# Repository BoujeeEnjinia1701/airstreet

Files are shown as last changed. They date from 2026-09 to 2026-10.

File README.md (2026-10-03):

# AirStreet

     

**Area:** Smart Cities · **TRL:** 3 of 9 (proof of concept on paper) · **Value-engineering target:** about $285 USD for the sensor head · **Difficulty:** 3 of 5

A street-level air quality node measuring PM2.5 and NO2, with particles checked on CalRig and NO2 calibrated against a reference station, for neighborhood-scale pollution maps.

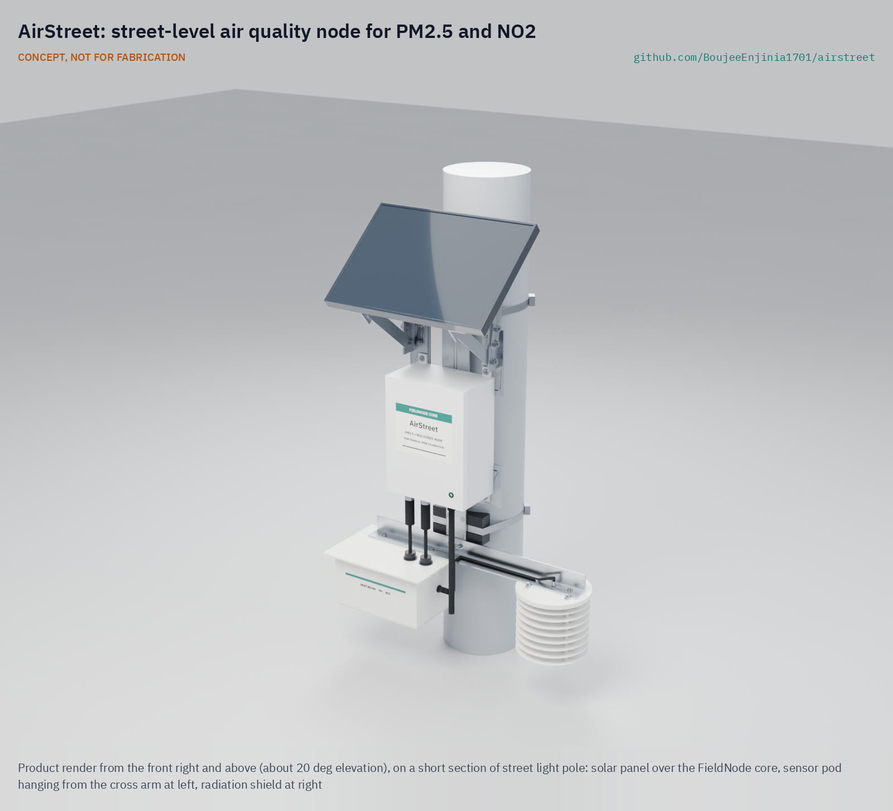
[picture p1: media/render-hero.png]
AirStreet: street-level air quality node for PM2.5 and NO2, product render


[Exploded render](media/render-exploded.png) · [Detail render](media/render-detail.png) · [Interactive 3D model](media/viewer.html) · [Concept blueprint (PDF)](media/concept-blueprint.pdf) · [General arrangement AST-DWG-001 (PDF)](cad/drawings/AST-DWG-001.pdf) · [Sizing calculations](docs/04-calcs/01-sizing.md) · [Prototype build plan](docs/05-build-plan.md) · [Design decisions](docs/06-design-decisions.md) · [Review note](docs/REVIEW.md)

## Concept rationale

Traffic pollution changes from one block to the next, so a map of it needs many measurement points at street level, each with a known calibration. AirStreet puts a small sensor pod and radiation shield under the lab's FieldNode solar core on a street light pole: an optical sensor for PM2.5, a four-electrode electrochemical sensor for NO2, and a shielded temperature and humidity sensor for corrections. Particle, temperature and humidity response are checked on CalRig. CalRig does not cover NO2, so each NO2 sensor is calibrated by field collocation with a reference station before deployment and at intervals afterward. The node sends raw signals so calibrations can be improved and reapplied.

It is open and garage-buildable because the places with the fewest official monitors are the least able to buy closed commercial networks and their subscriptions. The sensors are sold worldwide, the pod and shield are 3D-printed, the mount uses band clamps and flat bar, and the calibration method is published with the design so that others can check any map made with it.

## Burning platform

Air pollution is one of the largest environmental health risks worldwide. Ambient air pollution caused an estimated 4.2 million premature deaths in 2019 ([WHO](https://www.who.int/news-room/fact-sheets/detail/ambient-(outdoor)-air-quality-and-health)). Even in the European Union, with dense monitoring, 48,000 deaths in 2022 were attributable to NO2 above the WHO guideline level of 10 µg/m³ ([EEA, 2024](https://www.eea.europa.eu/en/analysis/publications/harm-to-human-health-from-air-pollution-2024)).

Monitoring misses the streets where exposure is highest. Reference-grade mapping in Oakland, California, found NO2 and black carbon varying by up to 5 to 8 times within single city blocks ([Apte et al., 2017](https://pubs.acs.org/doi/10.1021/acs.est.7b00891)), while monitoring is not legally required at all in at least 37 % of countries ([UNEP, 2021](https://www.unep.org/news-and-stories/press-release/one-three-countries-world-lack-any-legally-mandated-standards)).

## Where it could be used

### By industry

| Industry | Use |
| --- | --- |
| Municipal environment and transport | Before and after maps for low-traffic streets, school streets, bus corridors and clean air zones |
| Public health agencies | Street-level exposure data near schools, clinics and care homes, labeled as indicative |
| Street lighting and utilities | A light, self-powered add-on for existing poles that needs no pole wiring |
| Logistics and ports | Tracking NO2 and PM2.5 along freight routes and depot access roads |
| Universities and schools | Open, raw data and a documented calibration for teaching and exposure research |
| Community groups and NGOs | Evidence for local campaigns, with the calibration version stated on every map |

### By country or region

| Country or region | Why it matters there |
| --- | --- |
| United States | More than 45 million people live within about 90 m (300 ft) of a major transportation facility ([US EPA](https://www.epa.gov/air-research/research-near-roadway-and-other-near-source-air-pollution)); street-scale variation is well documented ([Apte et al., 2017](https://pubs.acs.org/doi/10.1021/acs.est.7b00891)) |
| European Union and United Kingdom | 48,000 deaths in the EU in 2022 were attributable to NO2 above the WHO guideline ([EEA, 2024](https://www.eea.europa.eu/en/analysis/publications/harm-to-human-health-from-air-pollution-2024)); dense reference stations make field collocation of NO2 practical |
| India | Only 12 % of 4,041 census cities and towns have air quality monitoring ([CSE, 2023](https://www.cseindia.org/only-12-per-cent-of-india-s-census-cities-and-towns-have-air-quality-monitoring-stations-11779)) |
| East Africa (Uganda, Kenya, Ethiopia, Tanzania) | Listed by OpenAQ in 2020 among populous countries with no public national monitoring program ([OpenAQ, 2020](https://documents.openaq.org/reports/Open+Air+Quality+Data+Global+State+of+Play+2020.pdf)); AirQo already runs more than 400 low-cost PM2.5 sensors across 14 African countries ([AirQo](https://www.airqo.net/)) |
| Pakistan and Nigeria | The two most populous countries on the same OpenAQ list, at about 221 million and 206 million people ([OpenAQ, 2020](https://documents.openaq.org/reports/Open+Air+Quality+Data+Global+State+of+Play+2020.pdf)); the first reference station for collocation may itself be scarce |

## What sparked the idea

The starting point was the inquest into the death of Ella Adoo Kissi-Debrah, a nine-year-old who lived near the busy South Circular Road in Lewisham, south-east London, and died in 2013. In December 2020 the coroner found that she died of asthma contributed to by exposure to excessive air pollution, and that nitrogen dioxide in Lewisham exceeded EU and UK legal limits ([CIEH, 2020](https://www.cieh.org/ehn/environmental-protection/2020/december/ella-adoo-kissi-debrah-verdict-shows-human-cost-of-air-pollution/)). His Prevention of Future Deaths report of 20 April 2021 also raised low public awareness of air quality information ([Courts and Tribunals Judiciary](https://www.judiciary.uk/prevention-of-future-death-reports/ella-kissi-debrah/); [IAQM](https://iaqm.co.uk/prevention-of-future-deaths-report-published-following-2013-death-of-ella-abdoo-kissi-debrah/)). The case turns on NO2 beside one busy road, which is the scale AirStreet is built to measure, and on making that information visible to the people who live there.

## Problem

Regulatory air monitors are few and far apart, missing the streets where people breathe traffic pollution. Full problem statement: [docs/01-problem.md](docs/01-problem.md).

## Concept

A street-level air quality node measuring PM2.5 and NO2, with particles checked on CalRig and NO2 calibrated against a reference station, for neighborhood-scale pollution maps. The sensor pod and radiation shield hang below a FieldNode core on a street light pole, with inlets 3.0 m above the sidewalk, and send one record every 5 min over LoRaWAN. PM, temperature and humidity are checked on CalRig; **NO2 is calibrated by field collocation with a reference station** for at least 14 days before deployment and at least every 6 months, because CalRig does not cover NO2.

Calculated performance (TRL 3, [AST-CAL-001](docs/04-calcs/01-sizing.md)): an 87 mW design sensor load with a 60 s particle run, within FieldNode's 100 mW design allowance, and 6.6 days without sun; records every 5 min through a private gateway and every 15 min on The Things Network; 0.60 % radio duty cycle even at SF12; hourly NO2 error of about 3.9 ppb and PM2.5 within ±5 µg/m³ or ±30 % up to 80 % RH. As made buildable for the prototype build plan, and lightened as decided on 2026-10-02 (40 x 4 mm rail, windows in the adapter plates, 1.5 mm shield plates, saddles at 40 % infill), the node weighs 3.62 kg and presents 0.139 m² to the street, and the sensor head costs $302.50 in parts ($433.50 with the FieldNode core). With FieldNode's sun shield the node weighs 3.78 kg, 0.22 kg under the 4.0 kg mass limit Amish set for R13 on 2026-10-02, and cost is $17.50 over the $285 value-engineering target (R15); both are covered in the [design decisions register](docs/06-design-decisions.md); five requirements are at risk. The annual NO2 uncertainty (about 4.2 µg/m³) is too large to resolve the WHO guideline of 10 µg/m³, so AirStreet ranks streets and checks the EU limit, and the WHO question is kept as research. Decisions are recorded in [AST-DDR-001](docs/decisions/0001-trl2-review-decisions.md), [AST-DDR-002](docs/decisions/0002-recommendations-accepted.md) and [AST-DDR-003](docs/decisions/0003-design-for-construction.md). Only pollutant levels, temperature and humidity leave the device; no images or audio.

Full design precis: [docs/02-concept.md](docs/02-concept.md). Requirements: [docs/03-requirements.md](docs/03-requirements.md).

## Key components

1. FieldNode core (enclosure, LiFePO4 cell, MPPT charger, LoRaWAN radio), on two adapter plates in place of its back plate
2. FieldNode 6 W panel hood
3. Bands, V-saddles, mounting rail, adapter plates and cross arm (no drilling)
4. Sensor pod (shell with drip lid, sensor floor, insect mesh), exchanged whole for service
5. Optical PM2.5 sensor (Sensirion SPS30 class)
6. Electrochemical NO2 sensor (Alphasense NO2-B43F class, ozone filtered)
7. NO2 potentiostat front end and 16-bit ADC
8. Multi-plate radiation shield
9. Temperature and humidity sensor (Sensirion SHT45 class)
10. Sensor cables with M12 plugs (0.5 m)

The priced bill of materials is in [bom/bom.csv](bom/bom.csv); the parametric model is `cad/src/model.py`, with STEP and STL exports in `cad/step/` and `cad/stl/`.

## Building the prototype

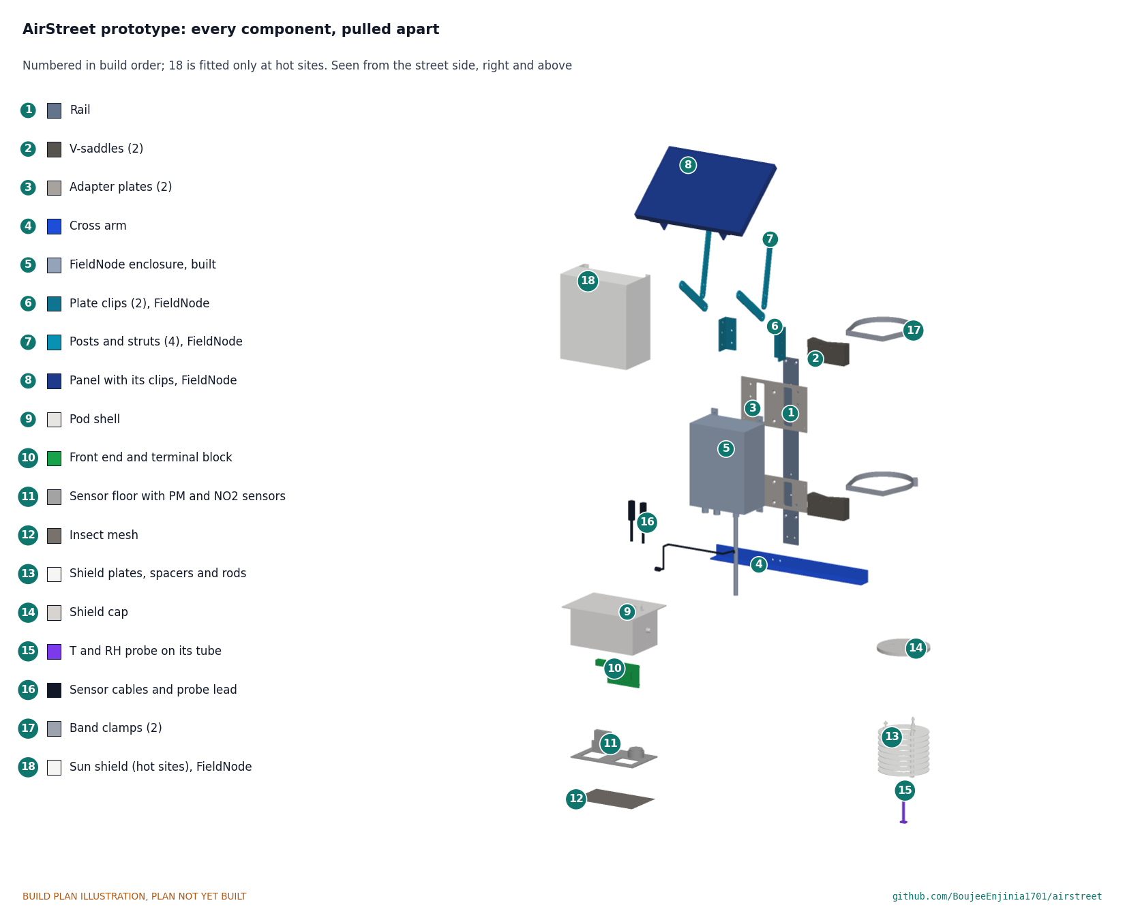
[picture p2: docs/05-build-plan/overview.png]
AirStreet prototype: every component pulled apart and numbered in build order


The [prototype build plan](docs/05-build-plan.md) (AST-BLD-001) shows, in pictures, how to make each of the eighteen components and put them together in sixteen steps; nothing has been built yet. The made parts are an aluminium rail, two adapter plates and a cross arm, and printed V-saddles, pod shell, sensor floor, shield plates and cap; the FieldNode core is built to FieldNode's own plan, and the sensors and front end are bought boards wired at block level. Writing the plan made the design buildable: the saddles, band path, enclosure fixing, pod, shield stack and cable entries were redesigned (AST-DDR-003, accepted by Amish on 2026-10-02), which raised the mass to its 4.0 kg limit and the cost above its value-engineering target; those choices are in the [design decisions register](docs/06-design-decisions.md). Every picture is drawn from the model, which checks that each part touches what it should and clears what it should not.

## Safety

> **Safety:** Street furniture and pole mounts must be installed only with the asset owner's permission, by trained crews, with fall protection and traffic management as local rules require. Never open a street light pole's access door or tap its mains supply; AirStreet runs only on its own solar and battery supply.
>
> The FieldNode core holds a lithium iron phosphate cell: fuse it and charge only within the maker's limits. Electrochemical gas sensors contain an acid electrolyte; do not open or heat them. AirStreet data are indicative, not a regulatory measurement or health advice.

## Repository layout

| Folder | Contents |
| --- | --- |
| `docs/` | Problem, concept, requirements, calculations and design decisions |
| `cad/src/` | build123d Python source, the source of truth for all geometry |
| `cad/step/`, `cad/stl/` | Exported models for FreeCAD, other CAD tools and printing |
| `cad/drawings/` | 2D sketches and dimensioned drawings |
| `bom/` | Bill of materials |
| `electronics/` | KiCad schematics and PCB layouts |
| `firmware/` | Microcontroller code |
| `media/` | Renders, perspectives and photos |
| `build-log/` | Dated prototyping notes |

## Documentation

Controlled documents follow the portfolio [documentation standard](.kit/STANDARDS.md). Each carries a document ID (AST-PRC-001 for the precis), a version and a revision history. Branded PDFs are built with `python .kit/render.py` and attached to GitHub Releases when a document is tagged, for example `AST-PRC-001/v1.0`.

## Credits

Designed by Amish Chadha. See [CONTRIBUTORS.md](CONTRIBUTORS.md) for roles. To cite this design, use [CITATION.cff](CITATION.cff) (GitHub shows it as "Cite this repository").

AI assistance (Claude) was used to accelerate concept renders, prototype documentation and first-pass sizing calculations. Design direction and all decisions are Amish Chadha's, recorded in this repository's decision records (`docs/decisions/`).

## Licenses

- **Hardware** (CAD, drawings, BOM, electronics): [CERN-OHL-S v2](LICENSE)
- **Software** (firmware, scripts, notebooks): [MIT](LICENSE-SOFTWARE)

A project of the [Design Molecule](https://designmolecule.com) lab.

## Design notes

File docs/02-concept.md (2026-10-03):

---
doc_id: AST-PRC-001
title: AirStreet design precis
project: AirStreet
doc_type: Design precis
version: "0.8"
status: Draft
date: '2026-10-02'
author: Amish Chadha
license: CERN-OHL-S-2.0
revisions:
- version: "0.1"
  date: '2026-09-25'
  author: Amish Chadha
  change: Initial scaffold
- version: "0.2"
  date: '2026-09-25'
  author: Amish Chadha
  change: Populate to TRL 2 (architecture, components, calibration route, first-order numbers, safety)
- version: "0.3"
  date: '2026-09-25'
  author: Amish Chadha
  change: TRL 3 update from AST-CAL-001, the parametric model and AST-DWG-001; design choices adopted for TRL 3 work per AST-DDR-001, open for Amish's review
- version: "0.4"
  date: '2026-09-25'
  author: Amish Chadha
  change: Recommendations accepted by Amish (DDR-002)
- version: "0.5"
  date: '2026-09-30'
  author: Amish Chadha
  change: Design made constructable (AST-DDR-003); mount, pod, shield, mass, area and cost figures updated
- version: "0.6"
  date: '2026-10-01'
  author: Amish Chadha
  change: Budget treated as a value-engineering target
- version: "0.7"
  date: '2026-10-02'
  author: Amish Chadha
  change: "Decisions of 2026-10-02: R13 limit 4.0 kg with the sun shield; first partner rule and first candidate; radio band follows the partner"
- version: "0.8"
  date: '2026-10-02'
  author: Amish Chadha
  change: "Lightening steps of AST-DDR-003 A1 carried into the design (AST-CAL-001 v0.6): 40 x 4 mm rail, plate windows, 1.5 mm shield plates, saddles at 40 % infill; R13 met on paper; mass, area, wind, shield and cost figures updated"
---

# AirStreet design precis

## Summary

AirStreet is a pole-mounted node that measures PM2.5 and NO2 at street level for neighborhood-scale pollution maps. A small sensor pod and a radiation shield hang below a FieldNode core on a street light pole, with the inlet plane 3.0 m above the sidewalk. Temperature, humidity and particle readings are checked on CalRig. CalRig does not cover NO2, so each NO2 sensor is calibrated by field collocation with a reference station before deployment and at intervals afterward. The node sends raw signals, so calibrations can be improved and reapplied later. Amish accepted the recommended design choices on 2026-09-25 ([AST-DDR-001](decisions/0001-trl2-review-decisions.md), [AST-DDR-002](decisions/0002-recommendations-accepted.md)).

The TRL 3 calculations ([AST-CAL-001](04-calcs/01-sizing.md) v0.6) confirm the power and radio budget: an 87.0 mW design sensor load with a 60 s particle run, inside FieldNode's 100 mW design allowance, 6.6 days without sun, and 0.60 % duty cycle even at SF12. On 2026-09-30 the design was made constructable ([AST-DDR-003](decisions/0003-design-for-construction.md)) and an illustrated prototype build plan was written ([AST-BLD-001](05-build-plan.md)). With the four lightening steps accepted on 2026-10-02 (a 40 x 4 mm rail, windows in the adapter plates, 1.5 mm shield plates and saddles printed at 40 % infill), the buildable node weighs 3.62 kg and presents 0.139 m² to the street, which meets its 0.15 m² area limit; with FieldNode's sun shield it weighs 3.78 kg, 0.22 kg under the 4.0 kg limit that Amish set for R13 on 2026-10-02 (it was 3.5 kg), so R13 is met on paper; the pole owner is still to confirm the load. Value-engineering target: USD 285. Estimated cost of the constructable design: USD 302.50 (USD 17.50 over the target) for the sensor head (R15). Decisions are recorded in the design decisions register ([AST-DEC-001](06-design-decisions.md)). The node costs $433.50 with the FieldNode core. Resolving NO2 at the WHO guideline of 10 µg/m³ is no longer a requirement: an annual mean carries about 4.2 µg/m³ of uncertainty, so AirStreet ranks streets and checks the EU limit, and the WHO question stays open as research.

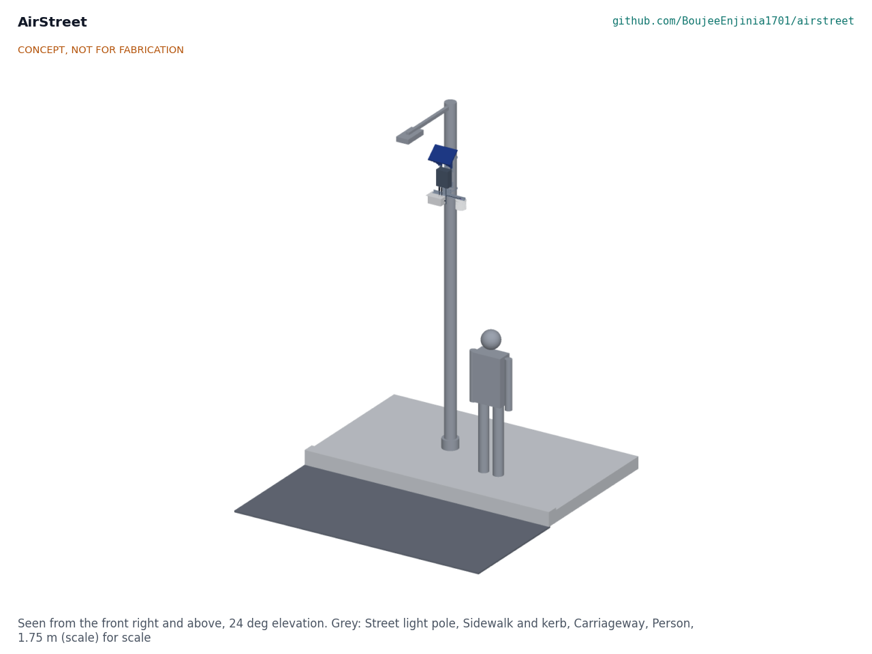
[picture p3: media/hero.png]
Figure 1. AirStreet on a street light pole, with a 1.75 m person for scale.


Figure 1. AirStreet on a street light pole, with a 1.75 m person for scale (concept, not for fabrication).

## How it works

1. Street air enters the sensor pod from below, through stainless insect mesh under an overhanging drip lid. Downward-facing inlets keep rain and direct sun out.
2. An optical particle sensor draws a sample with its own fan for 60 s every 5 min and counts particles by laser scattering, giving PM1, PM2.5 and PM10. The SPS30 needs 8 to 30 s to its first reading, depending on particle count, so the 60 s run leaves at least 30 s of valid readings to average even in clean air (AST-DDR-002).
3. A four-electrode electrochemical NO2 sensor with an ozone filter faces down through a slot in the pod floor. Its working electrode (WE) responds to NO2, and its auxiliary electrode (AE) tracks the temperature-driven baseline. A potentiostat front end holds the bias continuously, and a 16-bit ADC reads both signals.
4. A temperature and humidity sensor sits inside a white multi-plate radiation shield beside the pod, so readings reflect air temperature rather than sun-heated plastic. These values drive the humidity correction for PM and the temperature correction for NO2.
5. Two short cables with M12 plugs run up to FieldNode's two sensor ports. Port A, on a switched 5 V rail, carries the PM sensor and the temperature and humidity sensor on one I2C bus and is powered only during each PM run. Port B carries the NO2 front end on a 5 V rail that stays on, because the sensor bias must be held continuously. FieldNode provides power, storage and a LoRaWAN radio, and its 6 W panel shades the enclosure.
6. Every 5 min through a private gateway (the TwinKit gateway by default), or every 15 min on The Things Network, the node sends one record of 20 bytes: raw PM values, raw WE and AE voltages, temperature, humidity, a status word, a counter and flags. It never sends images, audio or identifiers of people.
7. A server-side calibration model converts raw values to PM2.5 and NO2 concentrations. Each model is versioned and linked to the node's CalRig record and its collocation record, so any map can be traced to the calibration behind it.

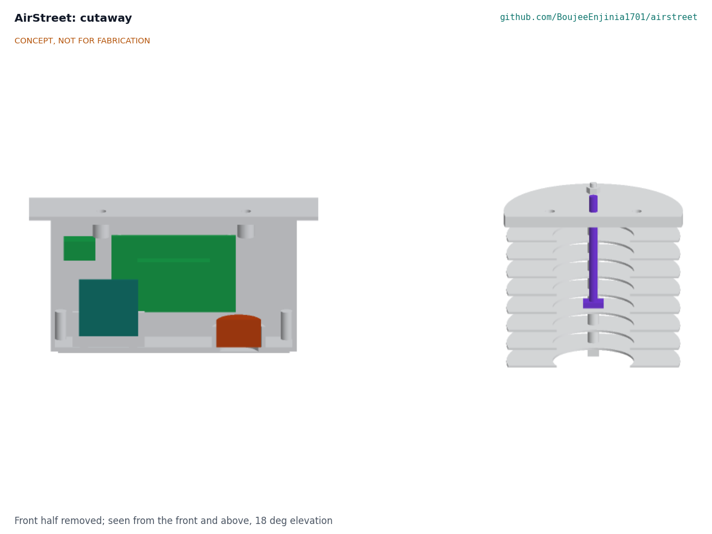
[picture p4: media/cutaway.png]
Figure 2. Cutaway of the sensor pod and radiation shield.


Figure 2. Cutaway of the sensor pod (PM sensor, NO2 sensor and front end) and the radiation shield.

## Main components

Item numbers match the BOM ([bom/bom.csv](../bom/bom.csv)), the exploded view (Figure 3) and the parametric model `cad/src/model.py`. The general arrangement is drawing AST-DWG-001 (`cad/drawings/`).

Table 1. Main components.

| No. | Component | Key choice (decided by Amish, 2026-09-25) |
| --- | --- | --- |
| 1 | FieldNode core | Shared lab core per FND: IP65 enclosure 150 x 90 x 200 mm, LiFePO4 cell, MPPT charger, STM32WL LoRaWAN, two M12 5-pin sensor ports; the enclosure, built to FieldNode's constructable design, fixes by its four lugs to two adapter plates on the AirStreet rail, and FieldNode's back plate, V-blocks and 40 to 60 mm clamps are not used (DDR-002, DDR-003); FieldNode's sun shield is fitted at sites above 45 °C |
| 2 | FieldNode 6 W panel hood | Part of FieldNode; 40° tilt toward the street side as a sun and rain hood |
| 3 | Band clamps and mounting rail | Two 12.7 mm stainless bands cut to length, 375 mm apart, each running in a groove behind a printed 140° V-saddle that seats 80 to 200 mm poles; 40 x 4 mm aluminium rail 451 mm long; two 3 mm aluminium adapter plates with FieldNode's back plate hole pattern and lightening windows; a 30 x 30 x 3 mm cross arm that carries the pod and the shield (DDR-002, DDR-003); no drilling |
| 4 | Sensor pod | Printed ASA shell with walls, roof and 200 x 140 mm drip lid in one, 170 x 110 x 95 mm with its sensor floor, which carries both sensors and closes the pod from below behind mesh; hung under the cross arm 90 mm to one side so the FieldNode whip hangs beside it with 15 mm clearance; the pod with its sensors and front end is the service exchange unit (DDR-002) |
| 5 | Optical PM sensor | Sensirion SPS30 (D6); the maker states a lifetime of more than ten years ([Sensirion](https://sensirion.com/products/catalog/SPS30)) |
| 6 | Electrochemical NO2 sensor | Alphasense NO2-B43F class (D4): four electrodes and an ozone filter; replace about every 2 years (estimate) |
| 7 | NO2 front end and ADC | Alphasense ISB class potentiostat bought for the first units (D5), with an ADS1115 class 16-bit ADC |
| 8 | Radiation shield | Eight white 120 mm plates at 13 mm pitch on three rods with spacers, 124 mm cap screwed under the cross arm, naturally ventilated |
| 9 | Temperature and humidity sensor | Sensirion SHT45 on a probe board, hung in the shield on a 6 mm tube |
| 10 | Sensor cables | Two 0.5 m shielded cables with M12 plugs into glands in the pod roof; probe lead with an M8 plug for the pod wall |
| 11 | Fasteners and consumables | Not modeled |

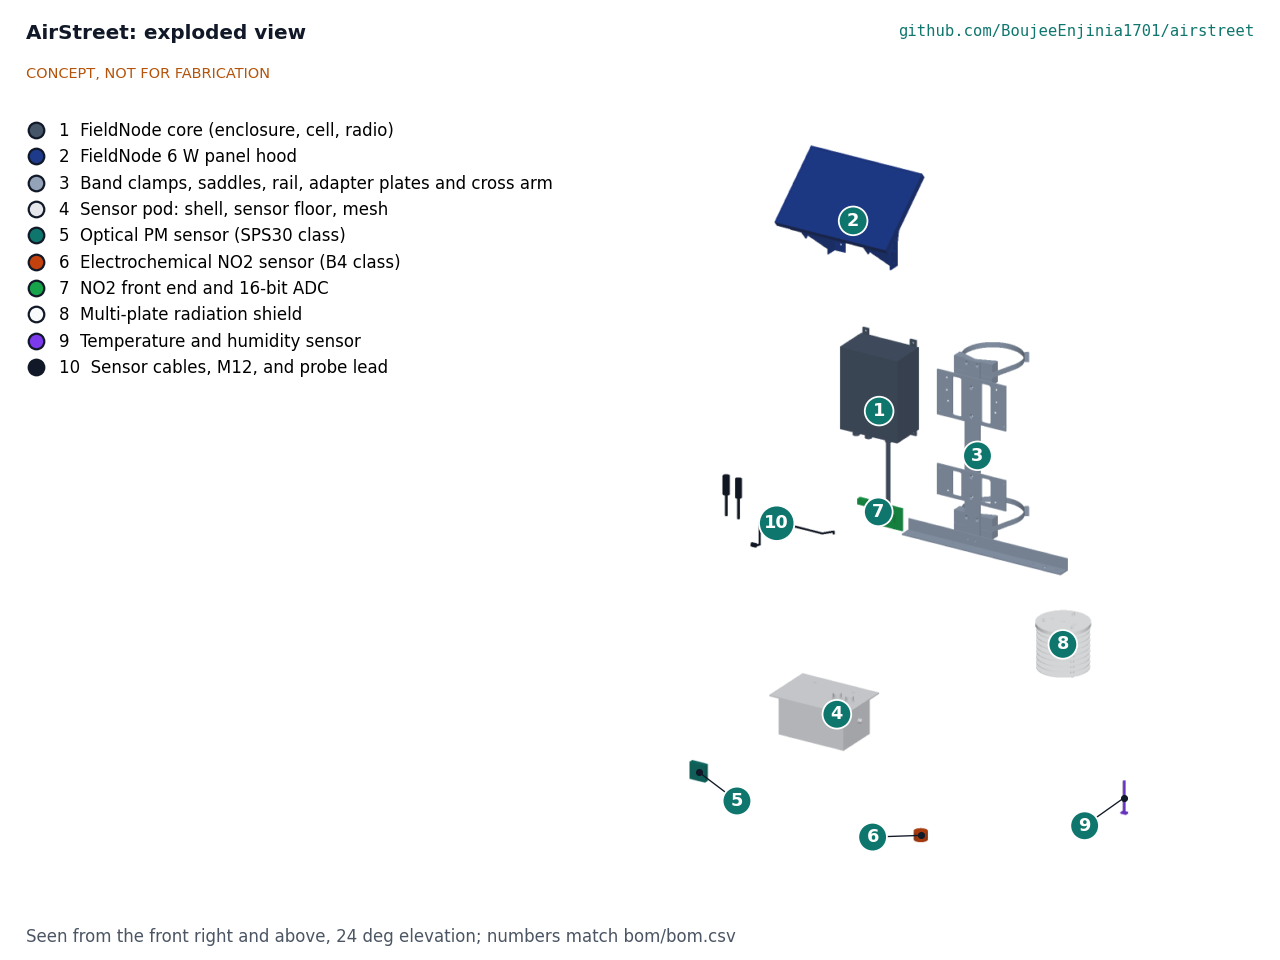
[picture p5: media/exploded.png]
Figure 3. Exploded view with BOM numbers.


Figure 3. Exploded view with BOM numbers.

## Key design choices

Amish accepted every recommendation below on 2026-09-25 (AST-DDR-001 D1 to D9 and AST-DDR-002). Purchasing, collocation and publication of data are TRL 4 and later work and are on hold.

- **Build on FieldNode.** AirStreet designs only the sensor head, its mount and the calibration route. Power, radio and enclosure fixes found in other deployments carry over. The FieldNode core is costed in FieldNode, and AirStreet's value-engineering target covers the sensor head (D1).
- **Two calibration routes, stated plainly.** CalRig checks temperature, humidity and particle response in a chamber. NO2 is calibrated by field collocation with a regulatory reference station (chemiluminescence), because field calibration corrects temperature, humidity and cross-sensitivity effects that laboratory calibration misses ([Zimmerman et al., 2018](https://amt.copernicus.org/articles/11/291/2018/)). This follows the approach of the US EPA NO2 sensor protocols, which include field evaluation alongside regulatory monitors ([US EPA](https://www.epa.gov/air-sensor-toolbox/air-sensor-performance-targets-and-testing-protocols)).
- **Collocation plan (D3).** Each node sits beside a reference station for at least 14 days before deployment, covering a range of temperature, humidity and NO2. At least one anchor node stays at the reference site permanently to track seasonal drift, and every node returns for collocation at least every 6 months. The first model is a multiple linear regression on WE, AE, temperature and humidity, with a random forest model as an option once enough data exist.
- **Send raw signals (D8).** Raw WE and AE voltages and raw PM values let the city or community reprocess data when a better model or a new collocation becomes available.
- **Four-electrode NO2 sensor with ozone filter (D4).** The auxiliary electrode helps remove the temperature-driven baseline, and the filter reduces ozone interference.
- **Duty-cycled PM sensor (D8, run length per DDR-002).** Running the particle sensor for 60 s every 5 min gives a valid reading even in clean air, keeps its average draw near 55 mW and slows fouling.
- **Reporting by network (DDR-002).** 5 min records through the private TwinKit gateway; 15 min on The Things Network, which keeps within its 30 s/day fair-use policy up to SF9.
- **Pod exchange for service (DDR-002).** The whole pod, pre-collocated at the reference site, is exchanged at the pole; sensors are never swapped at height.
- **No FieldNode back plate (DDR-002).** The FieldNode enclosure and its panel bracket fix to two adapter plates on the AirStreet rail (AST-DDR-003), saving about 0.15 kg against FieldNode's back plate. This changes the FieldNode mounting interface and needs FieldNode's agreement.
- **Hot sites (DDR-002).** FieldNode's sun shield is required at any site where ambient temperature exceeds 45 °C.
- **WHO guideline as research (DDR-002).** AirStreet ranks streets and checks the EU limit; it makes no claim about the WHO annual guideline for NO2.
- **Inlets 3.0 m above the sidewalk (D7).** This is within the 1.5 to 4 m inlet range in EU Directive 2008/50/EC ([EUR-Lex](https://eur-lex.europa.eu/legal-content/EN/TXT/HTML/?uri=CELEX:32008L0050)) and out of easy reach.
- **Open data (D9).** Calibrated hourly data, with the calibration version, are published to an open platform such as OpenAQ, subject to the partner's agreement.

## Key numbers (TRL 3)

All values come from AST-CAL-001, which lists every assumption.

Table 2. Key numbers.

| Quantity | Value | Note |
| --- | --- | --- |
| PM sensor average power | 55.0 mW typical, 65.0 mW maximum | SPS30 55 mA typical, 65 mA maximum at 5 V (datasheet), 60 s in every 300 s |
| NO2 front end and ADC | 7.5 mW | 1.5 mA at 5 V held continuously (assumed) |
| Design sensor load | 87.0 mW | Maximum SPS30 current and 1.2 margin; FieldNode allows 100 mW (design) or 115 mW (ceiling) (R9 met on paper) |
| Daily draw and autonomy | 2.33 Wh/day; 6.6 days without sun | 4.6 days at -20 °C; 7.75 Wh stored in FieldNode's worst month |
| Payload and airtime | 20 bytes every 5 min (15 min on TTN); 247 ms at SF9, 1.81 s at SF12 | 0.082 % and 0.60 % duty cycle (R10 met on paper); at 15 min, TTN's 30 s/day fair use is met up to SF9 (23.7 s/day) |
| NO2 hourly error | About 3.9 ppb MAE (7.4 µg/m³) | Budget of literature and assumed terms (R2 at risk) |
| NO2 annual uncertainty | About 4.2 µg/m³ (1σ) | Too large to resolve the 10 µg/m³ WHO guideline; R3 withdrawn and kept as a research question |
| EU limit classification | Decisive below 34.6 or above 45.4 µg/m³ | 90 % confidence against 40 µg/m³ (R4 at risk) |
| PM2.5 hourly error | Within ±5 µg/m³ or ±30 % up to 80 % RH | Outside the bound at 85 % RH and above (R1 at risk) |
| Shield radiation error | 0.42 to 0.87 K at 1 m/s | Reads up to 4.1 % RH low at 85 % RH (R5 at risk) |
| Mass on the pole | 3.62 kg | FieldNode 1.89 kg as used (no back plate), sensor head and mount 1.73 kg, with the four lightening steps (3.78 kg with the sun shield against the 4.0 kg R13 limit set on 2026-10-02; R13 met on paper, AST-DDR-003 A1) |
| Frontal area | 0.139 m² | Rasterized from the model; limit 0.15 m² (met on paper) |
| Wind at 35 m/s | 125 N, 416 N·m at the pole base | Clamp slip factor 25; the pole check is the owner's |
| Parts cost | Sensor head $302.50; $433.50 with the FieldNode core | $17.50 over the $285 value-engineering target (`budget_usd`; R15 over the target) |
| Service | About 14 min for a pod exchange | Against 15 min (R16 met on paper) |

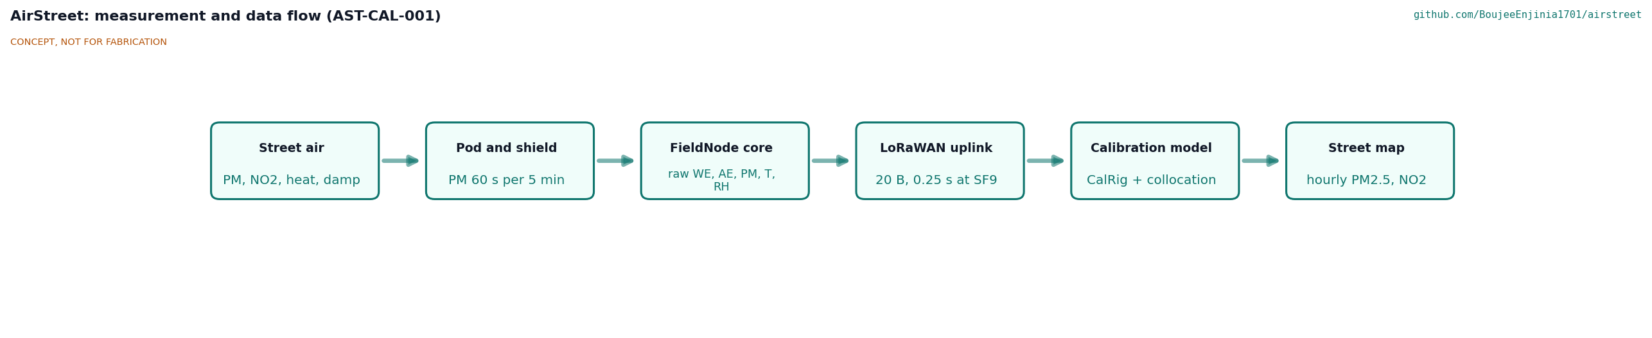
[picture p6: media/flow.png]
Figure 4. Measurement and data flow.


Figure 4. Measurement and data flow.

## Safety

> **Safety:** Mounting on a street pole is work at height next to traffic. Install only with the pole owner's written permission, by trained crews using a mobile elevating work platform or a secured ladder with a second person, with traffic management as local rules require. The node adds about 125 N of wind load and about 416 N·m at the pole base in a 35 m/s gust, and up to 4.0 kg of weight; the pole owner must confirm the pole can carry it.

> **Safety:** Street light poles carry mains voltage inside. Never open the pole's access door or tap pole power; AirStreet runs only on its own solar and battery supply.

> **Safety:** The FieldNode core holds a lithium iron phosphate cell. Use a fused, protected cell, charge only within the maker's temperature limits and replace any swollen or damaged cell. FieldNode is rated for ambient temperatures up to 45 °C; hotter sites must have FieldNode's sun shield fitted (AST-DDR-002).

> **Safety:** Electrochemical gas sensors contain an acid electrolyte. Do not open, crush or heat them; dispose of them as the maker directs. Band clamp ends and cut flat bar have sharp edges; deburr them and wear gloves. Band clamps rely on their preload; installers need a torque figure before any field use.

> **Safety:** AirStreet data are indicative and are not a regulatory measurement or health advice. Maps must state the calibration version and its uncertainty.

## Open questions

- [ ] Which city, partner and reference station host the first collocation? Decided on 2026-10-02 as a rule: a city or air agency that runs a regulatory NO2 reference station at a street-level site AirStreet can mount beside, and that will share its data. First candidate to approach: the Texas Commission on Environmental Quality's Dallas-Fort Worth monitoring network, with a local university or city partner; nothing is agreed yet. The partner's country sets the radio band (US915 in North America, EU868 in Europe).
- [ ] Is the NO2 error after field calibration stable across seasons, and how large is the reference-to-street transfer bias in practice?
- [ ] How fast does air move inside the shield in low wind, and so how large is the radiation error?
- [ ] Does the SPS30 need a heated or dried inlet above 85 % RH, or is a humidity flag on the data enough?
- [ ] Will FieldNode accept its enclosure, plate clips and sun shield on AirStreet's two adapter plates in place of its back plate? (Decided in AirStreet, AST-DDR-002 and AST-DDR-003; on 2026-10-02 Amish approved sending FieldNode the request; FieldNode's agreement is outstanding.)
- [ ] Can the NO2 annual mean ever be resolved at the WHO guideline, for example with an anchor node at every site? (Research question, AST-DDR-002.)
- [ ] Is an open two-channel front end at about $25 worth designing, to restore cost margin? (On hold with TRL 4.)
- [ ] How are nodes secured against theft, and what does the pole owner require for insurance and inspection?

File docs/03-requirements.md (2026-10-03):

---
doc_id: AST-REQ-001
title: AirStreet requirements
project: AirStreet
doc_type: Requirements
version: "0.8"
status: Draft
date: '2026-10-02'
author: Amish Chadha
license: CERN-OHL-S-2.0
revisions:
- version: "0.1"
  date: '2026-09-25'
  author: Amish Chadha
  change: Initial scaffold
- version: "0.2"
  date: '2026-09-25'
  author: Amish Chadha
  change: First measurable requirements for TRL 2, with status against the concept
- version: "0.3"
  date: '2026-09-25'
  author: Amish Chadha
  change: TRL 3 status from AST-CAL-001; R15 redefined as the sensor-head cost (AST-DDR-001 D1); R6, R8 and R11 rest on adopted choices
- version: "0.4"
  date: '2026-09-25'
  author: Amish Chadha
  change: Recommendations accepted by Amish (DDR-002)
- version: "0.5"
  date: '2026-09-30'
  author: Amish Chadha
  change: Status from AST-CAL-001 v0.3 after the design was made constructable (AST-DDR-003); R13 and R15 not met, proposed to Amish
- version: "0.6"
  date: '2026-10-01'
  author: Amish Chadha
  change: Budget treated as a value-engineering target
- version: "0.7"
  date: '2026-10-02'
  author: Amish Chadha
  change: "R13 mass limit set at 4.0 kg including FieldNode's sun shield (AST-DDR-003 A1, accepted 2026-10-02); R13 now at risk"
- version: "0.8"
  date: '2026-10-02'
  author: Amish Chadha
  change: "Status from AST-CAL-001 v0.6 with the four lightening steps carried into the design: R13 at risk to met on paper (3.78 kg with the sun shield); R15 over the target by $17.50; R5 figures updated"
---

# AirStreet requirements

These requirements are checked by calculation in [AST-CAL-001](04-calcs/01-sizing.md) v0.6. Targets remain proposals for review with the first co-design partner. On 2026-09-25 Amish accepted the recommendations in [AST-DDR-001](decisions/0001-trl2-review-decisions.md) and [AST-DDR-002](decisions/0002-recommendations-accepted.md). As a result R3 is withdrawn and kept as a research question, R8, R12, R13, R15 and R16 are restated, and R15 uses the $285 `budget_usd`. On 2026-09-30 the design was made constructable ([AST-DDR-003](decisions/0003-design-for-construction.md)), which raised the mass and the sensor-head cost: R15 (cost) is **over the value-engineering target**, now by $17.50. On 2026-10-02 Amish accepted the design for construction and set R13's mass limit at 4.0 kg including FieldNode's sun shield (AST-DEC-001, decision of 2026-10-02 on mass), with the four lightening steps carried into the design. With them the node weighs 3.78 kg with the sun shield, so R13 is met on paper with 0.22 kg of margin (it was at risk, on its limit, before the lightening). Five are at risk, five are met on paper, four are met by design, one is over the value-engineering target and one is withdrawn.

Table 1. Requirements.

| ID | Requirement | Target | Verification (TRL 3 or later) | Status at TRL 3 (AST-CAL-001) |
| --- | --- | --- | --- | --- |
| R1 | Measure PM2.5 at street level | 0 to 500 µg/m³; hourly mean after humidity correction within ±5 µg/m³ or ±30 % (whichever is larger) of a collocated reference | CalRig chamber check, then field collocation | At risk: within the bound up to 80 % RH; outside it above 85 % RH, where water uptake makes the correction uncertain (AST-CAL-001 E) |
| R2 | Measure NO2 at street level | 0 to 200 ppb (about 0 to 380 µg/m³); hourly mean absolute error 5 ppb or less against a reference station after field calibration | Field collocation with a chemiluminescence reference station | At risk: hourly MAE about 3.9 ppb from a budget of literature and assumed terms (AST-CAL-001 C) |
| R3 | Resolve NO2 near the WHO annual guideline | Withdrawn as a requirement (AST-DDR-002). Kept as a research question: can the annual mean be resolved to 2 µg/m³ at 10 µg/m³? | Collocation statistics (research) | Withdrawn. Annual uncertainty about 4.2 µg/m³ (1σ); AirStreet ranks streets and checks the EU limit (R4) and makes no WHO guideline claim |
| R4 | Distinguish streets that exceed the EU NO2 limit value | Classify annual means above or below 40 µg/m³ with 90 % confidence | Collocation statistics | At risk: decisive only for annual means below 34.6 or above 45.4 µg/m³ |
| R5 | Measure temperature and humidity for corrections | ±0.5 °C and ±3 % RH inside the shield; radiation error 1 °C or less in full sun at 1 m/s wind | CalRig chamber check; side-by-side field test against an aspirated reference | At risk: SHT45 meets the sensor figures; shield error 0.42 to 0.87 K at 1 m/s, which reads 4.1 % RH low at 85 % RH |
| R6 | Calibrate with a stated method | T, RH and PM checked on CalRig before deployment; NO2 collocated with a reference station for at least 14 days before deployment and at least every 6 months | Calibration record per node | Met by design (AST-DDR-001 D3) |
| R7 | Keep raw data for recalibration | Send raw NO2 working and auxiliary electrode signals, PM, T and RH with a calibration version tag | Firmware and data schema review | Met by design |
| R8 | Report often enough for street maps | One record every 5 min through a private gateway (TwinKit by default); one every 15 min on The Things Network; hourly means published within 15 min; 7 days of store and forward | Timing, airtime and storage calculation | Met on paper: 5 min records on the private gateway; at 15 min TTN fair use is met up to SF9; 7 days in 40.3 kB |
| R9 | Fit the FieldNode power budget | Sensor average 115 mW or less; energy neutral at the FieldNode design sun hours | Power budget calculation | Met on paper: 87.0 mW design load with the 60 s PM run; 2.33 Wh/day drawn against 7.75 Wh stored in the worst month; 6.6 days without sun |
| R10 | Stay within radio duty-cycle rules | LoRaWAN airtime below 1 % in EU868 sub-bands | Airtime calculation | Met on paper: 0.082 % at SF9, 0.60 % at SF12 |
| R11 | Mount on street poles without drilling | Poles 80 to 200 mm diameter; band clamps only; inlets between 1.5 and 4 m above ground | Design review | Met by design (inlet 3.0 m, AST-DDR-001 D7; 140° V-saddles and bands cut to length fit the range, AST-DDR-003) |
| R12 | Survive outdoors | Pod inlets face down behind insect mesh with drip lid; electronics in the FieldNode IP65 enclosure; -10 to 50 °C, with FieldNode's sun shield required at sites where ambient exceeds 45 °C | Design review, later field trial | At risk: the FieldNode sun shield is now designed (FND-DDR-003) and fixes to AirStreet's adapter plates (AST-DDR-003); SPS30 recommended range 20 to 80 % RH; condensation and insects unverified |
| R13 | Light and compact on the pole | Mass 4.0 kg or less including FieldNode's sun shield (relaxed from 3.5 kg, AST-DDR-003 A1, 2026-10-02; the pole owner is asked to confirm the load); frontal area 0.15 m² or less (relaxed from 0.12 m², AST-DDR-002) | Constructable model; weighing at TRL 4 | Met on paper: 3.78 kg with FieldNode's sun shield (3.62 kg without) against 4.0 kg, 0.22 kg margin, with the four lightening steps in the design; frontal area 0.139 m²; the pole owner's confirmation of the load is still to come |
| R14 | Collect levels only | No images, audio or personal identifiers collected or sent | Design review | Met by design |
| R15 | Low cost | AirStreet sensor-head parts at or under the $285 value-engineering target per node (`budget_usd`, a hypothetical control target); FieldNode core excluded and costed in FieldNode | Priced BOM (AST-CAL-001 I) | **Over the value-engineering target by $17.50**: sensor head $302.50; $433.50 with the FieldNode core (AST-DDR-003) |
| R16 | Serviceable in the field | Pre-collocated sensor pod exchanged in 15 min at the pole with hand tools; no sensor-level swaps at the pole (AST-DDR-002) | Design review | Met on paper: about 14 min for a pod exchange; the exchanged pod is serviced and recollocated at the reference site |

## Assumptions

- NO2 conversions use 1 ppb = 1.88 µg/m³ at 25 °C and 101.325 kPa.
- The WHO guideline level for annual NO2 is 10 µg/m³ and for PM2.5 is 5 µg/m³, as cited by the European Environment Agency ([EEA, 2024](https://www.eea.europa.eu/en/analysis/publications/harm-to-human-health-from-air-pollution-2024)). The EU annual limit value for NO2 is 40 µg/m³ under Directive 2008/50/EC, which also sets sampling inlets between 1.5 m and 4 m above ground ([EUR-Lex](https://eur-lex.europa.eu/legal-content/EN/TXT/HTML/?uri=CELEX:32008L0050)).
- FieldNode allows 115 mW average for sensors at its 5-day autonomy ceiling, with 100 mW proposed as its published design value (FND-CAL-001); AirStreet fits either.
- `budget_usd` in `project.yaml` is $285 for the sensor head (AST-DDR-002).
- R1 and R2 targets are proposals for review, set with reference to published field results; they are not taken from a standard.

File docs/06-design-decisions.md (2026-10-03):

---
doc_id: AST-DEC-001
title: AirStreet design decisions register
project: AirStreet
doc_type: Design decisions register
version: "0.4"
status: Draft
date: '2026-10-02'
author: Amish Chadha
license: CERN-OHL-S-2.0
revisions:
- version: "0.1"
  date: '2026-09-30'
  author: Amish Chadha
  change: Register opened with the open decisions from REVIEW.md, the decision records and the build plan work
- version: "0.2"
  date: '2026-10-01'
  author: Amish Chadha
  change: Budget treated as a value-engineering target
- version: "0.3"
  date: '2026-10-02'
  author: Amish Chadha
  change: "Amish approved the recommendations for open decisions 1 to 8 (2026-10-02); moved to decisions made (AST-DDR-003 accepted)"
- version: "0.4"
  date: '2026-10-02'
  author: Amish Chadha
  change: "Value engineering restated after the A1 lightening (USD 302.50, USD 17.50 over); actions that carry the 2026-10-02 decisions outside the design listed"
---

# AirStreet design decisions register

Every design decision still to be made, and every decision made, in one place. Each decision is argued in full in its decision record under `docs/decisions/`; this register is the index Amish works from. The build plan (`docs/05-build-plan.md`) describes the design as it stands and does not list open decisions.

## Open decisions

None. All open decisions were decided on 2026-10-02.

## To confirm when parts are bought

| # | What to confirm | Why it matters | Source |
| --- | --- | --- | --- |
| 1 | The band roll and housings close round both an 80 mm and a 200 mm pole with the saddle, and the band maker's torque for about 1,000 N of preload | The slip and twist checks assume 1,000 N per band | AST-CAL-001 [F7], [G2] |
| 2 | The NO2 front end board's size and mounting holes (model: 86 x 55 mm, holes 76 x 43 mm apart) and how the B4 sensor connects to it | They set the back wall bosses and the lead length to the sensor | AST-DDR-003, P8 |
| 3 | The particle sensor's interface select pin and logic levels on its datasheet | Sets the terminal block wiring | Build plan section 3.10 |
| 4 | Heat-set insert sizes (M5 and M3) and the hole size their maker gives | The printed holes are drawn 6.8 and 4.0 mm | AST-DWG-102, 106, 109 |
| 5 | The M8 4-pin socket's panel hole and the M16 glands' hole size | The pod's printed holes are 8.2 and 16.2 mm | AST-DWG-106 |
| 6 | FieldNode's enclosure lug kit positions match FieldNode's back plate pattern | The adapter plates copy that pattern | FND-DDR-003 |
| 7 | The FieldNode panel's frame has a flat back lip at least 12 mm wide | FieldNode's panel clips bolt through it | FND-DDR-003 |

## Value engineering

Value-engineering target: USD 285. Estimated cost of the constructable design: USD 302.50 (USD 17.50 over the target).

The target is `budget_usd`, a hypothetical control target, not a limit, and covers the sensor head only; with the FieldNode core, which is costed in FieldNode, the node is USD 433.50. Main cost drivers and savings worth trying:

- The rise from USD 285 came from making the design constructable (AST-DDR-003): line 3, band stock, adapter plates and cross arm (USD 4.50, after the A1 lightening: the thinner rail saves about USD 0.50 and the saddles are repriced at about USD 3.00 of filament at 40 % infill); line 9, probe tube (USD 1); line 10, probe lead with its M8 plug (USD 4); and line 11, inserts, glands, probe socket, terminal block and fixings (USD 8). Line 8 is back to USD 9.00: the 1.5 mm shield plates save about as much filament as the spacers use.
- Savings worth trying: the open two-channel NO2 front end (about USD 35 cheaper, PCB work that is on hold with TRL 4) would recover the USD 17.50, and cheaper band hardware and fixings can be sought at purchase.

## Actions that carry the decisions outside the design

These follow from decisions already made; none is an open decision.

| # | Action | Who | From |
| --- | --- | --- | --- |
| 1 | Ask the pole owner of the first site to confirm a load of 4.0 kg on the pole (3.78 kg with the sun shield as designed) and about 125 N of wind load 3.3 m up | Amish, once a site is chosen | Mass decision (R13), 2026-10-02 |
| 2 | Approach the first candidate partner, the Texas Commission on Environmental Quality's Dallas-Fort Worth monitoring network, with a local university or city partner; nothing is agreed yet | Amish | First partner decision, 2026-10-02 |
| 3 | When the partner is agreed, fix the radio band and FieldNode antenna in the BOM; for US915, restate R10 against the 400 ms dwell limit (SF9 or lower) | Next design update after the partner is agreed | Radio band decision, 2026-10-02 |
| 4 | Send FieldNode the adapter plate request and track its confirmation of port B's always-on 5 V and the 5 min private-gateway interval | Cross-repo (see REVIEW.md) | Decisions of 2026-10-02 on FieldNode |
| 5 | Propose the common M12 pin assignment to FieldNode, with CurbCount; once FieldNode agrees, update the pod wiring in build plan section 3.10 and its wiring picture | Cross-repo (see REVIEW.md) | Pin assignment decision, 2026-10-02 |
| 6 | Check LoRaWAN signal strength with the pod fitted; move the pod 8 mm left in the model and pictures only if the check shows a loss | TRL 4 (on hold) | Antenna whip decision, 2026-10-02 |

## Decisions made

| Date | Decision | Decided by | Record |
| --- | --- | --- | --- |
| 2026-09-25 | TRL 2 review items D1 to D9: budget covers the sensor head only; pitch wording; NO2 collocation plan; NO2-B43F class sensor; ISB class front end bought first; SPS30 class particle sensor; 3.0 m inlets; 5 min records with raw signals; open data | Amish: "i accept all your recommendations, go with them across all repos." | AST-DDR-001, AST-DDR-002 |
| 2026-09-25 | `budget_usd` $285 for the sensor head; FieldNode back plate left off with the enclosure and bracket on the AirStreet rail; frontal area limit 0.15 m²; R3 (WHO guideline) withdrawn and kept as research; 60 s particle run; 5 min records on a private gateway and 15 min on The Things Network; FieldNode sun shield at sites above 45 °C; pre-collocated pod exchange for service | Amish, same instruction: go with recommendation | AST-DDR-002, N1 to N7 |
| 2026-10-02 | Design for construction accepted as a whole: the changes P1 to P10 (adapter plates, 140° V-saddles, bands in saddle grooves, cross arm, two-part pod, cable entries, shield spacers and probe tube) and their knock-on changes, as made | Amish: "i approve your recommendations for all 555 open decisions." | AST-DDR-003, Table 1 |
| 2026-10-02 | Mass (R13): option (c). The R13 limit is set at 4.0 kg including FieldNode's sun shield, the pole owner is asked to confirm that load, and the four lightening steps (saddles at 40 % infill, 40 x 4 mm rail, 1.5 mm shield plates, windows in the adapter plates) are carried into the TRL 4 build to give margin | Amish: "i approve your recommendations for all 555 open decisions." | AST-DDR-003, A1 |
| 2026-10-02 | Antenna whip: accept the 15 mm clearance to the pod's drip lid and check signal strength with the pod fitted at TRL 4; move the pod 8 mm left only if that check shows a loss | Amish: "i approve your recommendations for all 555 open decisions." | AST-DDR-003, A3 |
| 2026-10-02 | First partner chosen by one rule: a city or air agency that runs a regulatory NO2 reference station at a street-level site AirStreet can mount beside, and that will share its data. First candidate to approach: the Texas Commission on Environmental Quality's Dallas-Fort Worth monitoring network, with a local university or city partner | Amish: "i approve your recommendations for all 555 open decisions." | AST-DDR-001, O1 |
| 2026-10-02 | Agree with FieldNode: send FieldNode the request to mount its enclosure, plate clips and sun shield on AirStreet's two adapter plates, and to keep its model stable since AirStreet carries a copy | Amish: "i approve your recommendations for all 555 open decisions." | AST-DDR-002 N2, AST-DDR-003 |
| 2026-10-02 | Port B's always-on 5 V supply and the 5 min interval on a private gateway: closed as already decided on 2026-09-25 (AST-DDR-002, N5 and its cross-repo actions); FieldNode's confirmation is tracked as a cross-repo action, not a decision | Amish: "i approve your recommendations for all 555 open decisions." | AST-DDR-002 |
| 2026-10-02 | FieldNode port pin assignment: propose to FieldNode one common assignment for both M12 ports (supply, ground, I2C data, I2C clock and one spare line), with each port's supply voltage set per project by its supply module (5 V on both ports for AirStreet) | Amish: "i approve your recommendations for all 555 open decisions." | FND-DDR-001, O2 |
| 2026-10-02 | Radio band set with the partner of the first-partner decision above (not with the adapter plates, as the register said): US915 for a North American partner, EU868 for a European one, with the matching FieldNode antenna | Amish: "i approve your recommendations for all 555 open decisions." | FND-DDR-001, O1 |

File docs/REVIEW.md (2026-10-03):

# Review note: AirStreet

## Session 2026-09-25: /populate to a strong TRL 2

### What was done

- `docs/01-problem.md` (AST-PRB-001 v0.2): problem with cited figures, users, operating environment, constraints, out of scope, prior work, open questions; co-design checklist kept.
- `docs/02-concept.md` (AST-PRC-001 v0.2): how it works, numbered components, design choices, calibration route (CalRig for PM, temperature and humidity; field collocation with a reference station for NO2), first-order numbers with assumptions, safety, open questions.
- `docs/03-requirements.md` (AST-REQ-001 v0.2): 16 measurable requirements (R1 to R16) with targets and a status column.
- `cad/src/concept_media.py`: massing model of the node on a street light pole (FieldNode core and panel, band clamps and rail, sensor pod, PM sensor, NO2 sensor, front end, radiation shield, temperature and humidity sensor, cables), with a pole, sidewalk, kerb, carriageway and 1.75 m person as grey context. The scene is shifted down 3 m in the script because the kit's cutaway cutter is centered on Z = 0.
- `media/`: hero, blueprint sheet (PNG, PDF, SVG), cutaway, exploded view with BOM callouts, measurement and data flow diagram, `model.glb` and `viewer.html`. Temporary `_views` folders removed.
- `bom/bom.csv`: 11 lines numbered to match the exploded view, with indicative costs. `bom/bom-notes.md` updated to state totals and the budget gap.
- `README.md`: hero and links line; Concept rationale, Burning platform, Where it could be used, What sparked the idea, Concept, Key components and Safety expanded. The README states that NO2 is calibrated by field collocation, not on CalRig.
- `docs/pdf/`: branded PDFs of the three controlled documents.

### Key results (estimates, to be checked at TRL 3)

| Quantity | Estimate | Requirement |
| --- | --- | --- |
| Sensor average power | about 41 mW (45 mW with margin) of FieldNode's 115 mW | R9 met |
| Record interval and payload | 5 min, about 20 bytes | R8 met |
| LoRaWAN airtime | about 0.06 % (SF9) to 0.5 % (SF12) | R10 met |
| NO2 hourly error after field calibration | about 5 ppb (9.4 µg/m³), target | R2 at risk |
| NO2 near the WHO annual guideline (10 µg/m³) | not resolvable | **R3 not met** |
| Mass and frontal area on the pole | about 3.0 kg, 0.09 m² | R13 met |
| Parts cost | about $391 per node with FieldNode core; about $265 sensor head only | **R15 not met** ($180 budget) |

Requirements not met or at risk:

- **R15 (cost) not met:** about $391 per node, or $265 without the FieldNode core, against $180.
- **R3 (NO2 near the WHO guideline) not met:** expected hourly error is about the size of the guideline level; AirStreet can rank streets and check the EU 40 µg/m³ limit (R4) but cannot confirm WHO guideline compliance.
- **At risk:** R2 (NO2 accuracy and seasonal drift unverified), R5 (radiation shield error in low wind), R12 (condensation and insects in the pod), R16 (sensor swap at height within 15 min).

### Proposed, awaiting Amish (status updated 2026-09-25, see AST-DDR-002)

1. **Budget.** Options: (a) budget covers the sensor head only, with the FieldNode core costed in FieldNode, and rises to about $280; (b) raise `budget_usd` to about $400 for the whole node; (c) keep $180 with a cheaper PM sensor and a three-electrode NO2 sensor, at a clear loss of NO2 accuracy. Recommendation: (a). `project.yaml` is unchanged. **Decided by Amish, 2026-09-25: go with recommendation** (AST-DDR-002).
2. **Pitch wording.** The pitch says "calibrated on CalRig", but CalRig covers only temperature, humidity, CO2 and particles. Proposed: "A street-level air quality node measuring PM2.5 and NO2, with particles checked on CalRig and NO2 calibrated against a reference station, for neighborhood-scale pollution maps." Recommendation: adopt. `project.yaml` and the README intro are unchanged until Amish decides. **Decided by Amish, 2026-09-25: go with recommendation** (AST-DDR-002).
3. **NO2 calibration method.** Field collocation with a regulatory reference station for at least 14 days before deployment, at least every 6 months after, and one permanently collocated anchor node; multiple linear regression first, random forest later. Alternative: collocation only at deployment. Recommendation: the full plan. **Decided by Amish, 2026-09-25: go with recommendation** (AST-DDR-002).
4. **NO2 sensor.** Alphasense NO2-B43F class (four electrodes, ozone filter) versus a cheaper three-electrode sensor. Recommendation: B43F class. **Decided by Amish, 2026-09-25: go with recommendation** (AST-DDR-002).
5. **NO2 front end.** Buy an ISB class board for the first units versus an open two-channel potentiostat (saves about $35). Recommendation: buy first, study the open design at TRL 3. **Decided by Amish, 2026-09-25: go with recommendation** (AST-DDR-002).
6. **PM sensor.** Sensirion SPS30 class versus a Plantower PMS5003 class sensor (about $25 cheaper). Recommendation: SPS30 class. **Decided by Amish, 2026-09-25: go with recommendation** (AST-DDR-002).
7. **Inlet height.** About 3.0 m (proposed) versus about 2.5 m, both within the EU 1.5 to 4 m range. Recommendation: 3.0 m. **Decided by Amish, 2026-09-25: go with recommendation** (AST-DDR-002).
8. **Reporting.** One record every 5 min, PM sensor run 30 s per record, raw signals sent. Recommendation: adopt. **Decided by Amish, 2026-09-25: go with recommendation** (AST-DDR-002).
9. **Open data.** Publish calibrated hourly data, with calibration version, to an open platform such as OpenAQ. Recommendation: yes, subject to the partner's agreement. **Decided by Amish, 2026-09-25: go with recommendation** (AST-DDR-002).
10. **First partner, city and reference station** for co-design and collocation. Still proposed, awaiting Amish (no recommendation).

### Safety concerns

- Work at height beside traffic when mounting; wind load on the pole unverified.
- Mains voltage inside street light poles: never open the pole or tap its supply.
- Lithium iron phosphate cell in the FieldNode core.
- Acid electrolyte in the electrochemical sensor; sharp edges on clamps and flat bar.
- Misuse of indicative data as regulatory or health evidence: every map must carry its calibration version and uncertainty.

### Problems and notes

- The README intro paragraph still repeats the pitch ("calibrated on CalRig"); it was kept pending decision 2, and the rest of the README states the NO2 route.
- Prices are indicative and were not checked against suppliers (the web search quota was exhausted; figures in the documents were verified by fetching the cited pages). NO2 sensor and front-end prices and power draws are estimates.
- FieldNode figures ($126, 1.7 kg, 115 mW) come from the FieldNode README, which is being written in parallel; recheck when it settles.
- The legacy `cad/src/model.py` placeholder is untouched (TRL 3 work).

### Recommended next step

Review this note and the media, then decide items 1 and 2. If approved, run `/advance-trl3` to check the power, airtime, mass and wind-load estimates by calculation, write the collocation and calibration method as a calculation note, and produce the parametric model and drawing sheet.

## Session 2026-09-25: TRL 3

On 2026-09-25 Amish asked for this batch of repos to go through the usual process with the instruction "you know the drill, nothing gets past TRL 3". He has not reviewed this repo's TRL 2 items one by one, so every item that carried a recommendation is adopted as recommended for TRL 3 under Amish's 2026-09-25 instruction, open for his review. Nothing here is recorded as decided or approved by Amish. This session ran `/advance-trl3` on that basis and stopped at TRL 3.

### What was done

- `docs/decisions/0001-trl2-review-decisions.md` (AST-DDR-001 v0.1, status proposed): D1 to D9 adopted as recommended for TRL 3, open for Amish's review; O1 left open.
- `docs/04-calcs/01-sizing.md` (AST-CAL-001 v0.1) and `docs/04-calcs/sizing.py`: power and energy, airtime and storage, NO2 error budget, radiation shield, PM2.5 humidity error, geometry, projected area and mass, wind and mounting, service time, cost, and a status for every requirement. The script imports the model's PARAMS and part solids, reads the BOM and `project.yaml`, prints every quoted number with a tag and writes `docs/04-calcs/results.csv`.
- `cad/src/model.py`: parametric build123d model at massing-plus detail (FieldNode core envelope at FieldNode's dimensions and penetrations, panel and bracket, rail, V-saddles, band clamps, shield arm, pod with slots, mesh and drip lid, SPS30, NO2 sensor, front end, eight-plate shield, T and RH probe, cables). Exports `cad/step/` and `cad/stl/` for `airstreet-assembly` (with a pole stub), `airstreet-sensor-head` and `airstreet-mount`.
- `cad/src/sheets.py` and `cad/drawings/AST-DWG-001.svg`, `.pdf`, `.png`: general arrangement at Rev P1, 1:10, marked "CONCEPT, NOT FOR FABRICATION" and "PRELIMINARY, NOT FOR FABRICATION". AST-DWG-001 was free because the concept blueprint is AST-DWG-010.
- `bom/bom.csv` (11 lines, all priced with a supplier or supplier type) and `bom/bom-notes.md`. SPS30 and SHT45 prices checked by WebFetch; cables shortened to 0.5 m; saddles added to line 3.
- `cad/src/concept_media.py` now builds from the model; all of `media/` re-rendered and every image checked; temporary `_views` folders deleted.
- AST-PRB-001, AST-PRC-001 and AST-REQ-001 revised to v0.3. `README.md` (badge, TRL line, pitch, links, performance paragraph; the required sections are unchanged in order and wording) and `project.yaml` (pitch per D2, `trl: 3`, `trl_target: 3`, evidence list) updated. PDFs rebuilt in `docs/pdf/`.

### Requirement status (AST-CAL-001, Table 3)

3 not met, 6 at risk, 3 met on paper, 4 met by design.

| ID | Status | Key number |
| --- | --- | --- |
| R3 NO2 near the WHO guideline | **Not met** | Annual uncertainty 4.2 µg/m³ (1σ) against 2 µg/m³; would need a transfer bias of 0.16 ppb |
| R13 Mass and area | **Not met** | 3.65 kg against 3.5 kg; 0.138 m² against 0.12 m² (TRL 2 said 3.0 kg and 0.09 m², using 1.7 kg for FieldNode instead of 2.41 kg) |
| R15 Cost | **Not met** | Sensor head $283.00 against $180 (`budget_usd`) and $280 (proposed); $409.00 with the FieldNode core |
| R1 PM2.5 | At risk | Within ±5 µg/m³ or ±30 % up to 80 % RH; outside it at 85 % RH and above |
| R2 NO2 hourly | At risk | About 3.9 ppb MAE from assumed terms, against 5 ppb |
| R4 EU limit | At risk | Decisive only below 34.6 or above 45.4 µg/m³ |
| R5 T and RH | At risk | Shield 0.43 to 0.89 K at 1 m/s; 4.2 % RH low at 85 % RH |
| R12 Outdoors | At risk | FieldNode rated to 45 °C ambient against R12's 50 °C; SPS30 recommended to 80 % RH |
| R16 Service | At risk | About 14 min against 15; a new NO2 sensor needs collocation |
| R8, R9, R10 | Met on paper | 40.3 kB for 7 days; 48.0 mW design load, 1.29 Wh/day, 11.9 days without sun; 0.60 % duty at SF12 |
| R6, R7, R11, R14 | Met by design | |

Key numbers: 247 ms per uplink at SF9 (1.81 s at SF12, not the 1.3 s of TRL 2); 124 N and 414 N·m at the pole base in a 35 m/s gust; clamp slip factor 25; whip clearance to the pod 23 mm.

### Decisions recorded (AST-DDR-001)

Adopted as recommended for TRL 3 under Amish's 2026-09-25 instruction, open for his review (now decided by Amish, 2026-09-25: go with recommendation, see AST-DDR-002): D1 budget covers the sensor head only, FieldNode core costed in FieldNode (R15 redefined; the $280 figure is recorded only and `budget_usd` stays $180); D2 pitch reworded and applied to `project.yaml` and `README.md`; D3 full NO2 collocation plan; D4 NO2-B43F class sensor; D5 buy an ISB class front end first; D6 SPS30 class PM sensor; D7 inlets at 3.0 m; D8 5 min records, 30 s PM run, raw signals; D9 open data subject to the partner's agreement.

### Still awaiting Amish (status updated 2026-09-25, see AST-DDR-002)

1. **O1, first partner, city and reference station.** No recommendation was made. Still proposed, awaiting Amish.
2. **Budget figure.** `budget_usd` is $180; $280 is recommended (D1); the sensor head is now $283.00. Options: accept about $285; find $3 (for example quantity pricing on the SPS30, $57.48 at 25 or more); or the open front end at about $25 instead of $60 once designed. Recommendation: set about $285 for now and revisit the open front end later. **Decided by Amish, 2026-09-25: go with recommendation** (AST-DDR-002).
3. **New, mass and area (R13).** Options: (a) leave off FieldNode's 0.47 kg back plate and fix its enclosure and bracket to the AirStreet rail (3.19 kg, area slightly lower), which changes the FieldNode mounting interface; (b) relax R13 to 4.0 kg and 0.15 m²; (c) both. Recommendation: (a), agreed with FieldNode, plus relaxing the area limit to 0.15 m², since the panel alone is set by FieldNode. Not applied. **Decided by Amish, 2026-09-25: go with recommendation** (AST-DDR-002).
4. **New, WHO guideline (R3).** Options: drop R3 and state plainly that AirStreet ranks streets and checks the EU limit only; or keep R3 as a research goal needing an anchor node at every site. Recommendation: drop it as a requirement and keep it as an open research question. Not applied. **Decided by Amish, 2026-09-25: go with recommendation** (AST-DDR-002).
5. **New, PM run length.** The SPS30 needs up to 30 s to a first reading in clean air. Options: keep 30 s; or run 60 s (design load 87.0 mW, still inside 100 mW). Recommendation: 60 s. Not applied. **Decided by Amish, 2026-09-25: go with recommendation** (AST-DDR-002).
6. **New, fair use on The Things Network.** At 5 min, only SF7 fits the 30 s/day policy. Options: 5 min on private gateways only; or 15 min on TTN at SF8 and slower. Recommendation: 5 min on the TwinKit gateway, 15 min on TTN. Not applied. **Decided by Amish, 2026-09-25: go with recommendation** (AST-DDR-002).
7. **New, R12 temperature range.** FieldNode is rated to 45 °C ambient. Options: cap R12 at 45 °C; or require FieldNode's proposed sun shield at hot sites. Recommendation: require the shield at sites above 45 °C, consistent with FieldNode's own recommendation. Not applied. **Decided by Amish, 2026-09-25: go with recommendation** (AST-DDR-002).
8. **New, service unit (R16).** Recommendation: exchange a pre-collocated pod rather than individual sensors at the pole. Not applied. **Decided by Amish, 2026-09-25: go with recommendation** (AST-DDR-002).

### Cross-repo consistency

- **FieldNode** (TRL 3 in its repo): enclosure 150 x 90 x 200 mm, back plate 180 x 320 x 3 mm, ports at x = -52 and -22 mm, whip at x = 58 mm, panel 290 x 200 mm at 40°, $126.00 and 2.41 kg are used as FieldNode states them. Conflicts noted here, FieldNode not edited: (a) FieldNode's V-block mount fits 40 to 60 mm poles, so AirStreet brings its own mount for 80 to 200 mm poles; (b) AirStreet needs port B's 5 V rail held on continuously for the NO2 bias, while FieldNode describes switched rails that are off while the node sleeps; (c) FieldNode's 15 min default and its R9 fair-use target do not fit AirStreet's 5 min records on TTN (item 6); (d) FieldNode is rated to 45 °C ambient against AirStreet's 50 °C (item 7). AirStreet's 48 mW fits both the 115 mW ceiling and the 100 mW FieldNode proposes.
- **CalRig:** CalRig's A5 (NO2 by field collocation only) matches D2 and D3. CalRig's R10 bay (90 x 70 x 50 mm) takes the SPS30 and SHT45 probe individually but not the assembled 170 x 110 x 95 mm pod; the pod fits the chamber if it takes two bays. Noted, CalRig not edited.
- **TwinKit:** the default gateway (FND-DDR-001 D7) is assumed; no TwinKit interface is used here.

### Safety concerns

- Work at height beside traffic; the node adds about 124 N and 414 N·m at the pole base in a 35 m/s gust, which the pole owner must check.
- Band clamps carry every mounting margin on an assumed 1,000 N preload; installers need a torque figure.
- Mains voltage inside street light poles: never open the pole or tap its supply.
- LiFePO4 cell in the FieldNode core; FieldNode runs hot above 45 °C ambient, and its 45 °C charge lockout must not be defeated.
- Acid electrolyte in the NO2 sensor; sharp edges on clamps and flat bar.
- Misuse of indicative data: R3 is not met, so no map should claim WHO guideline compliance for NO2.

### Gaps and notes

- Citations: the TRL 2 note listed no unchecked citations. WebFetch confirmed the SPS30 datasheet values (current, operating ranges, start-up time, mass, precision) and the SPS30 and SHT45 prices. The Alphasense pages are blocked to fetching, so NO2 sensor and front-end prices, power, gain and noise remain stated assumptions. WebSearch was not used (quota exhausted).
- The NO2 and shield results rest on assumed terms (transfer bias, drift, inner air speed); AST-CAL-001 lists each one.
- The kit's cutaway cuts at the mean Y of the parts and its cutter is centered at Z = 0, so `concept_media.py` shifts the scene down by the inlet height (3,000 mm), as at TRL 2. The cutaway shows the pod interior and the shield plates; the T and RH probe mostly falls in the removed half. In the exploded view the callouts for the small parts 5, 6 and 9 partly cover them.
- Existing material beyond TRL 3: none. `build-log/README.md` is the stock header; `electronics/` and `firmware/` are empty. None was extended.

### Recommended next step

TRL 4 is on hold by Amish's instruction; this repo stops at TRL 3. Amish's review is needed on AST-DDR-001 and on items 1 to 8 above. For the record only, TRL 4 would need: a bench-built sensor head on a FieldNode core; a lab test report (TST, `environment: lab`) covering port power draw, SPS30 start-up in clean air, shield error under a lamp and fan, CalRig checks of the SPS30 and SHT45, and NO2 zero and noise with the chosen front end; and build log entries. Field collocation belongs to TRL 5. None of this has been started.

## Session 2026-09-25: recommendations accepted

On 2026-09-25 Amish wrote: "i accept all your recommendations, go with them across all repos." Every AirStreet item with a recommendation is now decided by Amish, 2026-09-25: go with recommendation, and is recorded in `docs/decisions/0002-recommendations-accepted.md` (AST-DDR-002). Items without a recommendation stay open.

### Decisions applied and what changed

| Item | Decision | Before | After |
| --- | --- | --- | --- |
| D1 to D9 (AST-DDR-001) | As recommended | Adopted for TRL 3, open for review | Decided; AST-DDR-001 v0.2 |
| Budget | About $285 for the sensor head | `budget_usd` $180 | `budget_usd` $285; sensor head $283.00 to $285.00 (adapter bars +$2); R15 met with no margin |
| R13 mass and area | Leave off FieldNode's back plate, enclosure to the rail; area limit 0.15 m² | 3.65 kg, 0.138 m² against 3.5 kg, 0.12 m² | 3.26 kg, 0.126 m² against 3.5 kg, 0.15 m²; model, STEP, STL, AST-DWG-001 Rev P2, BOM line 3 |
| R3 WHO guideline | Drop as a requirement, keep as research | Not met (4.2 µg/m³ against 2) | Withdrawn; research question |
| PM run | 60 s per record | 30 s; 48.0 mW design load; 11.9 days without sun | 60 s; 87.0 mW; 6.6 days (4.6 days at -20 °C) |
| TTN fair use | 5 min on the TwinKit gateway, 15 min on TTN | 5 min fits TTN only at SF7 | 15 min on TTN fits up to SF9 (23.7 s/day); R8 restated |
| R12 heat | FieldNode sun shield required above 45 °C | Target -10 to 50 °C without a rule | Shield required above 45 °C; still at risk until FieldNode designs it |
| R16 service | Exchange a pre-collocated pod | Sensor swap, 14 min, recollocation needed | Pod exchange, about 14 min; met on paper |

Documents revised with the change "Recommendations accepted by Amish (DDR-002)": AST-PRB-001 v0.4, AST-PRC-001 v0.4, AST-REQ-001 v0.4, AST-CAL-001 v0.2 (script rerun, `results.csv` regenerated), AST-DDR-001 v0.2 and the new AST-DDR-002 v0.1. `project.yaml` (`budget_usd`, evidence list), `README.md` (budget, performance paragraph, components, new "What sparked the idea"), `bom/bom.csv` and `bom/bom-notes.md` updated. All media, the drawing and the PDFs were regenerated; temporary `_views` folders deleted.

### Requirement status now (AST-CAL-001 v0.2)

- **Not met:** none (was R3, R13 and R15).
- **At risk (5):** R1 PM2.5 above 85 % RH; R2 NO2 hourly error rests on assumed terms; R4 EU limit decisive only outside 34.6 to 45.4 µg/m³; R5 shield error in low wind; R12 FieldNode sun shield not yet designed, humidity, condensation and insects.
- **Met on paper (6):** R8, R9, R10, R13, R15 (no margin), R16.
- **Met by design (4):** R6, R7, R11, R14.
- **Withdrawn (1):** R3, kept as a research question.

The 60 s PM run leaves 13 mW under FieldNode's 100 mW design value, and autonomy at -20 °C (4.6 days) is below the 5 days FieldNode's own R6 asks of its core. AirStreet has no autonomy requirement, so this is noted, not a failure.

### Still awaiting Amish

1. **O1, first partner, city and reference station** for co-design and collocation. No recommendation was made.

### Cross-repo actions (not made here)

- **FieldNode:** accept an enclosure bolted to the AirStreet rail without its back plate, with the panel bracket feet on two AirStreet adapter bars (R13); design and supply the sun shield for sites above 45 °C (R12); keep port B's 5 V rail on continuously for the NO2 bias; allow a 5 min interval on a private gateway alongside its 15 min TTN default.
- **TwinKit:** serve as AirStreet's default private gateway for 5 min records.
- **CalRig:** take the assembled pod across two bays if it is checked whole.

### Other changes

- "What sparked the idea" in `README.md` now cites the Ella Adoo Kissi-Debrah inquest (coroner's finding, December 2020; Prevention of Future Deaths report, 20 April 2021), verified by fetching the judiciary, CIEH and IAQM pages. The previous text about a portfolio review was removed. `docs/01-problem.md` did not attribute the idea to a review.
- All generated files (docs PDFs, drawing, concept media) were rebuilt; none shows the old personal domain.

### TRL

TRL 4 remains on hold by Amish's instruction. Decisions that need TRL 4 or later work are decided but on hold: buying the ISB class front end (D5), field collocation (D3), publishing open data (D9), the open two-channel front end (budget item), the firmware reporting rule, and spare pods. `trl: 3` and `trl_target: 3` are unchanged.

## Session 2026-09-26: product appearance model and photoreal renders

Amish chose AirStreet on 2026-09-26 for the first batch of product renders. This session adds an appearance model for photoreal renders. It changes no design parameter, requirement, calculation or BOM line.

### What was done

- `cad/src/product_model.py` (new): `product_parts()` returns 66 parts (45 shell, 20 internal, 1 context), each with a colour, a render material, its BOM line, a group and an explode offset; `TITLE` and `RENDER_VIEWS` (hero on the pole, exploded, and a detail view without the pole). It imports `PARAMS`, `derived()` and `build_parts()` from `cad/src/model.py`, so every main dimension and interface is unchanged: pole axis, 3.0 m inlet plane, rail, saddles, 375 mm clamp spacing, adapter bars, FieldNode envelope, ports, whip, 40 deg panel, pod, sensors, front end, shield and arm.
- Appearance detail added: filleted FieldNode enclosure with parting line, gasket, side ribs, lid screws, lid label and a lit green status light; M12 sockets with knurled plugs and cables; blanked glands; whip antenna with a swivel knuckle; aluminium panel frame with cell grid and junction box; filleted pod with side ribs, lid screws, cable glands, stainless mesh and a label strip; dished shield plates with spacers, stainless rods and acorn nuts; worm housings and screws on the band clamps; slotted rail; cable clips on the shield arm; the FieldNode board and LiFePO4 cell inside; a short section of 140 mm pole as context.
- `README.md`: the hero image now points to `media/render-hero.png`, with a link to `media/render-exploded.png`. The render files are produced separately.

### Differences from model.py (Proposed, awaiting Amish)

1. **Clear service window in the pod's street face.** Not in `model.py` or the BOM; added so the renders show the PM sensor, NO2 sensor and front end. A window lets sun heat the pod and adds a seal. Recommendation: keep the window in the renders only and keep the pod opaque ASA in the design; if Amish wants it in the design, use UV-stabilized polycarbonate and add it to BOM line 4.
2. **Radiation shield plates drawn with a 6 mm downturned lip and rod spacers.** `model.py` has flat rings. The lip and spacers are the usual multi-plate shield form and keep the 120 mm OD, 56 mm ID, 13 mm pitch and eight plates. Recommendation: adopt the lipped plate as the reference form at the next design update; the shield error in AST-CAL-001 does not depend on it.
3. **FieldNode interior (power and radio board, LiFePO4 cell in a cradle).** Illustrative envelopes only, placed for the exploded view; FieldNode's own model governs them. Recommendation: accept as illustration, no change to FieldNode.
4. **Label wording on the FieldNode lid** ("AirStreet", "PM2.5 + NO2 STREET NODE", "RAW SIGNALS, OPEN CALIBRATION", band "FIELDNODE CORE") and the pod strip ("INLET BELOW · PM · NO2"). Naming and wording are Amish's call. Recommendation: keep; the wording matches the pitch and does not claim certification.

### TRL

Appearance only: no tolerances, fabrication detail, PCB layouts or TRL 4 work. `trl: 3` and `trl_target: 3` are unchanged, and TRL 4 remains on hold.

## Session 2026-09-27: kit 1.5.0 and image quality

- Kit 1.5.0 synced: STANDARDS v1.5 (sections 12 to 15: product renders, storefront images and image quality, public release, authorship and signing), `.kit/cards.py`, `.kit/image_qc.py`, `.kit/release_gate.py`, issue templates, and the `/render-product` and `/release` commands. `CLAUDE.md` now matches `.kit/CLAUDE.md`.
- Every `media/render-*.png` recaptioned from its original render with the new layout: the title, concept label and repository sit in a band above the render and the view note in a band below it, each line wrapped to the image width, so no text overlaps other text or the render or runs off the image. `media/card.png` and `media/social-preview.png` regenerated with the same rules.
- `python .kit/image_qc.py` and `python .kit/release_gate.py` pass. trl stays 3.

## Session 2026-09-30: kit 1.7.0, design for construction and the prototype build plan

On 2026-09-30 Amish approved the FieldNode build plan as the format for every repo ("this is the correct build plan ... this is a good quality document format. Extend this across all the other repos") and asked that outstanding decisions go in a separate design decisions register, not in the build plan. He also wrote: "If you are realising that the design cannot be built as per concept - fix the design assumptions to match and be physically feasible as you draw the illustrations." This session applied both to AirStreet.

### What was done

- Kit 1.7.0 installed (`.kit/`, `.claude/commands/`); `CLAUDE.md` replaced by `.kit/CLAUDE.md`.
- `cad/src/fieldnode_core.py` (new): an unchanged, vendored copy of FieldNode's constructable model (FND-DDR-003), so AirStreet builds the FieldNode core exactly as FieldNode does.
- `cad/src/model.py` rewritten as a constructable model (components, fixings and 71 constructability checks, all passing: `python cad/src/model.py --check`). STEP and STL re-exported.
- `docs/decisions/0003-design-for-construction.md` (AST-DDR-003 v0.1, Draft): every change, its reason, the knock-on changes and three items proposed to Amish.
- `cad/src/build_plan_media.py` (new) and its pictures: overview, hole layout, wiring, nine making sketches (AST-DWG-101 to 109), eight joint close-ups and sixteen step pictures in `docs/05-build-plan/` and `cad/drawings/`. Every picture was looked at and fixed where unclear.
- `docs/05-build-plan.md` (AST-BLD-001 v0.1) and `docs/06-design-decisions.md` (AST-DEC-001 v0.1) written from the kit templates.
- Recalculated: `docs/04-calcs/sizing.py` and AST-CAL-001 v0.3 (mass from the model's volumes, new mount loads, cost). AST-REQ-001 v0.5 and AST-PRC-001 v0.5 updated. `bom/bom.csv` lines 1, 2, 3, 4, 8, 9, 10 and 11 revised.
- AST-DWG-001 Rev P4 regenerated; concept media regenerated from the new model (`media/hero.png`, `exploded.png`, `cutaway.png`, `flow.png`, `concept-blueprint.*`, `model.glb`).
- `project.yaml`: `design_state: constructable`; the DDR, build plan and register added to `trl_evidence`. `README.md`: links line and a "Building the prototype" section.
- `cad/src/product_model.py`: given the concept-only parameters it needs so it still runs; it still shows the concept (see Stale media).

### Design changes made for construction (AST-DDR-003, Draft, open for Amish's review)

1. FieldNode core taken from FieldNode's own constructable model; the pod moved from 70 to 90 mm left of the pole because FieldNode's whip moved; whip clearance to the drip lid 15 mm (was 23 mm).
2. Two 3 mm aluminium adapter plates (180 x 75 and 180 x 110 mm) on the rail, drilled to FieldNode's back plate pattern, carry the enclosure lugs, the plate clips and (hot sites) the sun shield; they replace the two adapter bars.
3. Adapter plate heights set so FieldNode's sun shield screws land on them.
4. Printed V-saddles 100 x 50 x 24 mm with a 140° V that seats 80 to 200 mm poles (was a round seat for 140 mm only).
5. Bands cut to length from a 12.7 mm worm-drive band roll, running in a groove across the back of each saddle, between saddle and rail.
6. Saddles fixed to the rail by two M5 countersunk screws into heat-set inserts.
7. A 30 x 30 x 3 mm angle cross arm bolted to the rail carries the pod and the shield cap on screws from above; the rail shortened to 451 mm.
8. Pod split into a printed shell (walls, roof, drip lid) and a printed sensor floor with a PM sensor cradle and an NO2 sensor collar, closed from below over the mesh by four M3 screws; front end on standoffs on the back wall; inlet slots 50 x 50 and 50 x 40 mm.
9. Two M16 glands in the pod roof under FieldNode's ports; an M8 socket in the pod wall for the probe lead, so the pod unplugs for exchange.
10. Shield: 24 spacers, rods through the cap with nuts, cap screwed under the arm, probe on a 6 mm tube through the cap and the arm.

### Key results

- Mass 3.84 kg on the pole (4.00 kg with FieldNode's sun shield): **R13 not met** (3.5 kg). Frontal area 0.143 m², met.
- Sensor head $303.00 against the $285 value-engineering target (`budget_usd`): **R15 over the target by $18.00**. FieldNode core as used $131.00; whole node $434.00.
- Wind 128 N and 428 N·m at the pole base in a 35 m/s gust; clamp slip factor 24; cross arm 4.5 MPa; rail 16.4 MPa.
- Requirement status: 1 not met (R13), 1 over the value-engineering target (R15), 5 at risk (R1, R2, R4, R5, R12), 4 met on paper, 4 met by design, R3 withdrawn.

### Proposed, awaiting Amish

All open decisions, with options and recommendations, are in the design decisions register (AST-DEC-001). New this session: acceptance of the design changes as a whole; the R13 mass limit (recommend lightening at TRL 4 and a 4.0 kg limit); the R15 cost, now a value-engineering note (the open front end is the route back under the $285 target); the 15 mm whip clearance (recommend accept and check at TRL 4); FieldNode's agreement to the adapter plates.

### Safety

No change to the safety case. The build plan adds safety stops for the NO2 sensor's shorting spring and the pole stub stand, and repeats the street pole, mains and lithium cell warnings. The higher wind load (128 N) is in AST-PRC-001's safety note and the build plan's stop S6.

### Stale media

`media/card.png` and `media/social-preview.png`, and the photoreal renders made on Amish's Mac (`media/render-*.png`), show the concept mount and pod: the design changed visibly (adapter plates, cross arm, saddles, pod). They, and `cad/src/product_model.py`, need updating on Amish's Mac.

### Recommended next step

Amish reviews AST-DDR-003 and the register (decisions 1 to 4), then FieldNode is asked to accept the adapter plates. TRL stays at 3; nothing was built, bought or tested.

## Session 2026-10-02: open decisions decided

Amish, 2026-10-02: "i approve your recommendations for all 555 open decisions." This approves the recommendation written for every open decision in the design decisions register (AST-DEC-001). trl stays 3; nothing was built, bought or tested, and TRL 4 remains on hold.

### Decisions recorded (8)

| Register item | Decision |
| --- | --- |
| 1 | AST-DDR-003 accepted as a whole: P1 to P10 and their knock-on changes |
| 2 | R13 set at 4.0 kg including FieldNode's sun shield; pole owner to confirm the load; the four lightening steps carried into the TRL 4 build |
| 3 | 15 mm whip clearance accepted; signal strength checked with the pod fitted at TRL 4; pod moved 8 mm left only if that shows a loss |
| 4 | First partner rule: a city or air agency with a street-level regulatory NO2 reference station that will share data; first candidate to approach, TCEQ's Dallas-Fort Worth network with a local university or city partner |
| 5 | Agree with FieldNode: send the request for its enclosure, plate clips and sun shield on AirStreet's adapter plates, and for a stable model |
| 6 | Closed as already decided on 2026-09-25 (AST-DDR-002, N5); FieldNode's confirmation tracked as a cross-repo action |
| 7 | Propose to FieldNode one common pin assignment for both M12 ports, supply voltage per project by supply module (5 V on both for AirStreet) |
| 8 | Radio band set with the partner of item 4 (not item 5): US915 in North America, EU868 in Europe, with the matching FieldNode antenna |

All 8 moved to Decisions made in AST-DEC-001, dated 2026-10-02; the Open decisions section now reads "None."

### Documents changed

- `docs/06-design-decisions.md` (AST-DEC-001 v0.3): items 1 to 8 moved to Decisions made; Open decisions reads "None"; item 8's link corrected to the partner decision
- `docs/decisions/0003-design-for-construction.md` (AST-DDR-003 v0.3): status accepted (kept Draft), A1 and A3 marked accepted, consequence for R13 added
- `docs/03-requirements.md` (AST-REQ-001 v0.7): R13 relaxed to 4.0 kg including the sun shield; status at risk (no margin); counts updated
- `docs/04-calcs/01-sizing.md` (AST-CAL-001 v0.5): R13 status and Table 3 counts against the 4.0 kg limit; note that the script still prints the 3.5 kg result
- `docs/02-concept.md` (AST-PRC-001 v0.7): R13 wording; first partner rule and first candidate; radio band follows the partner; FieldNode request approved
- `docs/01-problem.md` (AST-PRB-001 v0.5): first partner rule and first candidate to approach
- `docs/05-build-plan.md` (AST-BLD-001 v0.2): section 2 says AST-DDR-003 is accepted; no open decisions added
- `README.md`: R13 wording; AST-DDR-003 accepted
- `docs/decisions/0001-trl2-review-decisions.md` (AST-DDR-001 v0.3): item O1 ("Proposed, awaiting Amish") recorded as decided
- `docs/decisions/0002-recommendations-accepted.md` (AST-DDR-002 v0.2): item O1 recorded as decided
- PDFs regenerated with `python3 .kit/render.py`; superseded versions removed.

### Follow-up actions to carry approved decisions into the design

The model, BOM quantities and prices, calculations and pictures were not changed in this session. These actions carry the approved decisions into them:

1. Decision 2 (calculations): Re-run `docs/04-calcs/sizing.py` with R13's limit at 4.0 kg including FieldNode's sun shield, so [J1] and `results.csv` show R13 at risk rather than not met.
2. Decision 2 (model, drawings, build plan pictures): Carry the four lightening steps into the TRL 4 design: saddles printed at 40 % infill, 40 x 4 mm rail, 1.5 mm shield plates and windows in the adapter plates; update AST-DWG-001 and the making sketches.
3. Decision 2 (BOM, calculations): Reprice and reweigh the lightened parts (rail, shield plates, adapter plates) and check whether the lightened 3.6 kg figure includes FieldNode's 0.16 kg sun shield (about 3.76 kg if it does not).
4. Decision 2 (documents): Ask the pole owner of the first site to confirm a 4.0 kg load on the pole.
5. Decision 3 (test plan): At TRL 4, check LoRaWAN signal strength with the pod fitted; move the pod 8 mm left in the model and pictures only if the check shows a loss.
6. Decision 4 (documents): Approach the first candidate partner (TCEQ's Dallas-Fort Worth monitoring network, with a local university or city partner); nothing is agreed yet.
7. Decision 5 and 6 (cross-repo): Send FieldNode the adapter plate request and track its confirmation of port B's always-on 5 V and the 5 min private-gateway interval as one cross-repo action.
8. Decision 7 (build plan pictures, documents): Propose the common M12 pin assignment to FieldNode (with CurbCount, which asks for 3.3 V on port A); once FieldNode agrees, update the pod wiring in build plan section 3.10 and its wiring picture.
9. Decision 8 (BOM, requirements): Once the partner is agreed, fix the band and FieldNode antenna in the BOM; for US915, restate R10 against the 400 ms dwell limit (SF9 or lower) instead of the EU868 duty cycle.

### Points found in the review

Raised when the recommendations were written (2026-10-01) and kept here so they are not lost:

- Item 8 says it 'Follows decision 5'; it should follow decision 4 (partner, city and reference station). Decision 5 is the adapter plates.
- Item 6 was already accepted by Amish on 2026-09-25 (AST-DDR-002, N5 and its cross-repo actions); only FieldNode's confirmation is outstanding, so it belongs with cross-repo actions rather than open decisions.
- Cross-repo conflict on FieldNode port A: AirStreet's build plan powers the SPS30 from a switched 5 V on port A, while CurbCount's build plan replaces FieldNode's port A boost converter with a 3.3 V load switch. FieldNode's pinout decision (FND-DDR-001, O2) must allow a per-project port supply.
- The four appearance items from REVIEW.md 2026-09-26 (pod service window, lipped shield plates, FieldNode interior, label wording) were 'Proposed, awaiting Amish' and are not in the register.
- Item 2: the lightened 3.6 kg figure does not say whether it includes FieldNode's 0.16 kg sun shield; if it does not, the lightened node with shield is about 3.76 kg.

## Session 2026-10-02: approved follow-ups carried out

Amish, 2026-10-02: "497 follow-up actions that need CAD, drawing, picture, BOM or calculation work ... APPROVED CHANGES, COMPLETE THESE", and for the renders, "Photoreal renders are out of date in most repos ... COMPLETE THESE". This session carried AirStreet's nine follow-ups from the 2026-10-02 decisions into the design and prepared the render scenes. trl stays 3; nothing was built, bought or tested, and TRL 4 remains on hold.

### Follow-ups

| # | Follow-up | Done | What was done, or why not |
| --- | --- | --- | --- |
| 1 | Re-run `sizing.py` with R13 at 4.0 kg including the sun shield | Yes | R13 is checked against 4.0 kg with the shield; [J1] and `results.csv` now show R13 met on paper (with the lightening of item 2 in the model), not "not met". R15 now prints "Over the value-engineering target by $17.50" instead of "Not met" |
| 2 | Four lightening steps into the design; update AST-DWG-001 and the making sketches | Yes | `model.py`: 40 x 4 mm rail, two windows in each adapter plate (24 x 59 and 24 x 94 mm, R5), 1.5 mm shield plates (spacers 11.5 and 9.25 mm), saddle print settings (6 walls, 40 % infill) as a mass parameter. Six new checks (windows clear of the rail, of every screw and bolt, and of the lugs, clips and shield flanges); two clearance checks now take the rail thickness as their limit, since the rail lies between the parts. 77 of 77 pass. STEP and STL regenerated. AST-DWG-001 Rev P5; AST-DWG-101, 103, 104 and 108 at P2 |
| 3 | Reprice and reweigh the lightened parts; does 3.6 kg include the sun shield? | Yes | Line 3 $21.00 to $21.50 (rail about $0.50 cheaper; saddles repriced at about $3.00 of filament at 40 % infill, the $1.50 used before being low); line 8 $10.00 to $9.00 (thinner plates). Mass 3.62 kg, 3.78 kg with the sun shield (was 3.84 and 4.00). The "about 3.6 kg" of AST-DDR-003 A1 excludes the shield; with it the node is 3.78 kg ([F8]) |
| 4 | Ask the pole owner of the first site to confirm 4.0 kg | Not done | No site is chosen yet, and asking is Amish's action. Listed as action 1 in the register's new "Actions that carry the decisions outside the design"; the build plan's safety stop S6 now asks for the 4.0 kg load as well as the wind load |
| 5 | TRL 4 signal check with the pod fitted; move the pod 8 mm only on a loss | Not done | TRL 4 work, on hold. Listed as register action 6; the pod is not moved |
| 6 | Approach TCEQ's Dallas-Fort Worth network with a university or city partner | Not done | Amish's action; nothing agreed. Register action 2 |
| 7 | Send FieldNode the adapter plate request; track port B's always-on 5 V and the 5 min interval | Not done here | Lives in the FieldNode repo; see Cross-repo actions below. Register action 4 |
| 8 | Propose the common M12 pin assignment; then update build plan section 3.10 and its wiring picture | Not done here | The proposal lives in FieldNode (see below). Section 3.10 and `wiring.png` stay as they are until FieldNode agrees; the picture already says the pins follow FieldNode's assignment. Register action 5 |
| 9 | Fix the band and FieldNode antenna in the BOM; restate R10 for US915 | Not done | Waits for the partner to be agreed (item 6). R10 still reads against EU868; the US915 figure (SF9 passes the 400 ms dwell limit, [B5]) is already in AST-CAL-001. The BOM notes say the band is set with the partner. Register action 3 |

### Requirement status changes

- R13: at risk to **met on paper**. 3.78 kg with FieldNode's sun shield (3.62 kg without) against 4.0 kg, 0.22 kg of margin; frontal area 0.139 m² (was 0.143). The pole owner's confirmation of the load is still to come.
- R15: still over the value-engineering target, now by $17.50 (was $18.00).
- R5: still at risk; shield error 0.42 to 0.87 K (was 0.43 to 0.89 K), 4.1 % RH low at 85 % RH.
- Counts: 5 at risk, 5 met on paper, 4 met by design, 1 over the value-engineering target, 1 withdrawn. No requirement is not met.

### Cost and mass

Value-engineering target: USD 285. Estimated cost of the constructable design: USD 302.50 (USD 17.50 over the target). Whole node USD 433.50 with the FieldNode core; `budget_usd` unchanged. Mass 3.62 kg on the pole, 3.78 kg with the sun shield. Wind 125 N and 416 N·m in a 35 m/s gust; rail stress 25.6 MPa in the 40 x 4 mm bar (16.4 MPa before), far below yield.

### Pictures regenerated

AST-DWG-001 Rev P5; making sketches AST-DWG-101, 103, 104 and 108 (P2); `docs/05-build-plan/overview.png`, `plate-holes.png` (windows now drawn as dashed outlines, sizes in the key), joints 01, 02, 03, 04, 06 and 08, steps 1 to 7 and 11 to 16; concept media (`media/hero.png`, `exploded.png`, `cutaway.png`, `flow.png`, `concept-blueprint.*`, `model.glb`). Each was looked at once. The kit rounds overall sheet dimensions to whole millimetres, so AST-DWG-108 overrides the plate thickness to show 1.5. Not regenerated, as the change does not touch them: AST-DWG-102, 105, 106, 107, 109, joints 05 and 07, steps 8 to 10 and `wiring.png`. `.kit/drawing.py --check-text` reports no hits.

### Appearance model and render scenes

`cad/src/product_model.py` rebuilt from `model.build_components()`, so every part of the appearance model is the constructable, lightened part: windowed adapter plates, angle cross arm, V-saddles, the two-part pod hanging under the arm, flat 1.5 mm shield plates on spacers, the probe tube, FieldNode's own core, bracket and panel. RENDER_VIEWS keeps hero, exploded and detail (the detail note now describes the pod, arm and shield). Scenes exported with `.kit/export_views.py` to `/home/claude/renders/airstreet`: `airstreet__hero`, `airstreet__exploded` and `airstreet__detail` (.npz and .json each) and `airstreet__jobs.json`. Photoreal renders, `media/card.png` and `media/social-preview.png` are to be made on Amish's Mac and are stale until then.

Appearance deviations, proposed, awaiting Amish:

1. Printed label and a lit green status light on the FieldNode lid (label wording as in the 2026-09-26 item 4). Recommendation: keep.
2. Printed label strip on the pod's street face ("INLET BELOW · PM · NO2"). Recommendation: keep.
3. The 2026-09-26 service window and lipped shield plates are dropped, so the renders now match the design: the pod is opaque and the plates are flat. Recommendation: accept; the sensors show in the exploded view.

### Cross-repo actions

- **FieldNode:** accept AirStreet's two adapter plates (now with lightening windows) in place of FieldNode's back plate for its enclosure, plate clips and sun shield, and keep `cad/src/model.py` stable, since AirStreet carries a vendored copy (`cad/src/fieldnode_core.py`).
- **FieldNode:** confirm port B's always-on 5 V supply and the 5 min interval on a private gateway (AST-DDR-002, N5).
- **FieldNode, with CurbCount:** adopt one common pin assignment for both M12 ports (supply, ground, I2C data, I2C clock, one spare), with each port's supply voltage set per project by its supply module (AirStreet 5 V on both; CurbCount 3.3 V on port A). When agreed, AirStreet updates build plan section 3.10 and `wiring.png`.
- **FieldNode:** offer the antenna for US915 and EU868 so AirStreet can name one when its partner is agreed.

### Documents changed

- `cad/src/model.py` (lightening steps, windows, six new checks; 77 pass); `cad/step/*.step`, `cad/stl/*.stl` regenerated
- `cad/src/sheets.py` (AST-DWG-001 Rev P5), `cad/src/build_plan_media.py` (sketch notes and revisions, window drawing), `cad/src/concept_media.py` (key figures), `cad/src/product_model.py` (rebuilt)
- `docs/04-calcs/sizing.py` and `results.csv`; AST-CAL-001 v0.6 (`docs/04-calcs/01-sizing.md`)
- `bom/bom.csv` lines 3 and 8; `bom/bom-notes.md` (totals, mass, cost history)
- AST-REQ-001 v0.8, AST-PRC-001 v0.8, AST-BLD-001 v0.3, AST-DEC-001 v0.4, AST-DDR-003 v0.4, `README.md`
- PDFs regenerated with `python3 .kit/render.py`

### Safety

No change to the safety case. The build plan's stop S6 and the precis safety note now give the pole owner both the wind load (125 N) and the 4.0 kg weight to confirm. The thinner rail and windowed plates carry their loads with large margins (25.6 MPa in the rail).

### Recommended next step

Amish reviews the three appearance deviations and renders the exported scenes on his Mac (then `python .kit/cards.py .`). The FieldNode cross-repo requests go to the FieldNode repo. TRL stays at 3.

## 2026-10-02: photoreal renders redone on the constructable design

Rendered with Blender Cycles on Amish's Mac from the updated appearance model (`cad/src/product_model.py`); captioned with `.kit/photo_caption.py`; `media/card.png` and `media/social-preview.png` regenerated with `.kit/cards.py`. Views: hero, exploded, detail. image_qc passes. Appearance deviations are those logged above as proposed, awaiting Amish.

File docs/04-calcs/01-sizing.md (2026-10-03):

---
doc_id: AST-CAL-001
title: AirStreet sizing calculations
project: AirStreet
doc_type: Calculation
version: "0.6"
status: Draft
date: '2026-10-02'
author: Amish Chadha
license: CERN-OHL-S-2.0
revisions:
- version: "0.1"
  date: '2026-09-25'
  author: Amish Chadha
  change: First issue for TRL 3 (power and energy, airtime and storage, NO2 error budget, radiation shield, PM2.5 humidity error, geometry, mass and area, wind and mounting, service, cost)
- version: "0.2"
  date: '2026-09-25'
  author: Amish Chadha
  change: Recommendations accepted by Amish (DDR-002)
- version: "0.3"
  date: '2026-09-30'
  author: Amish Chadha
  change: Design made constructable (AST-DDR-003); mass, area, mounting loads and cost recalculated; R13 and R15 now not met
- version: "0.4"
  date: '2026-10-01'
  author: Amish Chadha
  change: Budget treated as a value-engineering target
- version: "0.5"
  date: '2026-10-02'
  author: Amish Chadha
  change: "R13 status against the 4.0 kg limit accepted on 2026-10-02 (AST-DDR-003 A1); sizing.py still to be re-run with it"
- version: "0.6"
  date: '2026-10-02'
  author: Amish Chadha
  change: "sizing.py re-run with R13 at 4.0 kg including the sun shield and the four lightening steps in the model (40 x 4 mm rail, plate windows, 1.5 mm shield plates, saddles at 40 % infill); lines 3 and 8 repriced; R13 met on paper; cost in the approved value-engineering wording"
---

# AirStreet sizing calculations

Version 0.6 follows the constructable design of AST-DDR-003 (2026-09-30), which made every part of the node buildable and moved onto FieldNode's own constructable core, with the four lightening steps of AST-DDR-003, A1 (accepted on 2026-10-02) now in the model: a 40 x 4 mm rail, windows in the adapter plates, 1.5 mm shield plates and saddles printed at 40 % infill. On paper AirStreet now meets nine of its sixteen requirements (five by calculation, four by design), has five at risk and is over its cost target on one (R15); R3 stays withdrawn. The node weighs 3.62 kg on the pole and 3.78 kg with FieldNode's sun shield, against R13's limit of 4.0 kg including the shield (set on 2026-10-02; it was 3.5 kg), so R13 is met on paper with 0.22 kg of margin; before the lightening it was 4.00 kg, on the limit. The pole owner of the first site is still to confirm the 4.0 kg load. Value-engineering target: USD 285. Estimated cost of the constructable design: USD 302.50 (USD 17.50 over the target); the cost drivers and savings worth trying are in the design decisions register. The frontal area, 0.139 m², stays inside 0.15 m², and every mounting part carries its load with a large margin. Power, airtime and the NO2 error budget are unchanged from v0.2, and the thinner shield plates change the shield and humidity results only in the second decimal: the 60 s particle run gives an 87.0 mW design sensor load inside FieldNode's 100 mW allowance and 6.6 days without sun, and an annual NO2 mean carries about 4.2 µg/m³ of uncertainty (1σ). Every number in this note is printed by `docs/04-calcs/sizing.py`; the tag in brackets, for example [A3], is the line of that script's output that carries it.

> **Safety:** These are first-principles estimates for a paper proof of concept. They do not show that the node is safe to mount on any particular pole, and they are not a substitute for the pole owner's structural check, for electrical checks on the FieldNode cell or for field collocation of the sensors. AirStreet data are indicative, not a regulatory measurement or health advice. See AST-PRC-001, Safety.

## Scope and method

The note checks every requirement in AST-REQ-001 v0.8 against the design in AST-PRC-001 v0.8 and the parametric model `cad/src/model.py`, which builds the FieldNode core from FieldNode's own model (vendored as `cad/src/fieldnode_core.py`). The script imports the model's `PARAMS`, derived dimensions and part solids, so the pod, shield, rail, clamp positions and projected areas used here are those in the STEP files and in drawing AST-DWG-001. It reads `bom/bom.csv` and `budget_usd` in `project.yaml`. FieldNode figures are taken from FND-CAL-001 (v0.1 for power and energy, v0.3 for mass) in the FieldNode repo. Run it from the repo root with `python docs/04-calcs/sizing.py`; it also writes `docs/04-calcs/results.csv`.

The design case is a 140 mm street light pole with the inlet plane 3.0 m above the sidewalk (AST-DDR-001 D7), one record every 5 min with a 60 s PM run (D8 and DDR-002), LoRaWAN at SF9 in EU868 through a private gateway (15 min on The Things Network), FieldNode's back plate left off (DDR-002), and ambient -10 to 50 °C.

## Assumptions

*Table 1. Main assumptions.*

| Area | Assumption | Basis |
| --- | --- | --- |
| PM sensor | SPS30 at 5 V, 55 mA typical and 65 mA maximum in measurement mode; 41 x 41 x 12 mm, 26.3 g; up to 30 s to first reading at low particle counts; recommended 10 to 40 °C and 20 to 80 % RH | Sensirion SPS30 datasheet (07/2023), checked 2026-09-25 |
| NO2 chain | Front end and ADC held on continuously, 1.5 mA at 5 V; overall gain 0.25 mV/ppb; 5 ppb (1σ) noise per 1 s sample; 10 samples per record | Assumed; the Alphasense pages could not be fetched, so these are not checked |
| T and RH | SHT45, ±0.1 °C and ±1 % RH typical | Adafruit SHT45 product page, checked 2026-09-25 |
| Margin | 1.2 on the port load, applied to the maximum SPS30 current | Judgment |
| FieldNode core | Rails 90 % efficient; SX1262 +14 dBm at 45 mA, receive 4.6 mA, two 0.1 s windows, controller 0.5 s at 8 mA per report, 33 µA sleep; 6 Ah LiFePO4 cell, 80 % usable; capacity ratios 0.70 at -20 °C and 0.80 at end of life; 7.75 Wh/day stored in the worst month, 0.8 Wh/day on a hot clear day without a sun shield; 2.41 kg; $126.00 | FND-CAL-001 v0.1 |
| Extra controller time | 1 s at 8 mA per record to run and read the sensors | Assumed |
| NO2 calibration | Field-calibrated residual MAE 3.5 ppb, taken as σ = 4.39 ppb; zero drift 0.5 ppb/month, half removed by the anchor node; 2 ppb bias moving from the reference site to a street; 6 h correlation time | Residual from [Zimmerman et al., 2018](https://amt.copernicus.org/articles/11/291/2018/); the rest assumed |
| PM humidity growth | κ-Köhler volume growth 1 + κ·aw/(1 − aw) with κ = 0.3 ± 0.1; residual after the CalRig transfer check 2 µg/m³ + 5 % | Assumed typical urban aerosol |
| Shield | 1,000 W/m² sun, ground albedo 0.2, absorptance 0.25 (aged white ASA), 15 W/m²K per plate face, view factors from the probe of 0.1 (cap), 0.1 (bottom plate) and 0.6 (other plates, 0.5 K warm); inner air speed 10 to 30 % of a 1 m/s wind | Handbook ranges; assumed |
| Mass | ASA 1.07, aluminum 2.70, stainless 7.90 g/cm³ from model volumes; FieldNode V-blocks and small clamps (0.20 kg) and back plate (0.47 kg) left off | Estimates |
| Wind | 35 m/s gust; air 1.225 kg/m³; drag coefficient 1.2 on the projected area; band preload 1,000 N (as FND-CAL-001), friction 0.3 | Screening values, not a code check |

## A. Power and energy (R9)

- **PM sensor.** 0.275 W while running at 20 % duty (60 s in 300 s) is 55.0 mW typical, or 65.0 mW at the datasheet maximum [A1].
- **Port load.** The NO2 front end and ADC add 7.5 mW continuously and the T and RH sensor 0.01 mW, for 62.5 mW typical [A2]. With the maximum SPS30 current and the 1.2 margin, the design load is 87.0 mW, against FieldNode's 100 mW design value and 115 mW ceiling [A3]. R9 is met on paper under either figure, with 13 mW left under the design value.
- **Core.** At a 5 min interval each uplink costs 52.9 mJ at SF9, and the core uses 9.0 mWh/day including sensor wake-ups and sleep, against 4.0 mWh/day for FieldNode alone at 15 min [A4].
- **Daily draw.** 2.33 Wh/day from the cell, a 97.1 mW average [A5].
- **Autonomy.** A full cell lasts 6.6 days without sun, 4.6 days at -20 °C and 5.3 days at end of cell life [A6]. The cold figure is below the 5 days FieldNode's own R6 asks of its core; AirStreet's R9 does not set an autonomy target.
- **Energy balance.** In FieldNode's worst month the cell stores 7.75 Wh/day against 2.33 Wh drawn, 3.3 times the demand [A7]. On a hot clear day without FieldNode's sun shield only 0.8 Wh is stored, a 1.53 Wh/day deficit, which a full cell covers for 10 such days in a row [A8]; the shield is required above 45 °C (DDR-002).
- **Clean air.** The SPS30 needs up to 30 s to its first reading at low particle counts, so the 60 s run (DDR-002) leaves at least 30 s of valid readings. The 30 s run of v0.1 gave 48.0 mW [A9].

## B. Data, airtime and storage (R8, R10)

- **Record.** Eight 2-byte values (PM1, PM2.5, PM10, WE, AE, T, RH, status), a 2-byte counter and 2 bytes of flags: 20 bytes, 288 records a day [B1].
- **Airtime.** With 13 bytes of LoRaWAN overhead on a 125 kHz channel, one uplink takes 72 ms at SF7, 134 ms at SF8, 247 ms at SF9, 453 ms at SF10 and 1,810 ms at SF12 [B2]. The TRL 2 figure of about 1.3 s at SF12 was low.
- **EU868 duty cycle.** The worst case, SF12, uses 0.60 % of each 5 min, so the 1 % sub-band limit is met at every spreading factor [B3]. R10 is met on paper.
- **Fair use.** On The Things Network's 30 s/day fair-use policy, a 5 min interval fits only at SF7 (20.7 s); SF8 needs 38.5 s and SF9 71.1 s [B4]. Under DDR-002 the node reports every 5 min only through a private gateway (TwinKit by default, FND-DDR-001 D7), where this limit does not apply, and every 15 min on TTN. At 15 min an uplink takes 12.8 s/day at SF8 and 23.7 s/day at SF9, inside 30 s, but 43.5 s/day at SF10, so fair use is met up to SF9 [B8].
- **US915.** The 400 ms dwell limit allows SF9 (247 ms) and not SF10 (453 ms) [B5].
- **Storage.** 7 days of store and forward take 40.3 kB of FieldNode's 16 MB flash [B6], and an hourly mean is ready within one record interval of the hour's end, at most 15 min on TTN [B7]. R8 is met on paper.

## C. NO2 error budget (R2, R3, R4)

- **Units and resolution.** 1 ppb = 1.880 µg/m³ at 25 °C; one ADC step of 62.5 µV is 0.25 ppb at the assumed gain [C1].
- **Hourly error.** The hourly terms (1σ) are noise 0.46 ppb after averaging 120 samples, calibration residual 4.39 ppb, drift 0.87 ppb and transfer bias 2.00 ppb, 4.92 ppb in all [C2]. That is a mean absolute error of 3.9 ppb (7.4 µg/m³) against the 5 ppb of R2 [C3]. R2 is at risk: every term except noise rests on literature or an assumption, and only collocation can show it.
- **Annual mean.** Random terms average out over a year, but the transfer bias, the drift residual and the collocation intercept (0.59 ppb from 14 days) do not: 2.26 ppb, or 4.25 µg/m³, against 2 µg/m³ [C4]. Meeting 2 µg/m³ would need the transfer bias held to 0.16 ppb, which no field calibration can promise [C6]. R3 is therefore withdrawn as a requirement and kept as a research question (DDR-002).
- **EU limit.** At 90 % one-sided confidence, a street's annual mean can be classified against 40 µg/m³ only if it is below 34.6 or above 45.4 µg/m³ [C5]. R4 is at risk: it holds for streets well clear of the limit but not for those near it.

## D. Radiation shield (R5)

- **Plate temperatures.** In 1,000 W/m² sun the cap runs 8.3 K and the bottom plate 1.7 K above ambient; the mean radiant excess seen by the probe is 1.30 K [D2].
- **Probe error.** With inside air at 30 % of a 1 m/s wind the probe reads 0.26 K high from radiation and 0.16 K from warmed air, 0.42 K in all; at 10 % it reads 0.38 K and 0.49 K, 0.87 K in all [D1]. The 1.5 mm plates (2 mm before v0.6) leave slightly wider gaps between plates, so a little more air passes. Both are under the 1 °C of R5, but the result depends on the inner air speed, which is assumed.
- **Humidity.** A 0.87 K warm error reads 2.4 % RH low at 50 % RH and 4.1 % RH low at 85 % RH, at 30 °C [D3]. The SHT45 alone meets ±0.5 °C and ±3 % RH, but the shield error at high humidity does not. R5 is at risk.

## E. PM2.5 error with humidity (R1)

- **RH input.** The humidity correction uses RH with an uncertainty of 4.3 % (1 % sensor and the shield error at 85 % RH) [E1].
- **Error against the bound.** Table 2 compares the combined error with the R1 bound of ±5 µg/m³ or ±30 % [E2].

*Table 2. Hourly PM2.5 error after humidity correction, µg/m³ (bound in parentheses).*

| RH | 10 µg/m³ | 25 µg/m³ | 50 µg/m³ |
| --- | --- | --- | --- |
| 50 % | 2.2 (5.0) | 3.2 (7.5) | 5.4 (15.0) |
| 70 % | 2.6 (5.0) | 4.7 (7.5) | 8.6 (15.0) |
| 80 % | 3.1 (5.0) | 6.3 (7.5) | 12.1 (15.0) |
| 85 % | 3.6 (5.0) | **7.8 (7.5)** | **15.2 (15.0)** |
| 90 % | 4.7 (5.0) | **10.8 (7.5)** | **21.4 (15.0)** |

- **Result.** R1 is met on paper up to 80 % RH at every level tested, which is also the top of the SPS30's recommended humidity range [E3]. Above 85 % RH the particles' water uptake is steep and the correction is uncertain. R1 is at risk for humid climates and nights.

## F. Geometry, area and mass (R11, R13)

- **Fit.** Inlet plane 3,000 mm above the sidewalk, inside the EU 1,500 to 4,000 mm range; 140° V-saddles and bands cut to length fit 80 to 200 mm poles; no drilling [F1]. R11 is met by design.
- **Layout.** FieldNode's whip clears the pod's drip lid by 15 mm (23 mm in v0.2, before FieldNode's antenna moved 28 mm toward the pod and the pod moved 20 mm away), the clamps are 375 mm apart, the node is 706 mm tall and it stands 172 mm out from the pole face (173 mm before the rail was thinned) [F2].
- **Area.** Rasterizing the model gives 0.139 m² seen from the street and 0.054 m² along it, against 0.15 m² [F3] (0.143 m² in v0.5, 0.126 m² in v0.2). FieldNode's constructable bracket, the adapter plates and the cross arm add to the outline; the plate windows above and below the enclosure take a little off it. R13's area limit is met on paper.
- **Mass.** FieldNode core as used 1.89 kg (FieldNode's base node of 2.45 kg less its back plate, V-blocks and bands, 0.56 kg); rail 0.19 kg; adapter plates 0.21 kg; cross arm 0.19 kg; V-saddles 0.10 kg (6 walls and 40 % infill, 57 % of solid); pod shell and floor 0.37 kg; shield plates, cap and spacers 0.23 kg; bands 0.10 kg; shield rods 0.06 kg; sensors, front end, probe, cables, glands, inserts and fixings 0.29 kg [F4]. In all 3.62 kg on the pole and 3.78 kg with FieldNode's sun shield at a hot site, against 4.0 kg including the shield: 0.22 kg of margin. The sensor head and mount are 1.73 kg [F5]. R13 is met on paper; the pole owner of the first site is still to confirm the load.
- **Lightening.** The four steps of AST-DDR-003, A1 take 0.22 kg off: 3.84 to 3.62 kg without the sun shield and 4.00 to 3.78 kg with it [F8]. The saddles save 0.08 kg, the thinner rail 0.05 kg, the plate windows 0.06 kg and the thinner shield plates 0.04 kg. The "about 3.6 kg" of AST-DDR-003, A1 is the node without the sun shield; with it the lightened node is 3.78 kg, close to the 3.76 kg estimated when the recommendation was reviewed.
- **Why it rose.** FieldNode's constructable core is 0.15 kg heavier as AirStreet uses it, and the parts that make AirStreet buildable (adapter plates in place of adapter bars, the cross arm in place of the short shield arm, larger saddles, the separate pod floor, spacers and fixings) add the rest [F6]. Option (c) of AST-DDR-003, A1 was accepted on 2026-10-02: the limit is 4.0 kg and the four lightening steps are now in the design.
- **Bands.** Each band runs 487 mm round the 140 mm design pole and its saddle, 326 mm round an 80 mm pole and 664 mm round a 200 mm pole, plus about 100 mm for the housing and tail [F7].

## G. Wind and mounting

- **Load.** A 35 m/s gust gives 750 Pa and 125 N on the node at about 3.33 m, or 416 N·m at the pole base [G1]. The pole's capacity is for its owner to confirm.
- **Clamps.** The downward load of 76 N (weight and wind on the tilted panel) compares with 1,885 N of friction from two bands, a factor of 25 [G2]. Twist about the pole from wind on the offset shield is 2.42 N·m against 132 N·m [G5]. Both rest on the assumed 1,000 N band preload.
- **Cross arm.** The 30 x 30 x 3 mm angle carries the shield (0.30 kg, 12.1 N of wind) 200 mm to the right of the rail and the pod (0.46 kg) 90 mm to the left: 0.60 N·m vertical and 2.42 N·m horizontal at the rail, 4.4 MPa [G3]. Its two M5 bolts each take about 67 N in the gust [G4].
- **Rail and pod.** The rail at the lower clamp carries 26.6 N and 2.73 N·m, 25.6 MPa in the 40 x 4 mm bar (16.4 MPa in the 40 x 5 mm bar of v0.5) [G6]. Each of the pod's two hanging screws takes about 11 N in the gust, far below what an M5 heat-set insert in ASA holds; the insert pull-out is to be checked at TRL 4 [G7]. Every stress is far below the roughly 150 MPa yield of 6063 aluminium.

## H. Service and environment (R12, R16)

- **Service time.** Under DDR-002 the pod is exchanged whole: ladder 5 min, unplug two M12 plugs and the probe lead 1.5 min, release the pod 1.5 min, fit the pre-collocated pod 2 min, reconnect and check glands 1.5 min, uplink check 2 min: about 14 min against 15 min [H1]. The exchange pod arrives with its collocation and CalRig record, and the returned pod is serviced and recollocated at the reference site [H2]. R16 is met on paper, with a small margin.
- **Temperature range.** FieldNode is rated for -20 to +45 °C ambient and reaches 58.7 to 73.3 °C inside at 45 °C, while AirStreet's R12 asks for -10 to 50 °C [H3]. The SPS30's recommended range is 10 to 40 °C and 20 to 80 % RH, with absolute limits of -10 to 60 °C and 0 to 95 % RH [H4]. Under DDR-002 FieldNode's sun shield is required at sites above 45 °C, so R12 asks for it there; FieldNode has now designed it (FND-DDR-003), and it fixes to AirStreet's adapter plates (AST-DDR-003). R12 stays at risk; condensation and insects in the pod remain unverified.
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

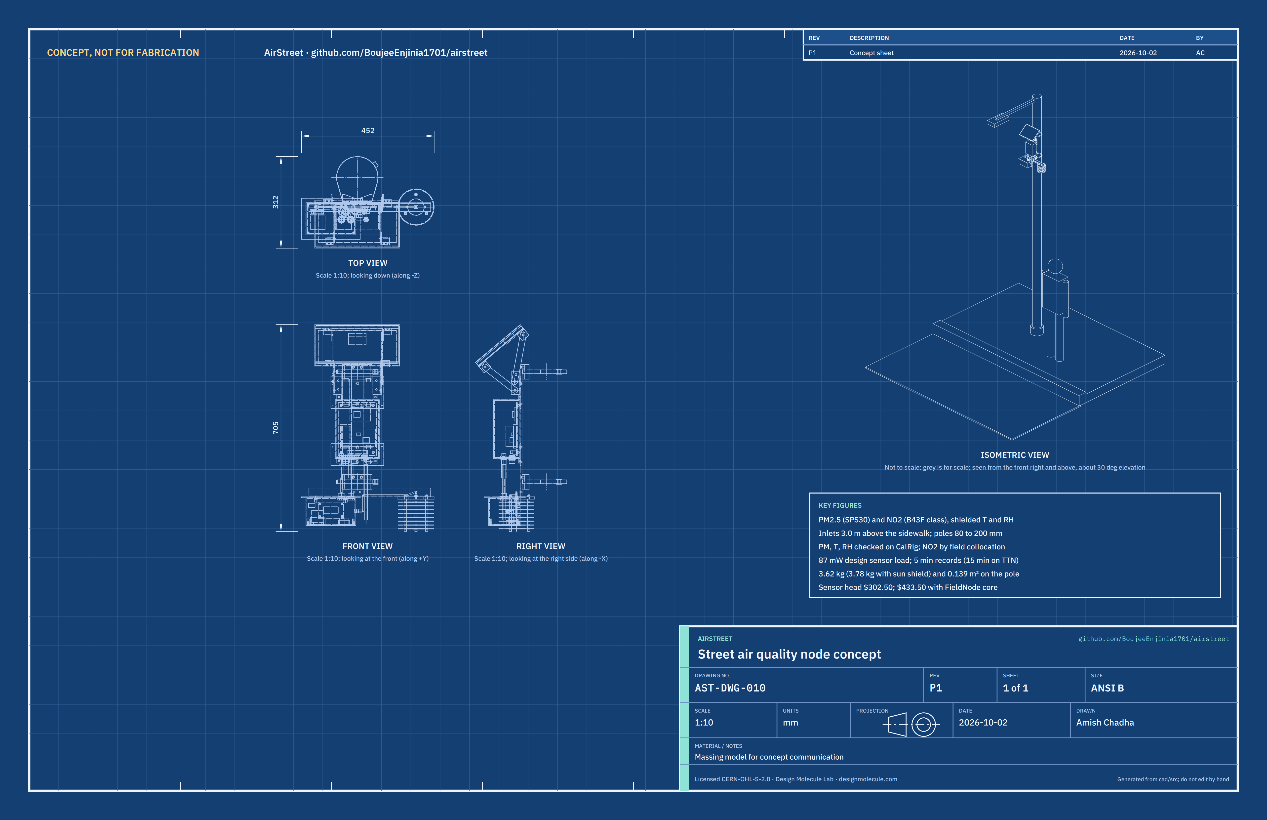
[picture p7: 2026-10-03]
media/concept-blueprint.png

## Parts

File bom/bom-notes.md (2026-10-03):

# BOM notes

Every line in `bom.csv` is priced at quantity 1 (TRL 3). Item numbers match the callouts in `media/exploded.png` and the part keys in `cad/src/model.py`. Two prices were checked on 2026-09-25: the Sensirion SPS30 at SparkFun ($60.50, or $57.48 at 25 or more) and the Adafruit SHT45 breakout ($12.50). The NO2 sensor and front-end prices are indicative estimates; the maker's pages could not be fetched. Other lines are indicative prices from a supplier type.

Totals, as printed by `docs/04-calcs/sizing.py` (AST-CAL-001 v0.6, section I), updated 2026-10-02:

| Scope | Cost | Against |
| --- | --- | --- |
| AirStreet sensor head (lines 3 to 11) | $302.50 | $285 value-engineering target (`budget_usd`): $17.50 over |
| FieldNode core (lines 1 and 2) | $131.00 | Costed in the FieldNode repo (AST-DDR-001 D1): FieldNode's $139.00 less its unused $8.00 pole mounting kit |
| Whole node | $433.50 | For reference |

Value-engineering target: USD 285. Estimated cost of the constructable design: USD 302.50 (USD 17.50 over the target).

How the sensor head got here: $265 at TRL 2; $283.00 at TRL 3 (checked SPS30 price, V-saddles for 80 to 200 mm poles, shorter cables); $285.00 under AST-DDR-002 (adapter bars for the panel bracket); $303.00 when the design was made constructable (AST-DDR-003: adapter plates and cross arm, band stock, spacers, probe tube and lead, inserts, glands, probe socket, terminal block and fixings); and $302.50 on 2026-10-02 when the four lightening steps of AST-DDR-003, A1 were carried in. In that last step line 3 went from $21.00 to $21.50 (the 40 x 4 mm rail saves about $0.50 of metal, priced by weight, and the saddles are repriced at about $3.00 of filament at 40 % infill, the $1.50 used before being low; the plate windows save weight, not purchase cost) and line 8 from $10.00 to $9.00 (the 1.5 mm shield plates use about 0.04 kg less ASA at about $30/kg).

Mass, as printed by `sizing.py` [F4], [F5], [F8]: 3.62 kg on the pole and 3.78 kg with FieldNode's sun shield, against the R13 limit of 4.0 kg including the shield (it was 3.84 kg and 4.00 kg before the lightening). The lightened parts weigh: rail 0.19 kg (was 0.24), adapter plates 0.21 kg (was 0.27), V-saddles 0.10 kg at 40 % infill (0.18 kg solid), shield plates, cap and spacers 0.23 kg (was 0.27).

Line 4, the pod with its sensors, is also the service exchange unit, so a practical fleet needs spare pods; these are not in the per-node BOM. FieldNode's sun shield, required at sites above 45 °C, is costed in FieldNode. CalRig time, reference-station collocation and replacement NO2 sensors (about every 2 years, estimate) are running costs and are not included. The radio band and FieldNode antenna are set when the first partner is agreed (US915 in North America, EU868 in Europe; decision of 2026-10-02); the BOM does not yet name one.

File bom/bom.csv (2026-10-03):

item | qty | spec | supplier | unit_cost_usd | make_buy | notes
1 FieldNode core (enclosure, cell, radio) | 1 | FieldNode per FND BOM (constructable, FND-DDR-003): IP65 enclosure 150 x 90 x 200 mm with four external lugs, LiFePO4 3.2 V 6 Ah cell, MPPT power modules, STM32WL LoRaWAN module, two M12 5-pin ports, antenna; panel tilt bracket of plate clips, posts, struts and panel clips; FieldNode's pole mounting kit (back plate, V-blocks, band clamps) not used (DDR-002) | Built from the FieldNode BOM (fieldnode repo) | 131.00 | make | FND BOM total at TRL 3 ($139.00, FND-CAL-001 v0.3) less its line 12 pole mounting kit ($8.00), which AirStreet does not use; costed in FieldNode and outside the AirStreet sensor-head budget (DDR-001 D1); FieldNode sun shield (FND line 14) needed at sites above 45 degC (DDR-002, costed in FieldNode); built to the FieldNode build plan FND-BLD-001 | [' 40 to 60 mm clamps and back plate are not used here; FieldNode sun shield needed at sites above 45 degC (DDR-002', ' costed in FieldNode)']
2 FieldNode 6 W panel hood | 1 | 6 W panel on the FieldNode bracket (plate clips, posts, struts, panel clips), 40 deg tilt, as sun and rain hood; the plate clips bolt to the AirStreet upper adapter plate | Included in line 1 | 0.00 | make | Cost counted in line 1
3 Band clamps, saddles, rail, adapter plates and cross arm | 1 | Two stainless 12.7 mm worm-drive bands cut to length from a roll (about 0.6 m each for 80 to 200 mm poles) with two housings; two printed ASA V-saddles 100 x 50 x 24 mm with a 140 deg V and a band groove (6 walls and 40 % infill); aluminium flat bar rail 40 x 4 x 451 mm; two 3 mm aluminium adapter plates (180 x 75 and 180 x 110 mm) drilled to FieldNode's back plate hole pattern and with two lightening windows each (24 x 59 and 24 x 94 mm); aluminium angle 30 x 30 x 3 mm cross arm 415 mm | Metal stockist and hardware store; saddles printed | 21.50 | buy | Indicative; band and housings about $8, rail about $3.50 (40 x 4 mm bar is 20 % less metal than 40 x 5 mm, priced by weight at about $4 for 40 x 5), plates about $4 (same 3 mm sheet; the windows are cut out by hand and save weight, not purchase cost), arm about $3, saddles about $3.00 of filament (0.10 kg ASA at 40 % infill at about $30/kg; the $1.50 of v0.3 was low); lightening steps of AST-DDR-003 A1 applied 2026-10-02 (was $21.00); AST-DDR-003 replaced the two adapter bars and the 20 x 8 mm shield arm with the adapter plates and cross arm (was $17.00)
4 Sensor pod: shell, sensor floor and mesh | 1 | Exchange unit (DDR-002): printed ASA shell 170 x 110 x 92 mm (walls, roof and 200 x 140 x 3 mm drip lid in one, 3 mm walls, open bottom) and printed ASA sensor floor 170 x 110 x 3 mm with two inlet slots, the PM sensor cradle and the NO2 sensor collar; stainless insect mesh 160 x 100 mm under the floor | Self (filament from a 3D printing supplier) | 12.00 | make | Material cost only (about 0.34 kg ASA at about $30/kg plus mesh); AST-DDR-003 split the floor from the shell so the sensors fit from below
5 Optical PM sensor (SPS30 class) | 1 | Sensirion SPS30, PM1 to PM10, I2C or UART, 5 V, 41 x 41 x 12 mm, with interface cable | SparkFun (retail quantity 1) or an electronics distributor | 60.50 | buy | SparkFun price checked 2026-09-25 ($57.48 at 25+); was $45 at TRL 2
6 Electrochemical NO2 sensor (B4 class) | 1 | Alphasense NO2-B43F class four-electrode sensor with ozone filter | Alphasense distributor | 90.00 | buy | Indicative estimate; not checked (maker site not reachable); replace about every 2 years (estimate)
7 NO2 front end and 16-bit ADC | 1 | Alphasense ISB class four-electrode potentiostat board with ADS1115 class 16-bit ADC, on the always-on 5 V port | Alphasense distributor | 60.00 | buy | Indicative estimate; bought for the first units (DDR-001 D5); open two-channel design about $25 is a later option
8 Multi-plate radiation shield | 1 | Eight white ASA plates 120 mm OD, 56 mm ID, 1.5 mm, 13 mm pitch; 124 x 8 mm cap; 24 printed spacers 8 mm OD; three M5 stainless rods 125 mm with nuts | Self (filament) and hardware store (rods) | 9.00 | make | Material cost only: about 0.23 kg ASA at about $30/kg ($7.00) and rods and nuts about $2.00; plates thinned from 2 to 1.5 mm (AST-DDR-003 A1, 2026-10-02), saving about 0.04 kg of ASA (was $10.00); spacers added by AST-DDR-003 (was $9.00)
9 Temperature and humidity sensor | 1 | Sensirion SHT45 on a breakout board, I2C, 3.3 to 5 V, glued to the end of a 6 mm aluminium tube 77 mm long that passes through the shield cap and the cross arm | Adafruit (product 5665) or an electronics distributor | 13.50 | buy | Adafruit price checked 2026-09-25 ($12.50); tube about $1 (AST-DDR-003)
10 Sensor cables M12 and probe lead | 2 | Two 0.5 m shielded cables with M12 5-pin A-coded plug, open end through an M16 gland in the pod roof; one 4-core shielded probe lead about 0.5 m from the probe tube, ending in an M8 4-pin plug for the socket on the pod wall | Industrial connector distributor | 10.00 | buy | Indicative price; $8.00 per M12 cable plus $4.00 for the probe lead with its M8 plug, split across the two lines (AST-DDR-003)
11 Fasteners and consumables | 1 | Stainless: 4 x M5 x 16 countersunk screws (saddles), 4 x M5 x 16 countersunk screws with nyloc nuts (adapter plates), 2 x M5 x 12 button-head screws with nyloc nuts (cross arm), 4 x M5 x 10 pan-head screws (pod and cap); 8 x M5 and 8 x M3 brass heat-set inserts; 4 x M3 x 8 screws (floor), 4 x M3 x 6 standoffs (front end); pod glands 2 x M16; M8 4-pin panel socket for the probe lead; small terminal block; desiccant sachet, conformal coating, cable ties | Hardware store | 16.00 | buy | Indicative price; AST-DDR-003 added the fixings, inserts, glands, probe socket and terminal block (was $8.00)

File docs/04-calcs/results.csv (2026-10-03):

id | value | target | status
R1 | Within the bound up to 80 % RH on paper; outside it above that | +/-5 ug/m3 or +/-30 % hourly after humidity correction | At risk
R2 | Hourly MAE about 3.9 ppb (budget of assumed terms) | 5 ppb or less hourly MAE, 0 to 200 ppb | At risk
R3 | Annual uncertainty 4.2 ug/m3 (1 sigma); kept as a research question | Withdrawn as a requirement (DDR-002) | Withdrawn
R4 | Decisive outside 34.6 to 45.4 ug/m3 | Classify vs 40 ug/m3 with 90 % confidence | At risk
R5 | SHT45 +/-0.1 degC, +/-1 % RH typical; shield error 0.42 to 0.87 K at 1 m/s | +/-0.5 degC, +/-3 % RH; radiation error 1 degC or less | At risk
R6 | CalRig for T, RH and PM; 14-day NO2 collocation and every 6 months (DDR-001 D3) | Stated method per node | Met by design
R7 | Raw WE, AE, PM, T, RH and a calibration version tag | Raw signals kept | Met by design
R8 | 5 min records (15 min on TTN, fair use met up to SF9); hourly mean within one interval; 7 days = 40.3 kB of 16 MB | 5 min on a private gateway, 15 min on TTN; hourly within 15 min; 7 days | Met on paper
R9 | Design load 87.0 mW at the ports; 2.33 Wh/day drawn against 7.75 Wh stored in the worst month; 6.6 days without sun | 115 mW or less; energy neutral at FieldNode design sun hours | Met on paper
R10 | 0.082 % at SF9, 0.60 % at SF12 | Below 1 % per EU868 sub-band | Met on paper
R11 | 80 to 200 mm poles, V-saddles and bands; inlet 3.0 m | 80 to 200 mm, no drilling, inlets 1.5 to 4 m | Met by design
R12 | FieldNode sun shield required above 45 degC ambient (designed in FND-DDR-003, fixes to the AirStreet adapter plates); SPS30 recommended range 20 to 80 % RH; condensation and insects unverified | Outdoors, -10 to 50 degC; FieldNode sun shield above 45 degC; mesh, drip lid, IP65 core | At risk
R13 | 3.78 kg with the sun shield (3.62 kg without); 0.139 m2 frontal | 4.0 kg or less including the sun shield; 0.15 m2 or less | Met on paper
R14 | Levels, T and RH only | No images, audio or identifiers | Met by design
R15 | Sensor head $302.50; $433.50 with the FieldNode core | Sensor head $285 value-engineering target (budget_usd) | Over the value-engineering target by $17.50
R16 | About 14 min for a pod exchange; no recollocation at the pole | Pre-collocated pod exchanged in 15 min at the pole with hand tools | Met on paper

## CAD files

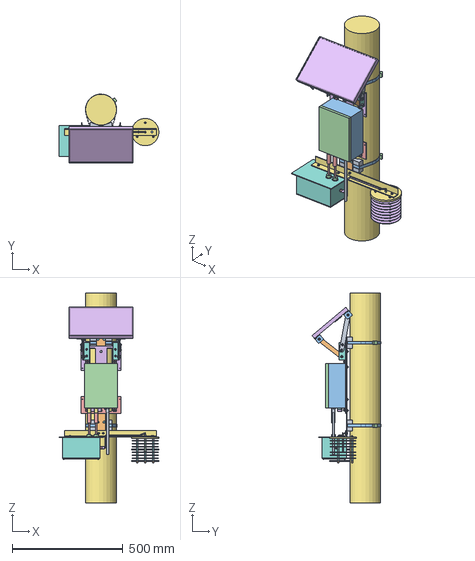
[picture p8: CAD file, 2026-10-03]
cad/step/airstreet-assembly.step
452.0 x 312.3 x 950.0 mm

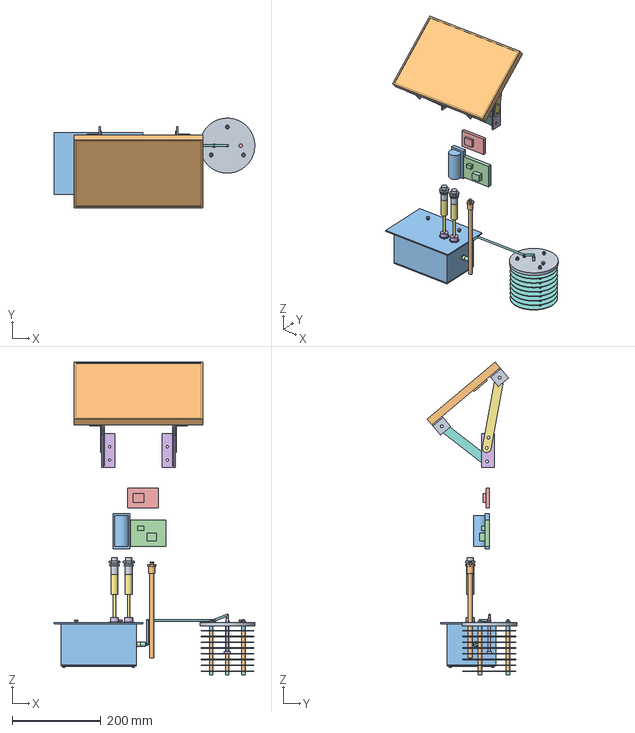
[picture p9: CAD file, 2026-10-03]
cad/step/airstreet-sensor-head.step
452.0 x 202.0 x 704.5 mm

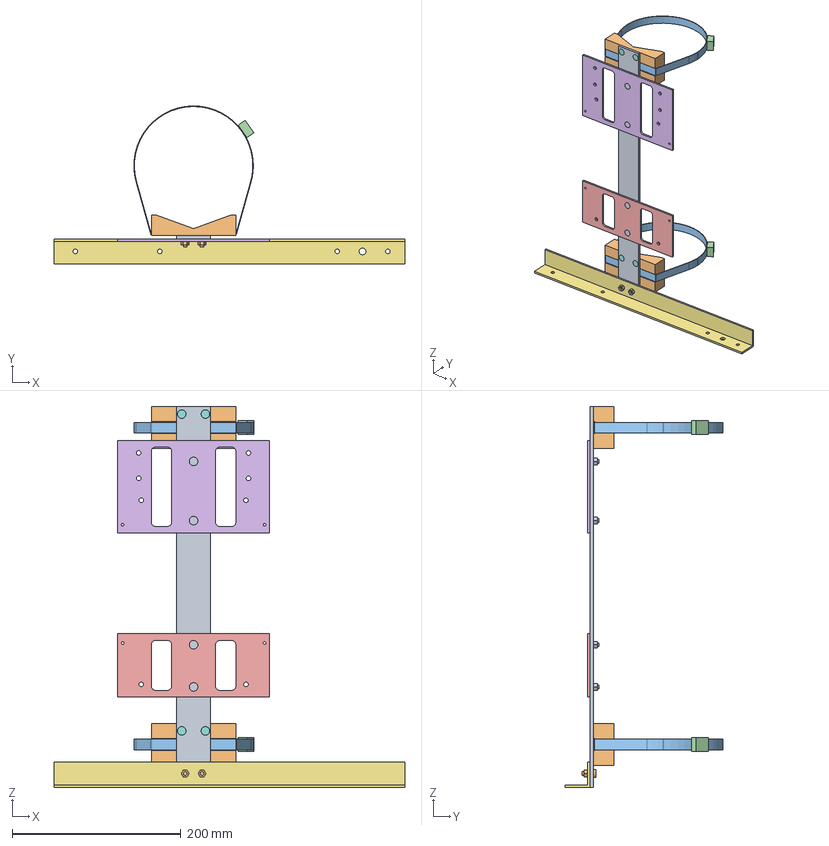
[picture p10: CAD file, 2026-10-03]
cad/step/airstreet-mount.step
415.0 x 187.3 x 451.0 mm

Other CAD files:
cad/stl/airstreet-assembly.stl
cad/stl/airstreet-mount.stl
cad/stl/airstreet-sensor-head.stl

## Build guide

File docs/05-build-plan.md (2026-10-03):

---
doc_id: AST-BLD-001
title: AirStreet prototype build plan
project: AirStreet
doc_type: Build plan
version: "0.3"
status: Draft
date: '2026-10-02'
author: Amish Chadha
license: CERN-OHL-S-2.0
revisions:
  - version: "0.1"
    date: '2026-09-30'
    author: Amish Chadha
    change: First build plan, with pictures by component and step; design made constructable (AST-DDR-003)
  - version: "0.2"
    date: '2026-10-02'
    author: Amish Chadha
    change: "Section 2: AST-DDR-003 accepted by Amish (2026-10-02)"
  - version: "0.3"
    date: '2026-10-02'
    author: Amish Chadha
    change: "Lightening steps of AST-DDR-003 A1 carried in: 40 x 4 mm rail, windows in the adapter plates, 1.5 mm shield plates and longer spacers, saddles at 40 % infill; mass and cost figures updated; pictures regenerated"
---

# AirStreet prototype build plan

**Plan, not yet built.** How to build the first proof-of-concept prototype, component by component. Building and testing to it is TRL 4 work. Decisions still to be made are kept in the design decisions register ([docs/06-design-decisions.md](06-design-decisions.md)), not here.

## 1. What you are building

Figure 1. Every component, pulled apart and numbered in build order

*Figure 1. Every component pulled apart and numbered in build order; 18, FieldNode's sun shield, is fitted only at hot sites.*

The prototype is one AirStreet node on a short length of 140 mm street light pole (any pole from 80 to 200 mm will do). A FieldNode core, the grey box with its solar panel above it, hangs on an aluminium rail that two bands clamp to the pole. Below the box a cross arm carries the sensor pod on the left, with its particle and NO2 sensors behind insect mesh, and a stack of white plates on the right that shades the temperature and humidity probe. Figure 1 shows the 18 components in the order you make or fit them. Nine are made in a small workshop: the rail, two V-saddles, two adapter plates, the cross arm, the pod shell, the sensor floor, the shield plates with their spacers, and the shield cap with the probe tube. The FieldNode core is built to FieldNode's own build plan. Everything else is bought: bands, sensors, the NO2 front end, cables, glands, mesh and fixings. The work is sawing, drilling, countersinking and tapping aluminium bar, angle and sheet, 3D printing in ASA, setting heat-set inserts, and wiring bought sensor boards with screw terminals. The sensor head parts cost about $302.50 from the bill of materials.

> **Safety:** The FieldNode core holds a lithium iron phosphate cell; follow the safety stops of FieldNode's build plan as well as section 6 here. The NO2 sensor contains an acid electrolyte: do not open, crush or heat it. Cut aluminium and band ends are sharp: deburr everything and wear gloves. Printing ASA and setting heat-set inserts give off fumes; work in a ventilated space. A street light pole carries mains voltage inside: this plan builds on a pole stub on the bench only.

## 2. What changed to make it buildable

The concept showed what the node does; some of its parts could not be made or fixed as drawn, and the FieldNode core it hangs from has since been made buildable in its own right. Each change below keeps what the node does, and all of them are recorded in decision record AST-DDR-003, which Amish accepted on 2026-10-02.

*Table 1. Changes from the concept.*

| Component | The concept had | The buildable design has | Why |
| --- | --- | --- | --- |
| Enclosure to rail | The enclosure bolted straight to a 40 mm rail, and two narrow bars for the panel bracket | Two 3 mm adapter plates on the rail, drilled like FieldNode's back plate for its four lugs, its two plate clips and its sun shield (Figures 4 to 7) | FieldNode's lugs are 124 mm apart and its bracket now starts from clips on a flat plate |
| V-saddles | A round seat cut to fit only the 140 mm pole | A 140° V that seats every pole from 80 to 200 mm on both faces (Figures 3 and 3a) | The pole bears on the V's faces, never on its edges |
| Bands | Rings round the pole with no path past the saddles; one clamp for 80 to 200 mm | Band cut to length from a roll, running in a groove across the back of each saddle (Figure 3a) | The band pulls the saddle onto the pole and cannot slide off |
| Shield arm and pod fixing | A short bar touching the rail's edge; no fixing for the pod | One angle cross arm bolted to the rail; pod and shield hang under it on screws from above (Figures 8 and 9) | Every screw is reached from above; a pod exchange is two screws and three plugs |
| Pod position | 70 mm left of the pole | 90 mm left, so FieldNode's antenna hangs 15 mm clear of the drip lid (Figure 18) | FieldNode's antenna moved 28 mm toward the pod |
| Pod | A closed box with the sensors floating inside | A printed shell open at the bottom and a sensor floor that carries both sensors, screwed on from below over the mesh (Figures 11 to 13) | The sensors can be fitted and the floor comes off as one unit |
| Cable entries | Cables ending on the drip lid | Two glands in the pod roof under FieldNode's ports, and a plug-in socket for the probe lead (Figure 18) | The pod unplugs for exchange |
| Radiation shield | Plates on rods with nothing between them; no fixing for the cap or the probe | Spacers between the plates, rods through the cap, the cap screwed under the arm, and the probe on a tube through the cap (Figures 15 and 16) | The 13 mm plate spacing holds and the probe hangs in the middle |
| Rail | 565 mm | 451 mm, ending at the cross arm | Nothing fixed to the part below the arm |
| Weight | 3.84 kg on the pole, 4.00 kg with FieldNode's sun shield | A 40 x 4 mm rail (was 40 x 5), windows in both adapter plates, 1.5 mm shield plates (was 2 mm) and saddles printed at 40 % infill: 3.62 kg, 3.78 kg with the sun shield (Figures 2, 4, 5 and 14) | The node must stay at or under 4.0 kg on the pole with the sun shield, with some margin |

## 3. Making the components

Make and check each component before the assembly step that needs it. Sizes are in millimetres. "Left" and "right" are as seen standing in the street, looking at the node; "front" is the side facing the street and "back" the side facing the pole. Workshop tolerance is 0.5 mm unless a step says otherwise; drawings do not carry tolerances before TRL 4.

### 3.1 Rail

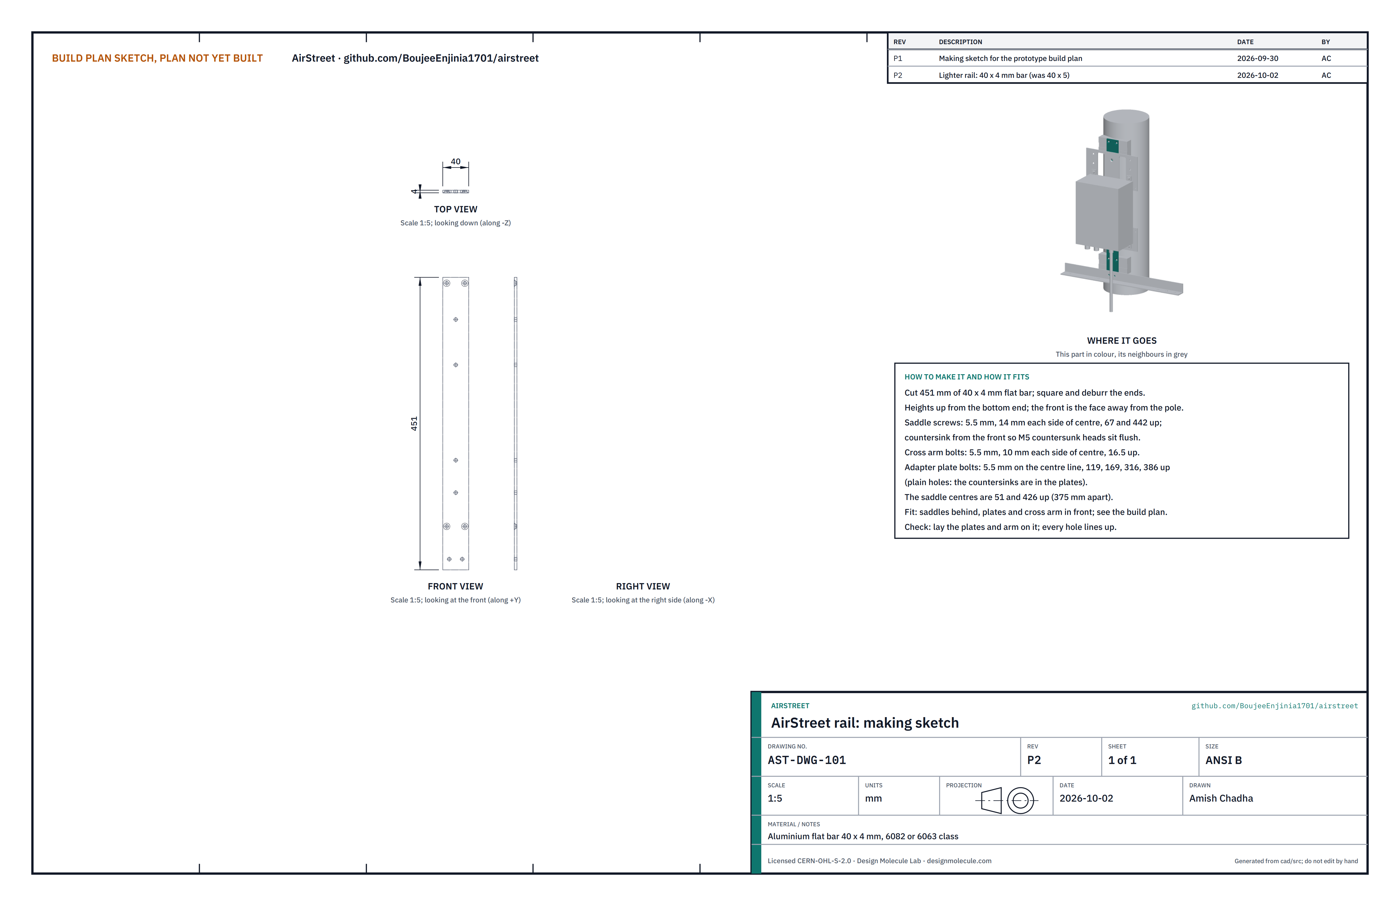
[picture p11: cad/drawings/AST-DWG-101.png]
Figure 2. Making sketch of the rail


*Figure 2. Rail making sketch (AST-DWG-101).*

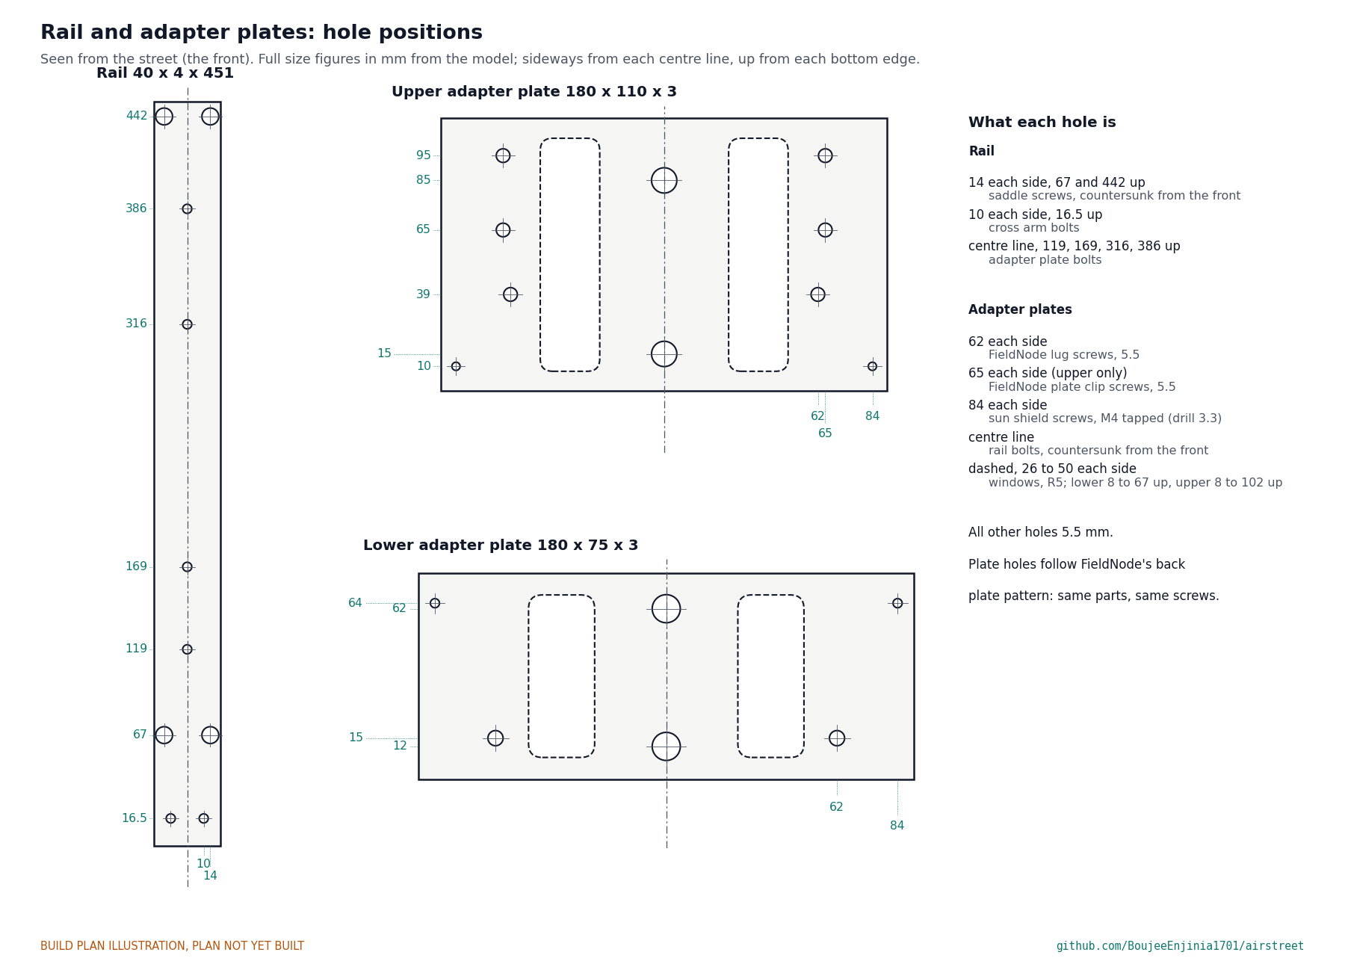
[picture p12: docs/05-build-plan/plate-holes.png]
Figure 2a. Hole positions in the rail and the adapter plates


*Figure 2a. Hole positions in the rail and both adapter plates, full size figures, seen from the front.*

**What it is and what it is made from.** The upright bar that carries everything: saddles behind it, adapter plates and cross arm in front. Aluminium flat bar 40 x 4 mm, 6082 or 6063 class.

**How to make it.**

1. Cut 451 mm and square and deburr the ends. The end nearer the pod is the bottom.
2. Scribe a centre line down the front face. Mark every hole from Figure 2a, heights up from the bottom end.
3. Saddle screw holes: four 5.5 mm holes, 14 each side of centre, at 67 and 442 up. Countersink them from the front so M5 countersunk heads sit flush.
4. Adapter plate bolt holes: four 5.5 mm holes on the centre line at 119, 169, 316 and 386 up (plain; the countersinks are in the plates).
5. Cross arm bolt holes: two 5.5 mm holes, 10 each side of centre, 16.5 up.
6. Deburr every hole on both faces.

**How it fits the parts next to it.** The saddles sit flat on its back face, centred 51 and 426 up (375 apart). The adapter plates and the cross arm sit flat on its front face.

**Check before moving on.** Lay the plates and the arm on it and look through each hole: every hole lines up without forcing a screw.

### 3.2 V-saddles (make 2)

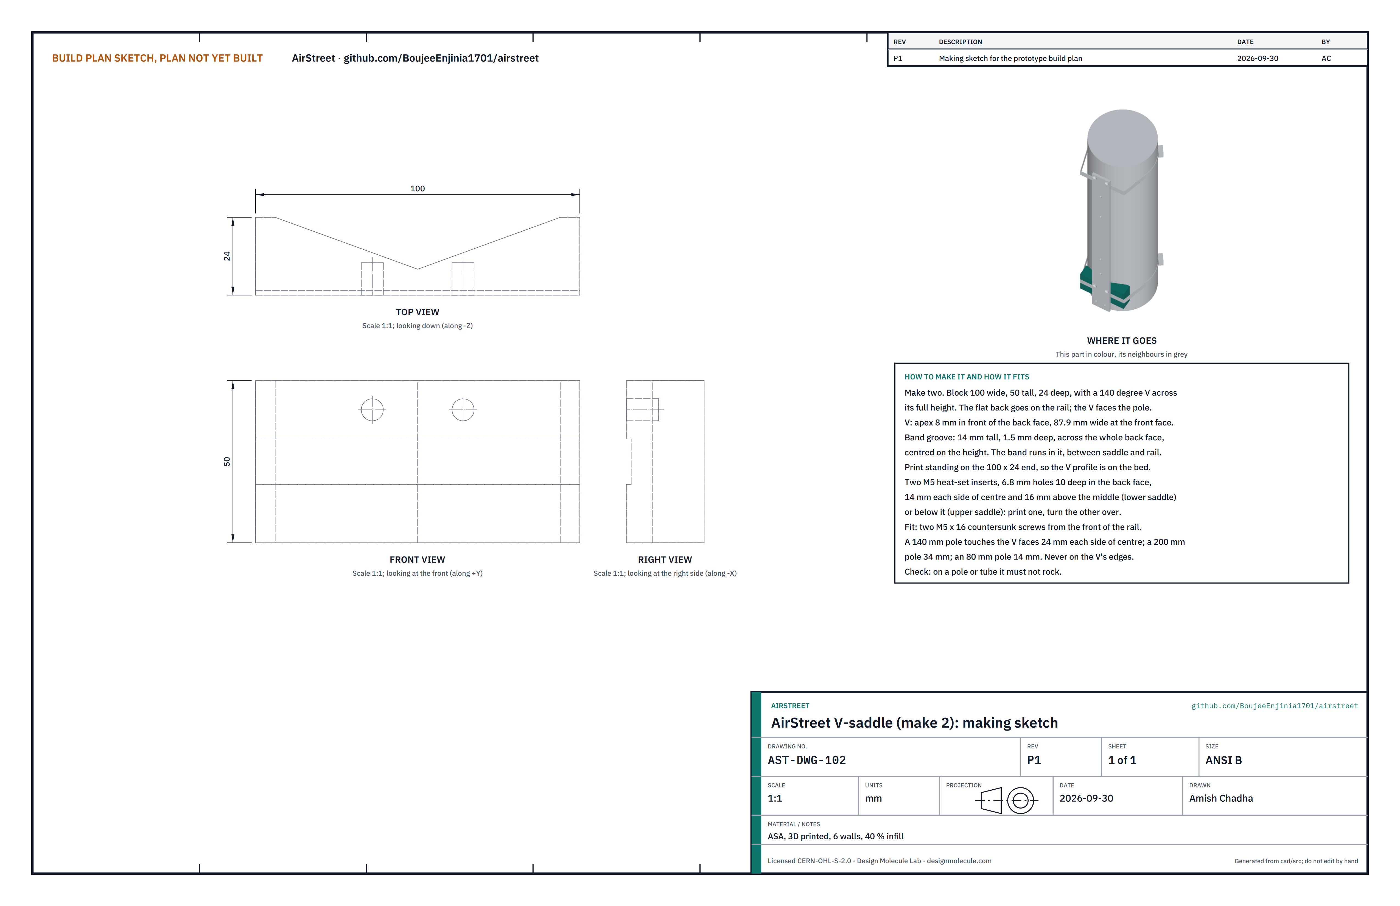
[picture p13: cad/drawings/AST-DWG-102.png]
Figure 3. Making sketch of the V-saddle


*Figure 3. V-saddle making sketch (AST-DWG-102).*

**What it is and what it is made from.** A printed block with a wide V that the pole sits in, one at each band. ASA, printed with six walls and 40 % infill.

**How to make it.**

1. Print each saddle standing on its 100 x 24 end, so the V profile lies on the bed: 100 wide, 50 tall, 24 deep, with a 140° V whose point is 8 mm in front of the back face and which is 87.9 mm wide at the front face.
2. The band groove, 14 tall and 1.5 deep, runs across the whole back face at mid-height; print it in.
3. Two 6.8 mm holes, 10 deep, in the back face, 14 each side of centre and 16 off the middle. Print one saddle with them above the middle (the lower saddle) and one below (the upper saddle), or print two the same and turn one over.
4. Press an M5 heat-set insert into each hole with a soldering iron and insert tip, square to the face, flush or 0.2 below.

**How it fits the parts next to it.**

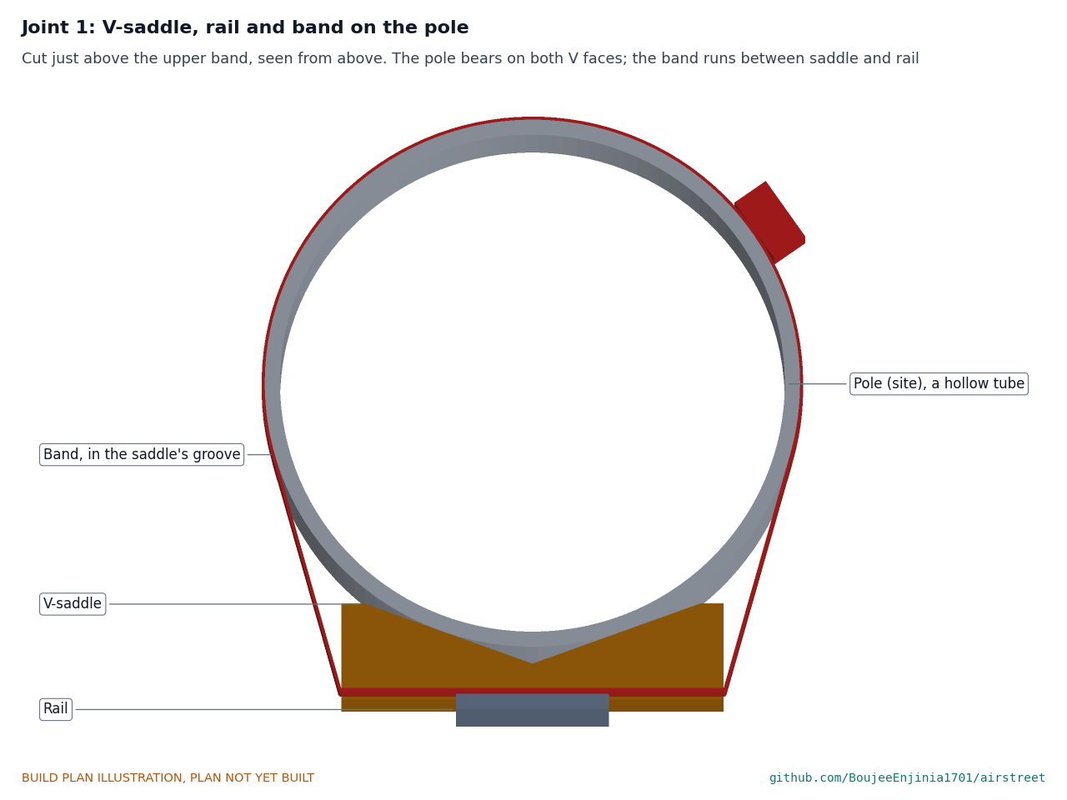
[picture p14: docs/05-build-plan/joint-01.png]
Figure 3a. Joint 1: V-saddle, rail and band on the pole


*Figure 3a. Seen from above. The pole bears on both faces of the V; the band runs round the pole and through the groove between saddle and rail.*

The back face sits flat on the back of the rail, held by two M5 x 16 countersunk screws from the front of the rail into the inserts. A 140 mm pole touches the V faces 24 mm each side of centre; a 200 mm pole 34 mm out, an 80 mm pole 14 mm out. The pole never touches the bottom of the V or its outer edges.

**Check before moving on.** Held against a pole or a tube, the saddle must not rock; you should see light at the bottom of the V.

### 3.3 Adapter plates (a lower and an upper)

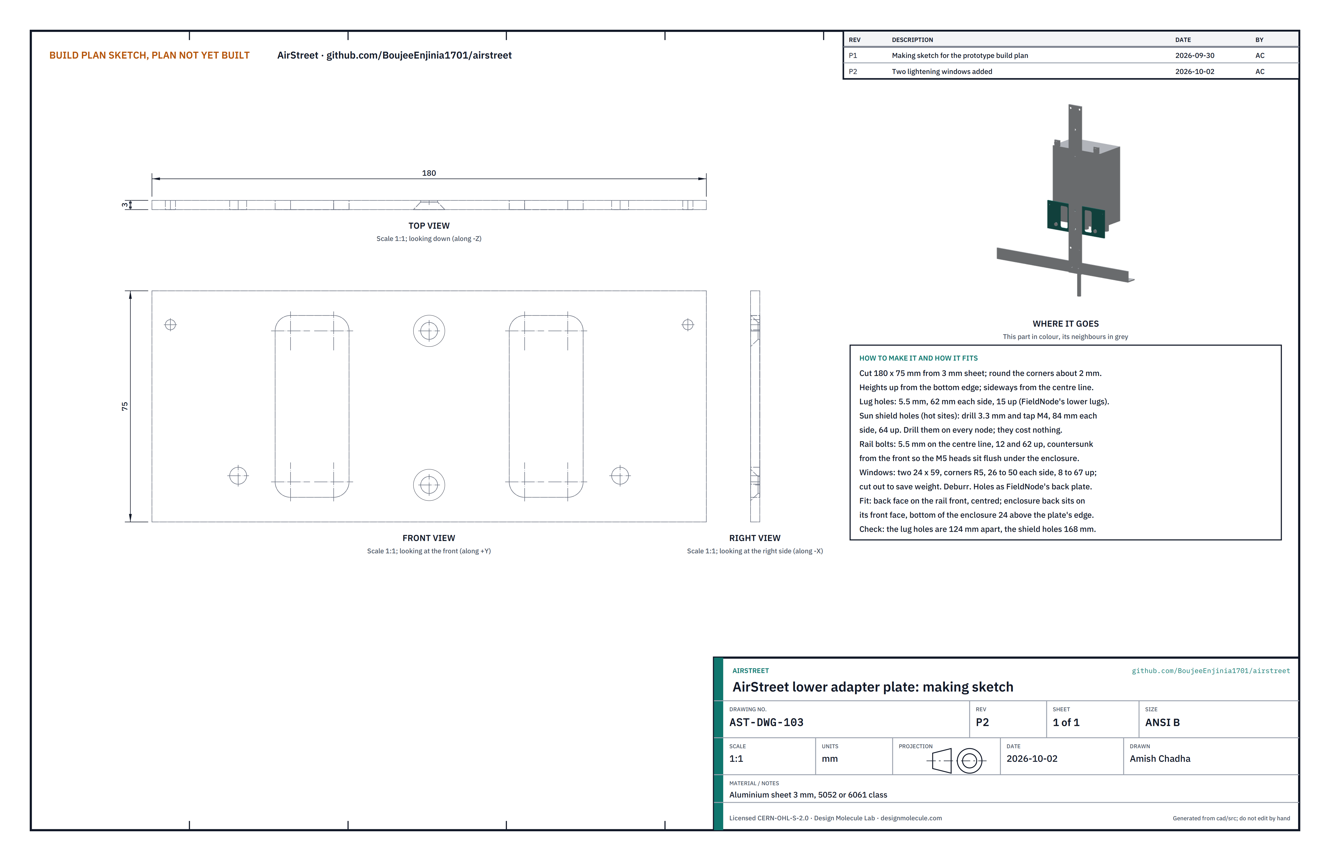
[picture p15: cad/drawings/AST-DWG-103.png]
Figure 4. Making sketch of the lower adapter plate


*Figure 4. Lower adapter plate making sketch (AST-DWG-103).*

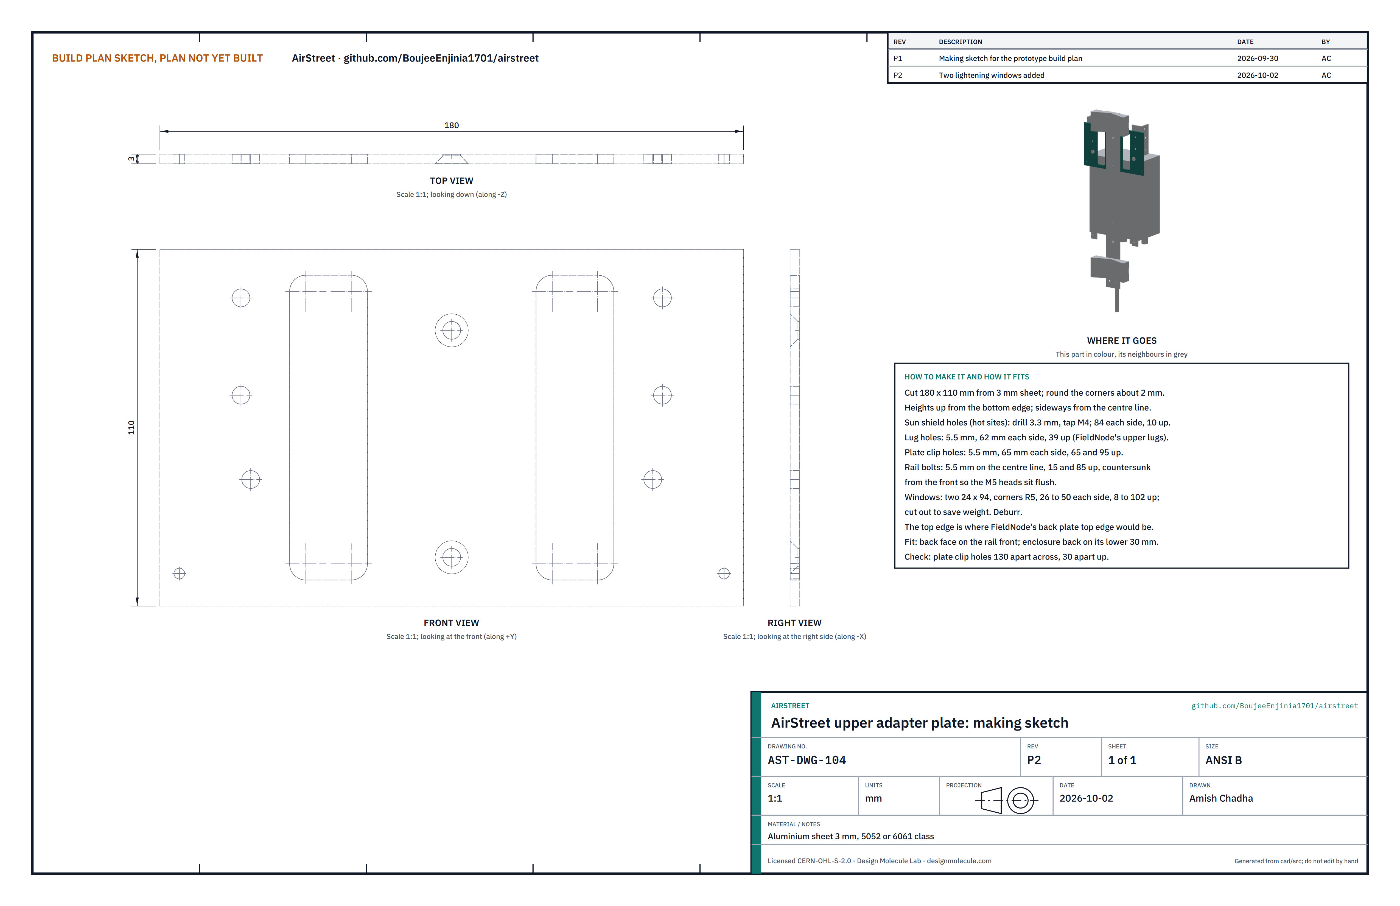
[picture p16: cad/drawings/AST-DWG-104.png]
Figure 5. Making sketch of the upper adapter plate


*Figure 5. Upper adapter plate making sketch (AST-DWG-104).*

**What they are and what they are made from.** Two plates on the front of the rail that FieldNode's enclosure, plate clips and sun shield fix to, in place of FieldNode's back plate. Aluminium sheet 3 mm, 5052 or 6061 class.

**How to make them.**

1. Cut the lower plate 180 x 75 and the upper plate 180 x 110. Round the corners to about 2 mm and deburr.
2. Scribe a centre line on each. Mark the holes from Figure 2a: heights up from each plate's bottom edge, sideways from the centre line.
3. Lower plate: lug holes 5.5 mm, 62 each side, 15 up; sun shield holes 84 each side, 64 up, drilled 3.3 mm and tapped M4; rail bolt holes 5.5 mm on the centre line at 12 and 62 up, countersunk from the front.
4. Upper plate: sun shield holes 84 each side, 10 up, drilled 3.3 mm and tapped M4; lug holes 5.5 mm, 62 each side, 39 up; plate clip holes 5.5 mm, 65 each side, 65 and 95 up; rail bolt holes 5.5 mm on the centre line at 15 and 85 up, countersunk from the front.
5. Drill the sun shield holes on every node. They cost nothing and let the shield go on later at a hot site.
6. Cut two lightening windows in each plate, one each side of the centre line, from 26 to 50 mm out with 5 mm corner radii: in the lower plate 8 to 67 up (24 x 59), in the upper plate 8 to 102 up (24 x 94). Drill a 10 mm hole in each corner, saw or nibble between them and file the edges smooth. The windows lie behind the enclosure and keep at least 5 mm of metal round every hole and clear of the rail. They save about 60 g.

**How they fit the parts next to them.**

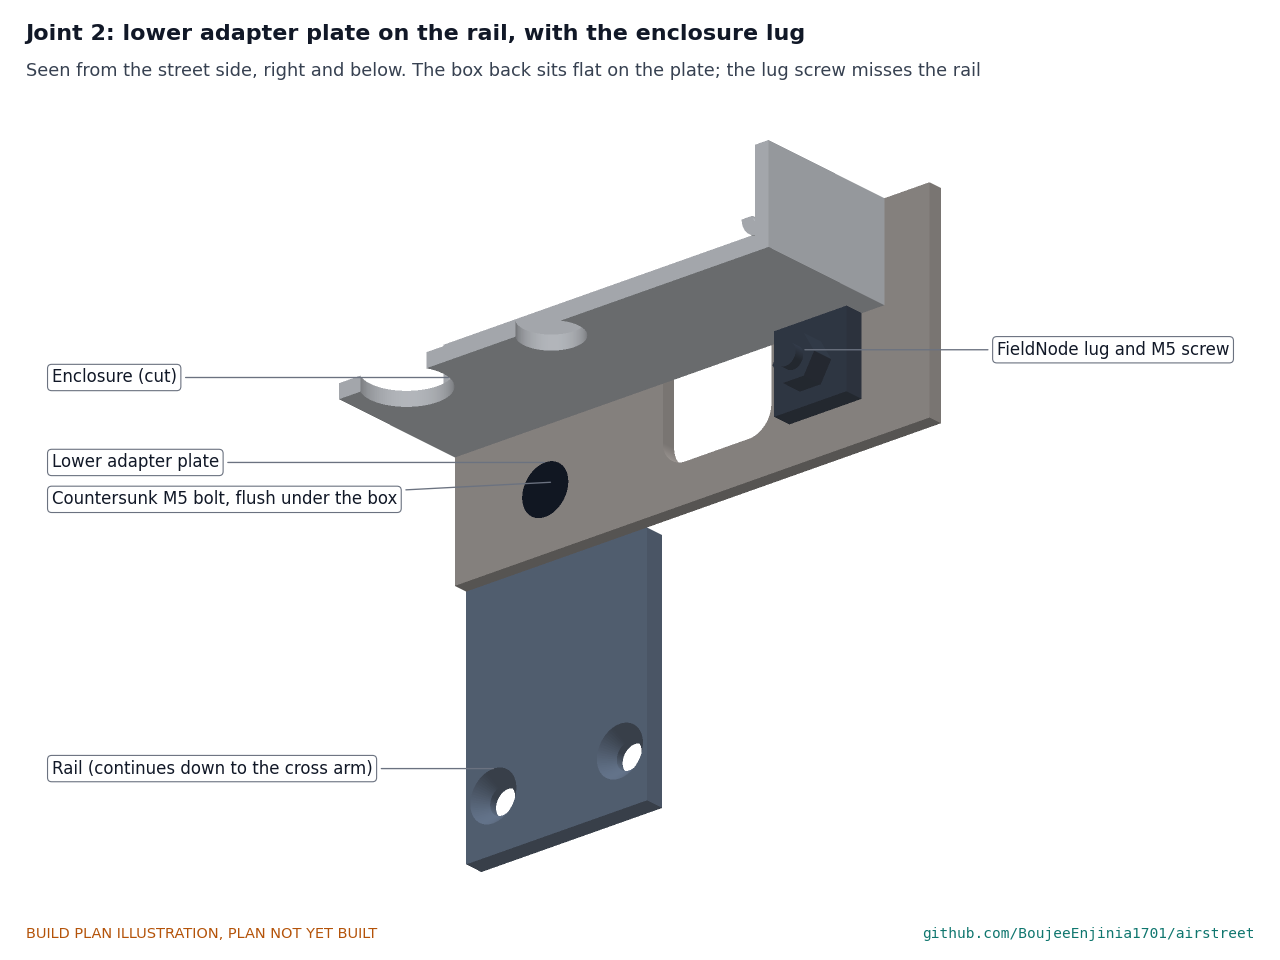
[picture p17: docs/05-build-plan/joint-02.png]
Figure 6. Joint 2: lower adapter plate, rail and enclosure lug


*Figure 6. The lower plate on the rail, with the enclosure's lower right lug on it. The countersunk bolt sits flush under the enclosure; the lug screw misses the rail.*

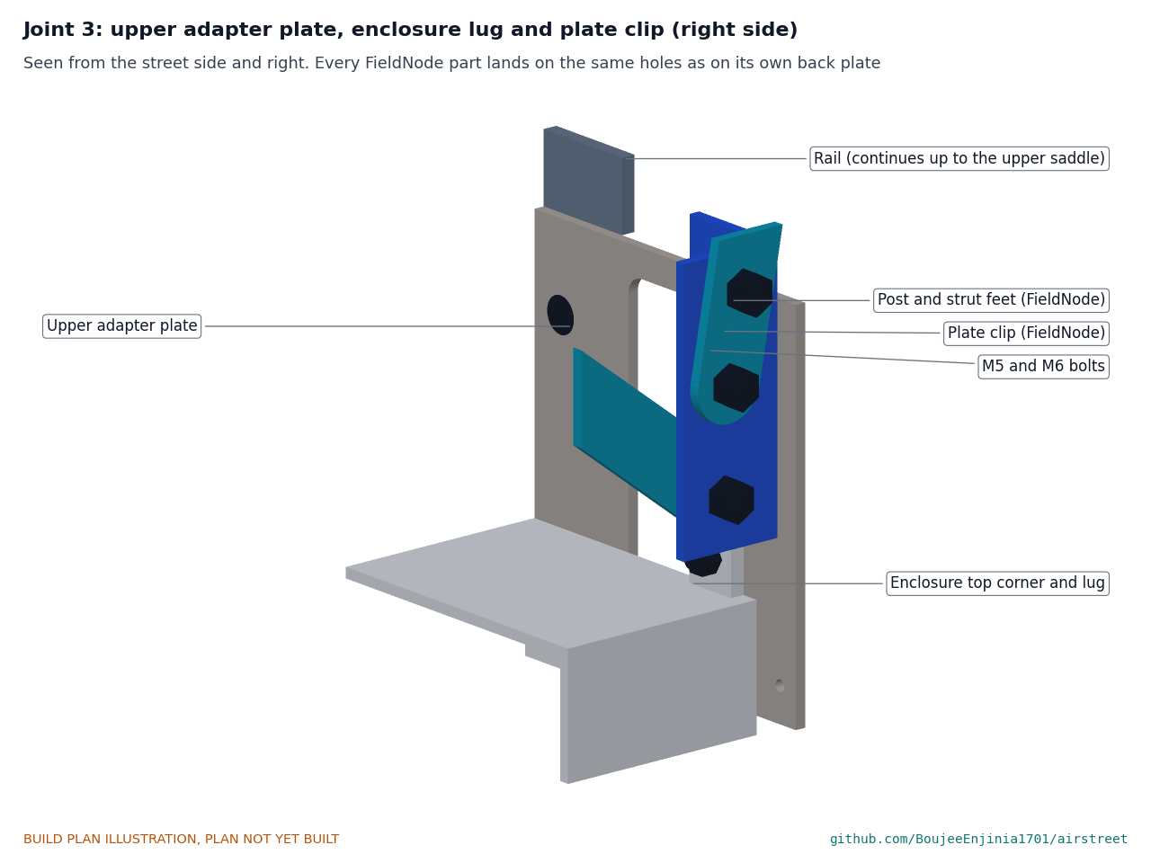
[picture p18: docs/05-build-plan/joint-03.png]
Figure 7. Joint 3: upper adapter plate, enclosure lug and plate clip


*Figure 7. The upper plate carries the enclosure's upper lugs and the bracket's plate clips on the same holes as FieldNode's own back plate.*

Each plate's back face sits flat on the rail's front face, centred, held by two M5 x 16 countersunk bolts from the front with nyloc nuts behind the rail. The lower plate's bottom edge is 24 below the enclosure's bottom; the upper plate's top edge is 280 above it, which is where FieldNode's back plate ends, so FieldNode's posts pass it with the same clearance. The enclosure's back sits flat on both plates and stands 3 mm clear of the rail between them.

**Check before moving on.** Offer the enclosure with its lugs fitted up to both plates on the rail: all four lug holes and both pairs of clip holes line up.

### 3.4 Cross arm

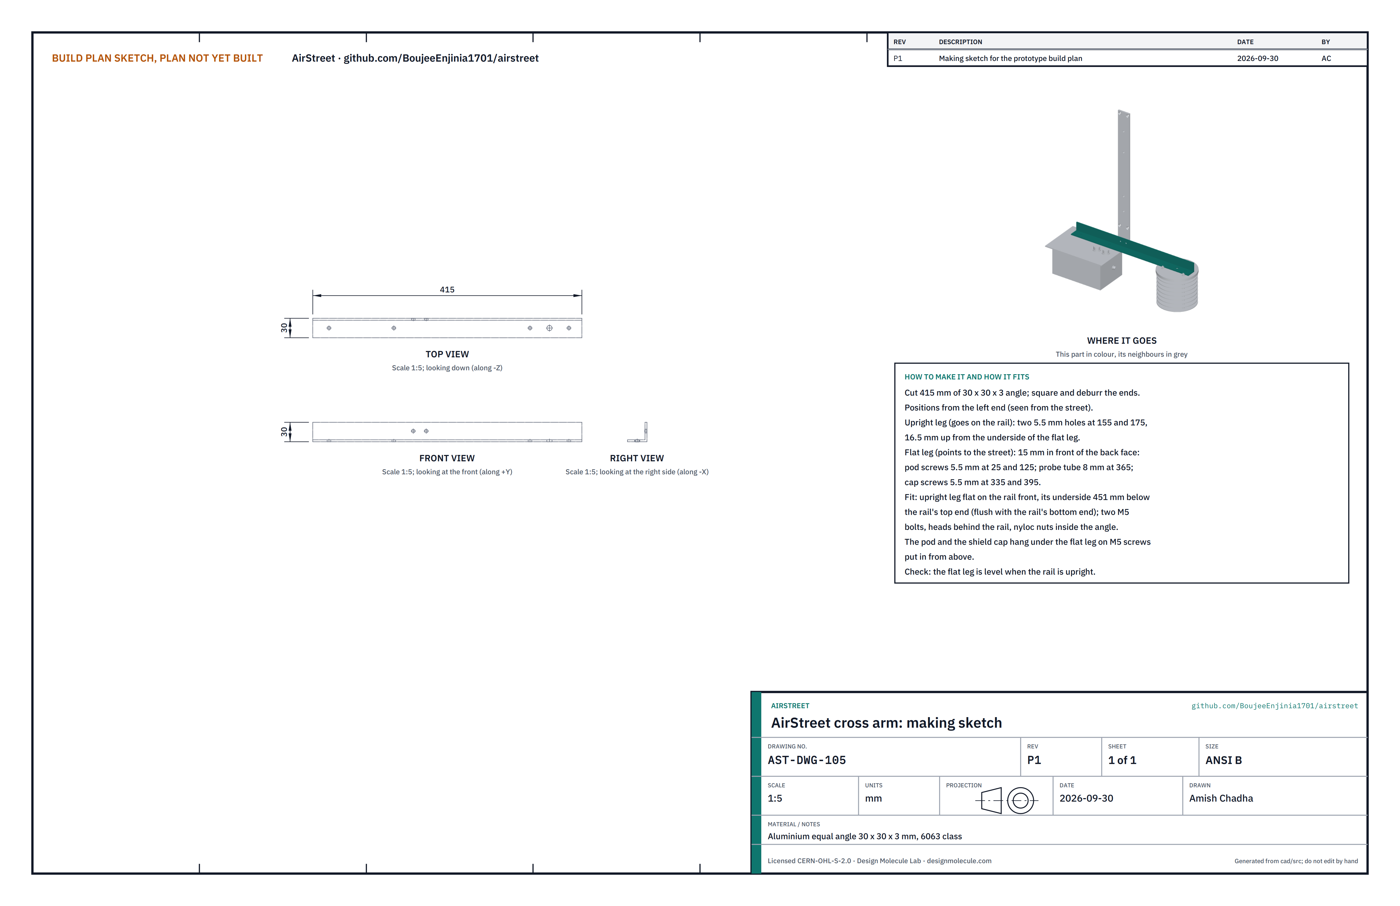
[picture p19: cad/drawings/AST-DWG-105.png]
Figure 8. Making sketch of the cross arm


*Figure 8. Cross arm making sketch (AST-DWG-105).*

**What it is and what it is made from.** A length of angle across the bottom of the rail that the pod hangs under on the left and the radiation shield on the right. Aluminium equal angle 30 x 30 x 3 mm, 6063 class.

**How to make it.**

1. Cut 415 mm and square and deburr the ends. Measure every hole from the left end.
2. Upright leg (the one that goes on the rail): two 5.5 mm holes at 155 and 175, 16.5 up from the underside of the flat leg.
3. Flat leg (the one that points to the street), all on a line 15 mm in front of the angle's back face: pod screw holes 5.5 mm at 25 and 125; cap screw holes 5.5 mm at 335 and 395; a probe tube hole 8 mm at 365. Fit a rubber grommet in the 8 mm hole.

**How it fits the parts next to it.**

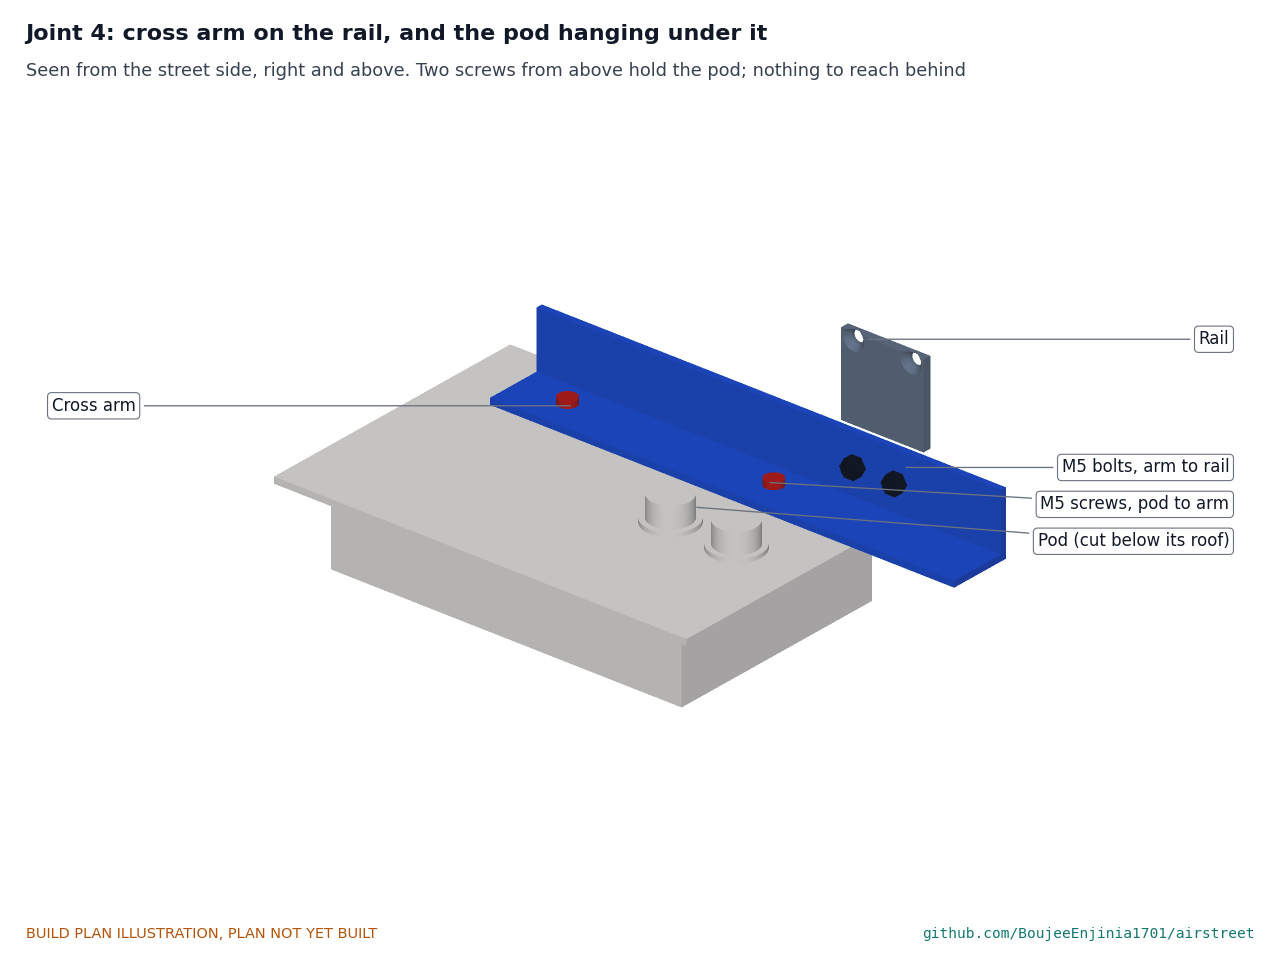
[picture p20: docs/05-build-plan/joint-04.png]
Figure 9. Joint 4: cross arm on the rail, with the pod hanging under it


*Figure 9. The upright leg bolts flat to the rail's front; the pod's roof sits flat under the flat leg on two screws put in from above.*

The upright leg sits flat on the front of the rail, its underside flush with the rail's bottom end, held by two M5 x 12 button-head screws from behind the rail with nyloc nuts inside the angle. The flat leg points to the street. The pod's drip lid and the shield cap sit flat against its underside.

**Check before moving on.** With the rail upright, the flat leg is level.

### 3.5 FieldNode core

**What it is.** The FieldNode enclosure with its cell, power modules, controller, ports, glands, vent and antenna; its four lugs; its panel bracket (two plate clips, two posts, two struts and four panel clips); its 6 W panel; and, at hot sites only, its sun shield. Build them to FieldNode's own build plan (FND-BLD-001), sections 3.3 to 3.9 and steps 2, 4, 5, 6 and 9, with these differences:

- Do not make FieldNode's back plate or V-blocks and do not buy its band clamps. The adapter plates of section 3.3 take the back plate's place, on the same hole pattern.
- FieldNode's steps 3, 7, 8, 10 and 11 (enclosure, plate clips, posts and struts, panel and sun shield onto the back plate) become steps 4, 5, 6, 7 and 16 here.
- Port B must be wired so that its 5 V supply stays on all the time; port A is switched for each particle run.

**How it fits the parts next to it.** The enclosure's lugs, the plate clips and the sun shield's flanges fix to the adapter plates exactly as they would to FieldNode's back plate:

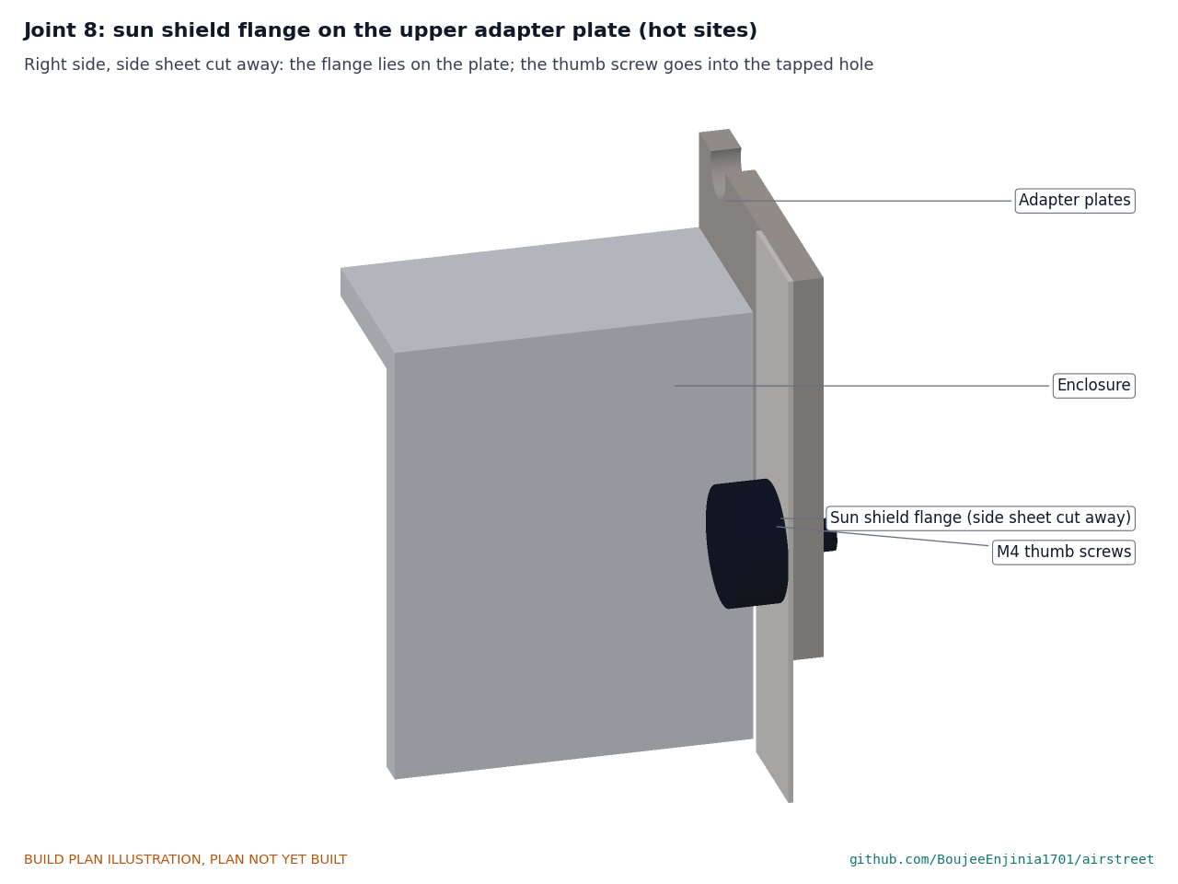
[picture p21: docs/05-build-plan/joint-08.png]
Figure 10. Joint 8: FieldNode's sun shield on the adapter plates


*Figure 10. At a hot site, each folded flange of the shield lies on both adapter plates and an M4 thumb screw goes into each tapped hole.*

**Check before moving on.** FieldNode's own checks in its build plan have passed, and the enclosure is closed with its fuse out.

### 3.6 Pod shell

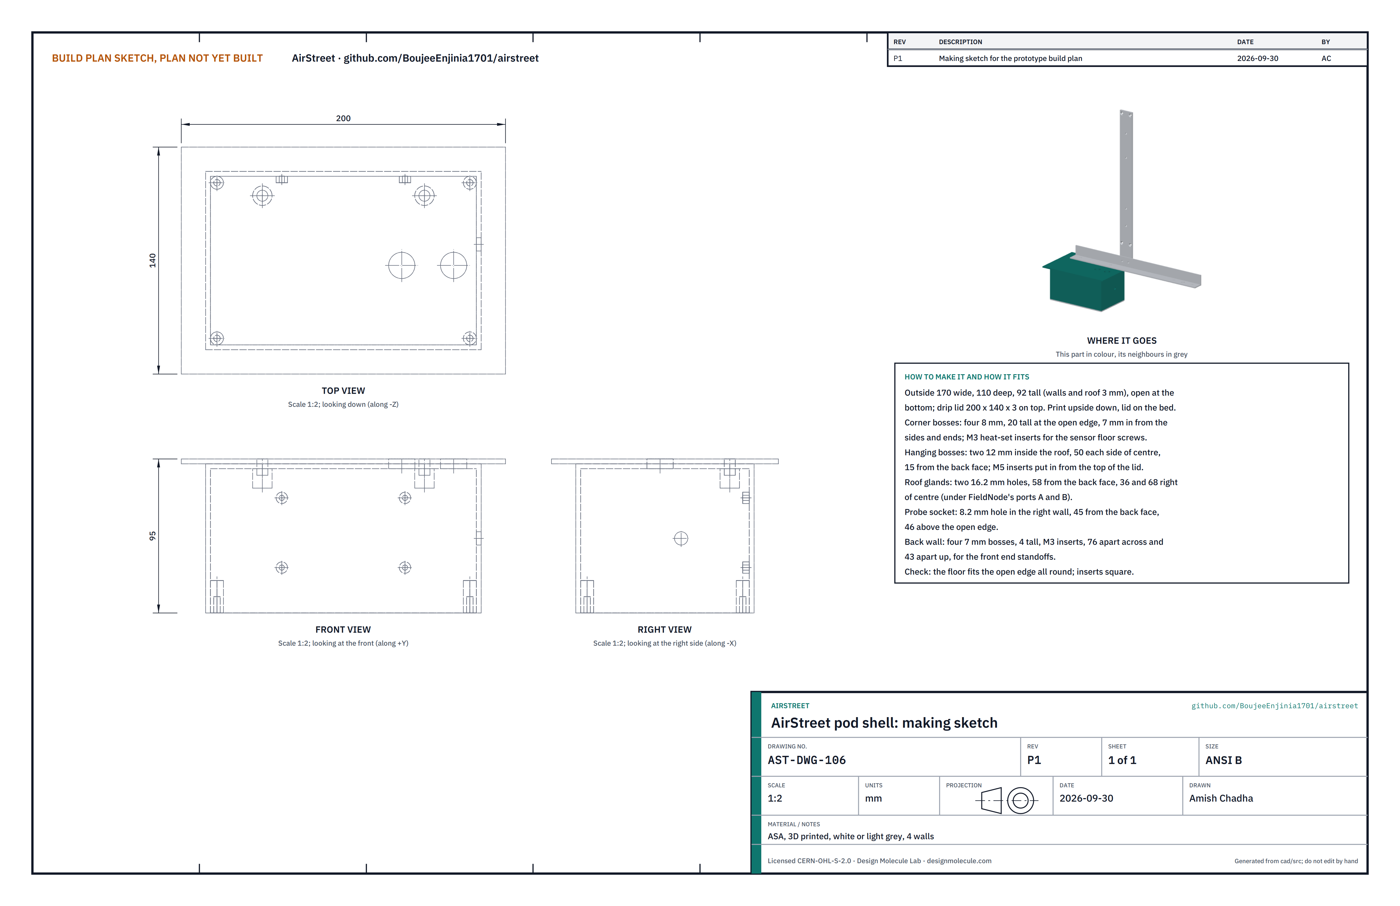
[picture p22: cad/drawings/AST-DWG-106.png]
Figure 11. Making sketch of the pod shell


*Figure 11. Pod shell making sketch (AST-DWG-106).*

**What it is and what it is made from.** The walls, roof and drip lid of the sensor pod in one printed piece, open at the bottom. White or light grey ASA, four walls.

**How to make it.**

1. Print it upside down, the drip lid on the bed: outside 170 wide, 110 deep and 92 tall with 3 mm walls and roof, and a drip lid 200 x 140 x 3 that overhangs by 15 all round. The printer bed must take 200 x 140.
2. Corner bosses: four, 8 mm across and 20 tall, inside the corners at the open edge, 7 in from the sides and ends. Press in M3 heat-set inserts for the floor screws.
3. Hanging bosses: two, 12 mm across, inside the roof, 50 each side of centre and 15 from the back face. Press M5 heat-set inserts in from the top of the drip lid.
4. Back wall: four bosses 7 mm across and 4 tall, 76 apart across and 43 apart up, with M3 heat-set inserts, for the front end's standoffs.
5. Roof gland holes: two 16.2 mm holes, 58 from the back face, 36 and 68 right of the pod's centre, so each sits under one of FieldNode's ports.
6. Probe socket hole: one 8.2 mm hole in the right wall, 45 from the back face and 46 above the open edge.

**How it fits the parts next to it.** Its back face rests against the rail's front; its drip lid sits flat under the cross arm (Figure 9). The sensor floor closes its open bottom (Figure 13).

**Check before moving on.** The sensor floor sits on the open edge all round with no gap, and every insert is square.

### 3.7 Sensor floor and mesh

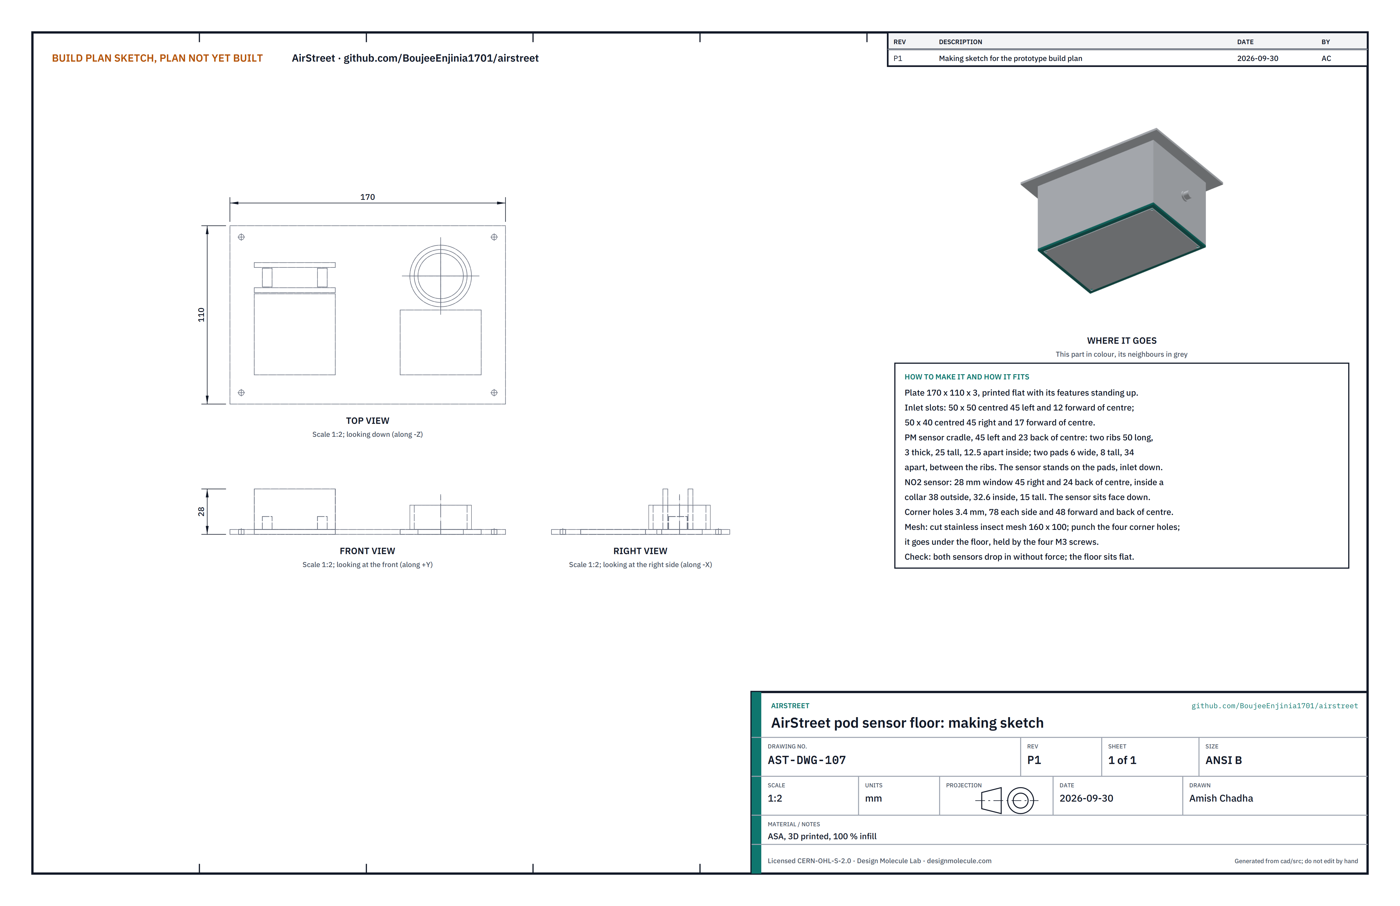
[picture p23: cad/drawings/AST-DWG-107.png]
Figure 12. Making sketch of the sensor floor


*Figure 12. Sensor floor making sketch (AST-DWG-107).*

**What it is and what it is made from.** The pod's floor, which carries both sensors and closes the pod from below behind insect mesh. ASA, printed flat at 100 % infill; stainless insect mesh.

**How to make it.**

1. Print the plate 170 x 110 x 3 with its features standing up from it.
2. Inlet slots: one 50 x 50, centred 45 left and 12 forward of centre; one 50 x 40, centred 45 right and 17 forward of centre.
3. Particle sensor cradle, centred 45 left and 23 back of centre: two ribs 50 long, 3 thick and 25 tall, 12.5 apart inside; between them two pads 6 wide and 8 tall, 34 apart. The sensor stands on edge on the pads with its inlet and outlet face down, 8 mm above the floor and beside the slot.
4. NO2 sensor window, 28 mm, 45 right and 24 back of centre, inside a collar 38 outside, 32.6 inside and 15 tall. The sensor sits face down in the collar on the rim of the window.
5. Corner holes: four 3.4 mm, 78 each side and 48 forward and back of centre.
6. Mesh: cut stainless insect mesh 160 x 100 and punch the four corner holes to match.

**How it fits the parts next to it.**

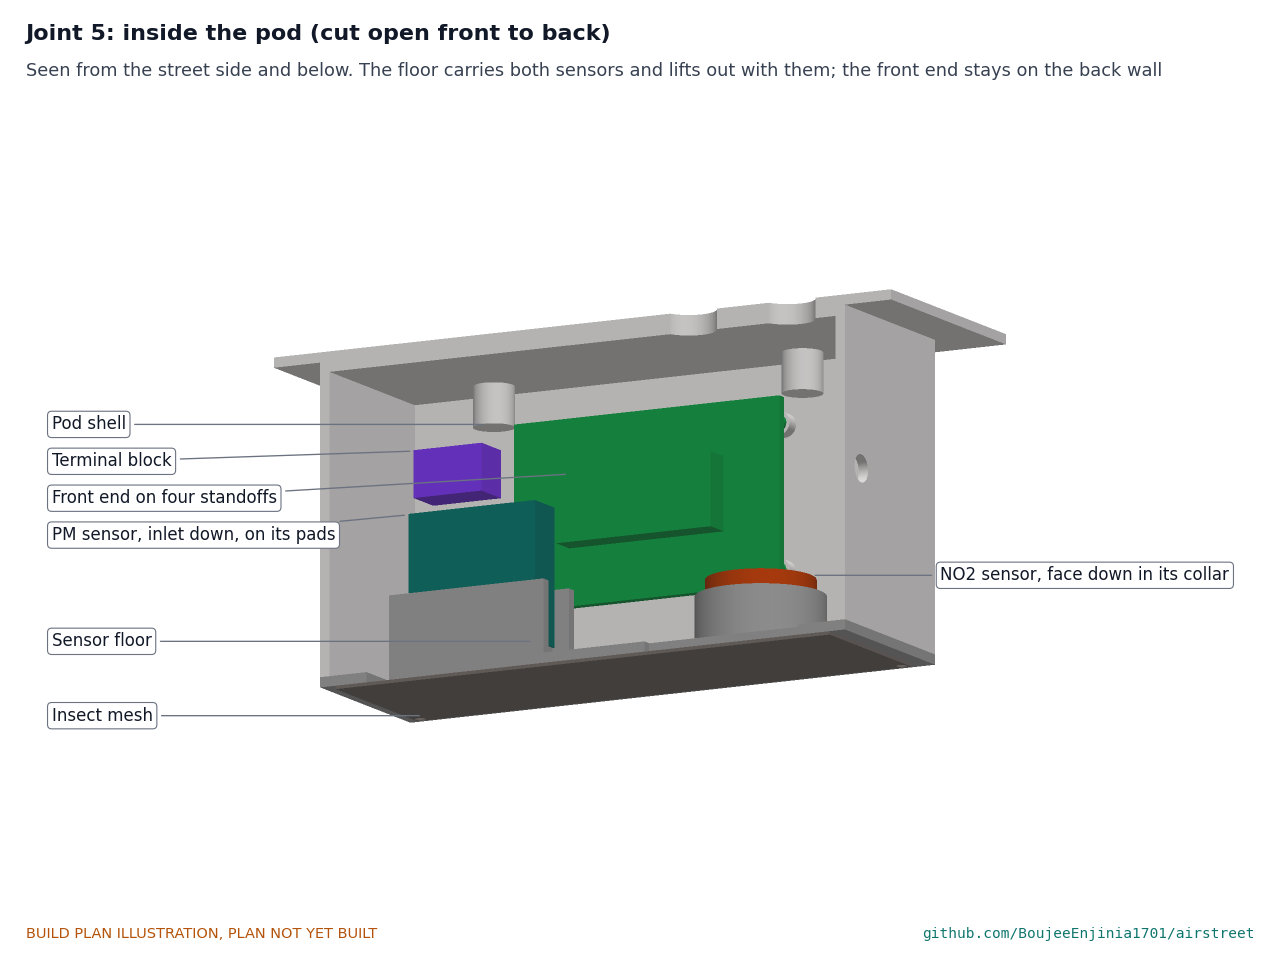
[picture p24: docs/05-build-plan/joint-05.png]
Figure 13. Joint 5: inside the pod


*Figure 13. The pod cut open from front to back. The floor carries both sensors; the front end stays on the back wall.*

The floor sits on the shell's open edge and the corner bosses; the mesh lies under it; four M3 x 8 screws with washers go up through mesh and floor into the corner inserts. The particle sensor clears the front end by 1.5 mm and the NO2 sensor by 4.5 mm.

**Check before moving on.** Both sensors drop into the floor without force and sit square; the floor lies flat.

### 3.8 Shield plates and spacers (make 8 plates and 24 spacers)

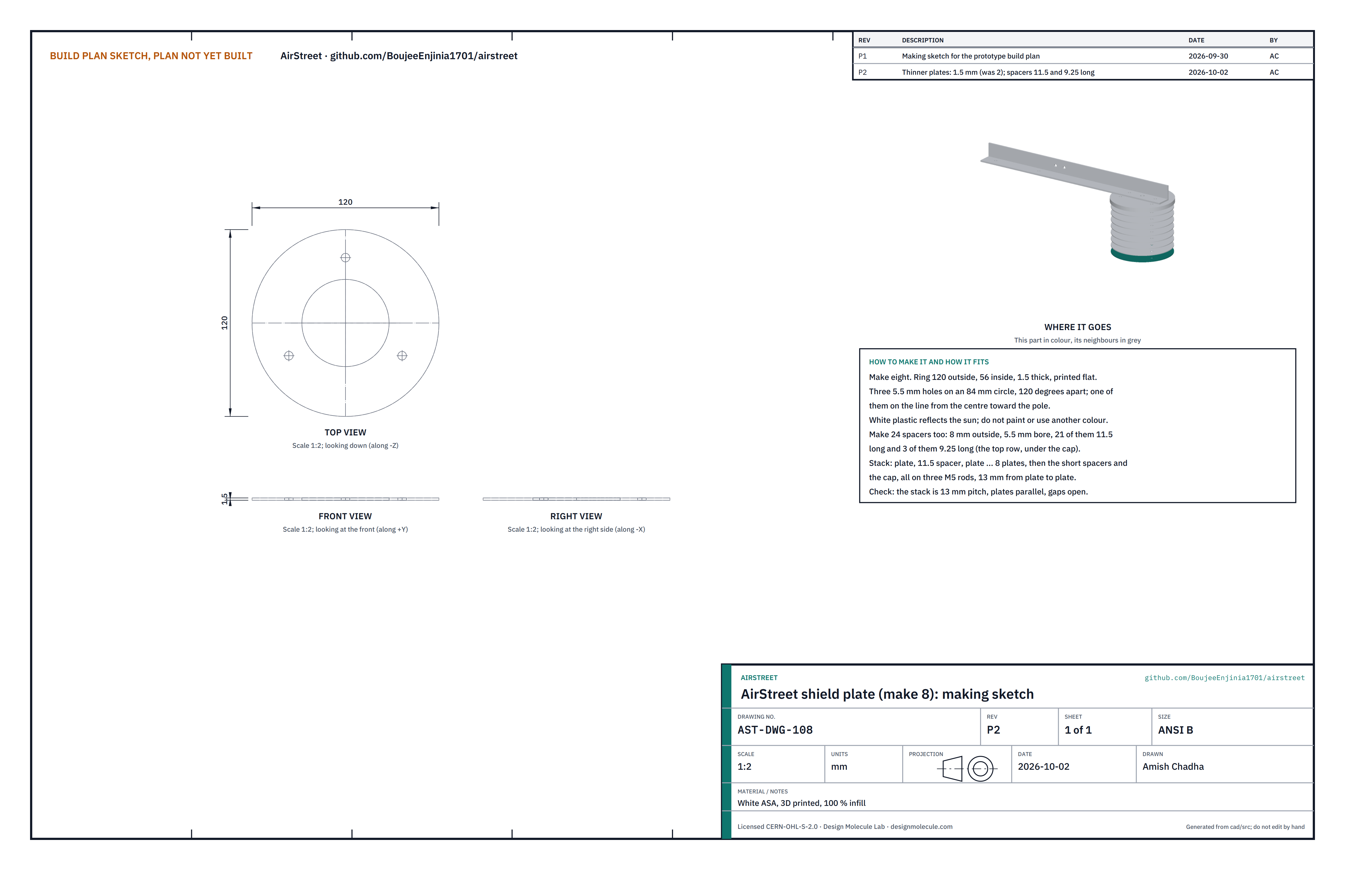
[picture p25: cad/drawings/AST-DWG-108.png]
Figure 14. Making sketch of the shield plate


*Figure 14. Shield plate making sketch (AST-DWG-108).*

**What they are and what they are made from.** Eight white rings stacked 13 mm apart, which shade the probe while letting air through. White ASA, printed flat at 100 % infill. Do not paint them or print them in another colour: the white reflects the sun.

**How to make them.**

1. Print eight rings, 120 outside, 56 inside, 1.5 thick.
2. Each has three 5.5 mm holes on an 84 mm circle, 120° apart; one of them points to the pole when fitted.
3. Print 24 spacers 8 mm outside with a 5.5 mm bore: 21 of them 11.5 long and 3 of them 9.25 long.

**How they fit the parts next to them.** See section 3.9 and Figure 16: plate, 11.5 mm spacer, plate and so on, eight plates, then the three 9.25 mm spacers and the cap, all on three M5 rods.

**Check before moving on.** Every plate is flat; the spacers slide on an M5 rod freely.

### 3.9 Shield cap and probe tube

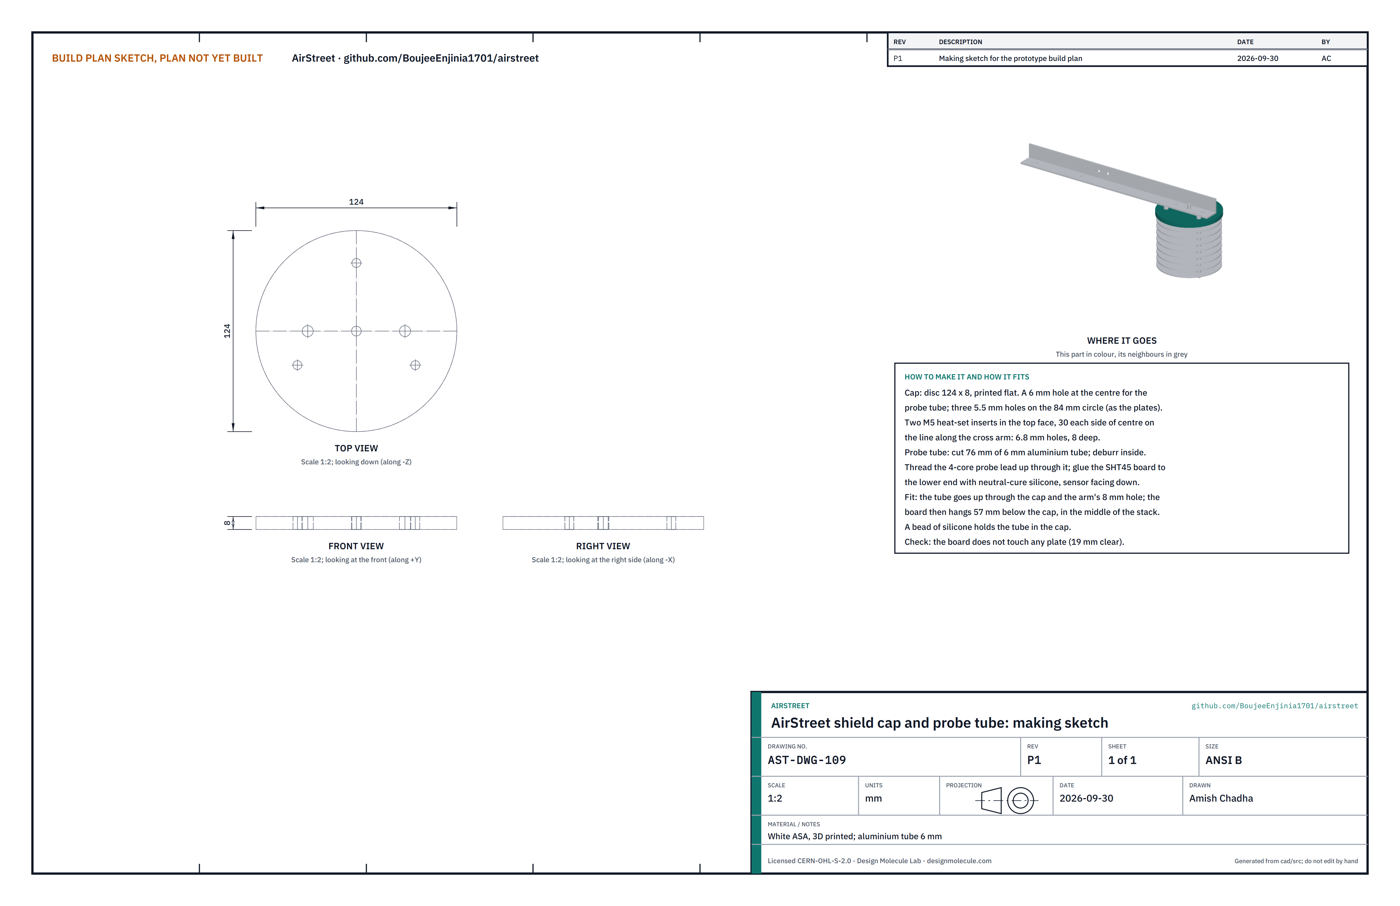
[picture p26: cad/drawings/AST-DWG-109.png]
Figure 15. Making sketch of the shield cap and probe tube


*Figure 15. Shield cap and probe tube making sketch (AST-DWG-109).*

**What they are and what they are made from.** The top of the shield, which screws up under the cross arm, and the tube the temperature and humidity probe hangs on. White ASA, printed flat; aluminium tube 6 mm outside.

**How to make them.**

1. Print the cap: a disc 124 across and 8 thick, with a 6 mm hole at its centre and three 5.5 mm holes on the 84 mm circle, matching the plates.
2. Two 6.8 mm holes, 8 deep, in the top face, 30 each side of centre on a line through the centre; press in M5 heat-set inserts.
3. Cut 76 mm of 6 mm aluminium tube and deburr it inside. Cut three M5 stainless rods 125 long.
4. Thread the 4-core probe lead up through the tube. Solder it to the probe board, then glue the board to the lower end of the tube with neutral-cure silicone, sensor facing down.
5. Fit the M8 plug to the other end of the lead, wired to match the socket of step 9 in section 3.10.

**How they fit the parts next to them.**

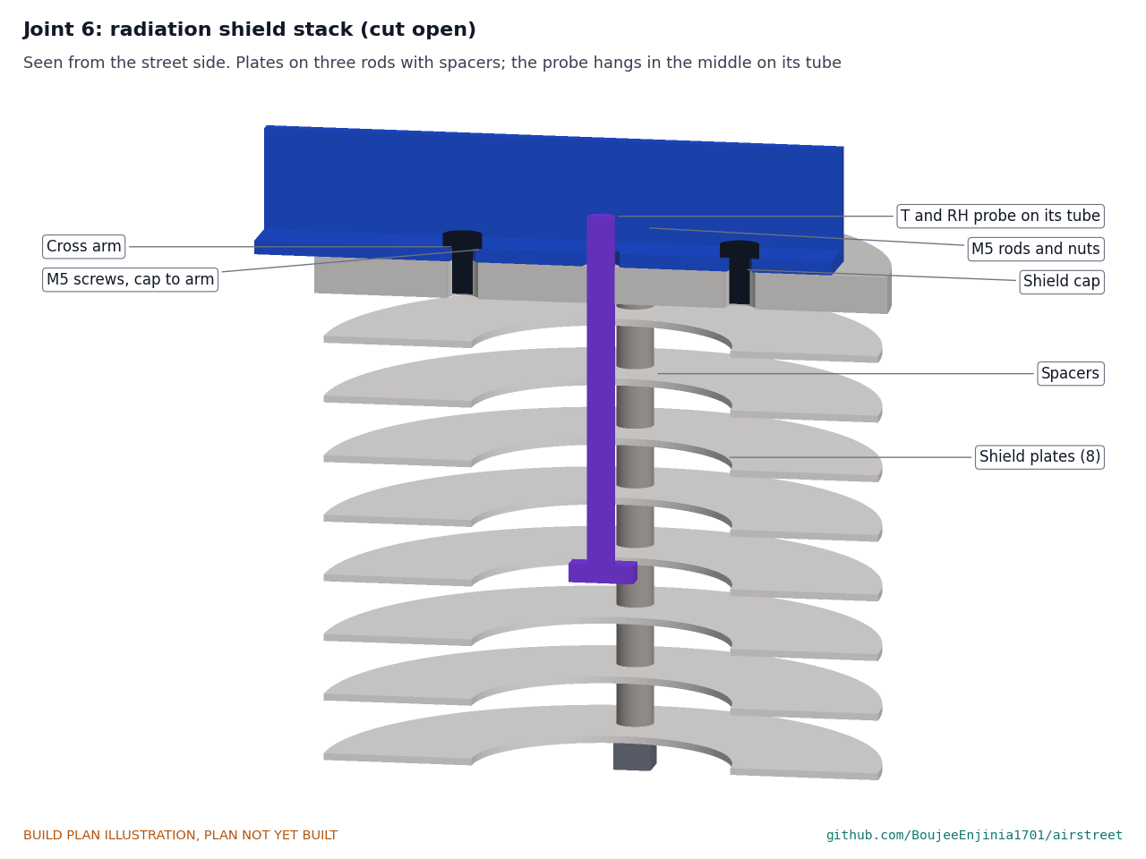
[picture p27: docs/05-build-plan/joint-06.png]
Figure 16. Joint 6: the radiation shield stack


*Figure 16. The stack cut open: plates on three rods with spacers between them, the cap on top, and the probe hanging in the middle on its tube.*

The rods go up through the plates, spacers and cap, with an acorn nut under the bottom plate and a nyloc nut on top of the cap. The cap screws up under the cross arm with two M5 x 10 pan-head screws from above. The tube goes up through the cap's centre hole and the arm's grommet; a bead of silicone holds it in the cap. The probe board then hangs 57 mm below the cap, 19 mm clear of every plate.

**Check before moving on.** Plates parallel and 13 mm apart; the probe board does not touch any plate.

### 3.10 Pod wiring

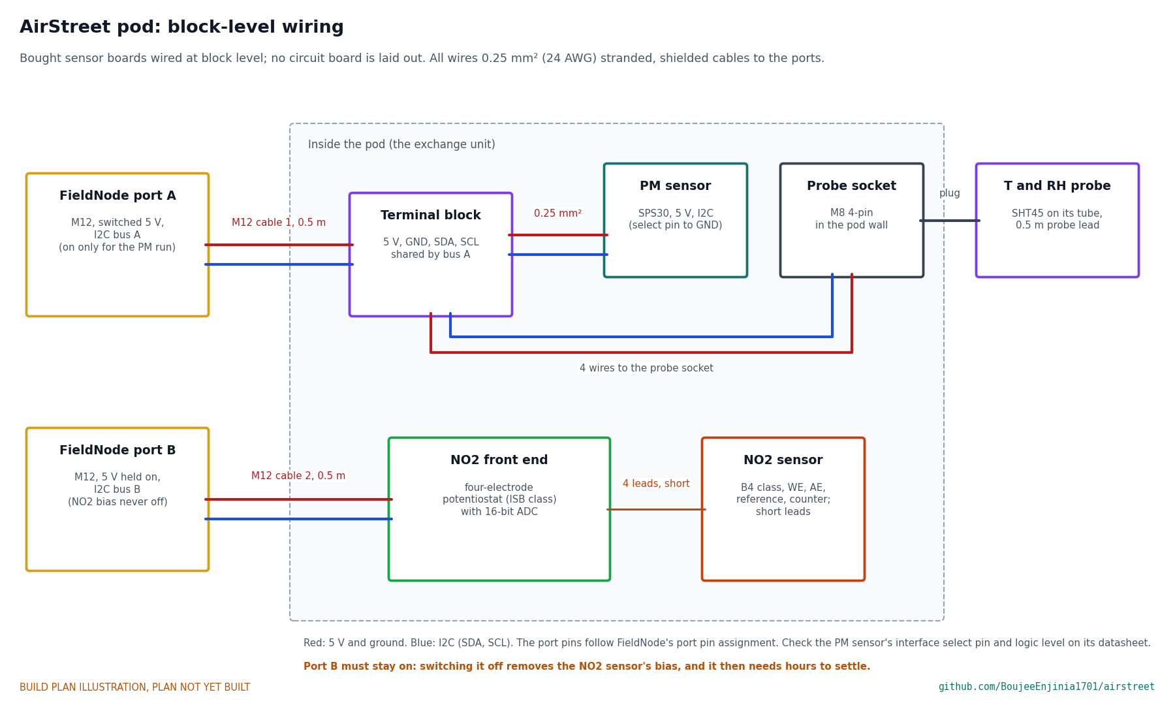
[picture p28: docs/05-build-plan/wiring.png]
Figure 17. Block-level wiring of the pod


*Figure 17. Block-level wiring of the pod. No circuit board is laid out at this stage.*

All wires inside the pod are 0.25 mm² (24 AWG) stranded copper, with a ferrule on every screw terminal.

1. Fit the front end board on four M3 x 6 standoffs into the back wall inserts, and the small terminal block on the back wall to its left.
2. Fit the two M16 glands in the roof and the M8 4-pin socket in the right wall, each with its seal outside and its nut inside.
3. Pass each M12 cable's open end down through its roof gland (port A cable through the left gland, port B cable through the right), leaving about 150 mm of slack inside, and tighten the gland on the cable jacket.
4. Port A cable to the terminal block: 5 V, ground, data and clock.
5. Terminal block to the particle sensor: 5 V, ground, data, clock, and its interface select pin to ground for the two-wire interface.
6. Terminal block to the M8 socket: 5 V, ground, data, clock.
7. Port B cable to the front end board: 5 V, ground, data and clock (its own bus, so the NO2 readings never share a bus that switches off).
8. NO2 sensor to the front end: its four electrode pins on short leads, under 100 mm, twisted in pairs, away from the cable glands.
9. Label every wire. The pins of the M12 ports follow FieldNode's port pin assignment.

Before step 8, take the shorting spring off the NO2 sensor's pins only when you are ready to plug it into the front end, and power the front end soon after: the sensor needs its bias held from then on.

**Check before moving on.** Every wire continues end to end; with nothing powered, 5 V reads open to ground on both cables.

### 3.11 Bought components

Buy to specification, not brand. Line numbers are those of the bill of materials.

- **Band clamps (line 3).** 12.7 mm (half inch) stainless worm-drive band from a roll, with two separate worm-drive housings. Each band is about 0.6 m including its tail for poles up to 200 mm; 487 mm goes round a 140 mm pole and saddle.
- **Aluminium (line 3).** Flat bar 40 x 4 mm, 451 mm; sheet 3 mm, 180 x 185 mm; equal angle 30 x 30 x 3 mm, 415 mm.
- **Particle sensor (line 5).** Sensirion SPS30 class, 41 x 41 x 12 mm, 5 V, two-wire (I2C) interface, with its interface cable.
- **NO2 sensor (line 6).** Four-electrode B4 class with an ozone filter (Alphasense NO2-B43F class), with its shorting spring.
- **NO2 front end (line 7).** Four-electrode potentiostat board for B4 sensors (Alphasense ISB class) with a 16-bit ADC on a two-wire bus; the model assumes it is 86 x 55 mm with mounting holes 76 x 43 mm apart.
- **Temperature and humidity probe (line 9).** Sensirion SHT45 on a small breakout board, two-wire bus, 3.3 to 5 V.
- **Sensor cables (line 10).** Two 0.5 m shielded cables with an M12 5-pin A-coded plug; 0.5 m of 4-core shielded probe lead with an M8 4-pin plug.
- **Pod parts (lines 4 and 11).** Stainless insect mesh; two M16 cable glands for 4 to 8 mm cable; an M8 4-pin panel socket; a small 4-way terminal block; a desiccant sachet.
- **Fixings (line 11).** Stainless: 4 x M5 x 16 countersunk screws (saddles); 4 x M5 x 16 countersunk screws with nyloc nuts (adapter plates); 2 x M5 x 12 button-head screws with nyloc nuts (cross arm); 4 x M5 x 10 pan-head screws (pod and cap); 3 x M5 x 125 rods with 3 acorn and 3 nyloc nuts; 8 x M5 and 8 x M3 brass heat-set inserts; 4 x M3 x 8 screws with washers; 4 x M3 x 6 standoffs; an 8 mm grommet; cable ties.
- **FieldNode core (lines 1 and 2).** As FieldNode's bill of materials, without its pole mounting kit.

## 4. Putting it together

In each picture the parts already fitted are grey and the parts being fitted are in colour, with an arrow showing the way they go in. Steps 1 to 14 are done on the bench with the rail lying flat or held upright in a vice; step 15 puts the node on a pole stub.

### Step 1: V-saddles onto the rail

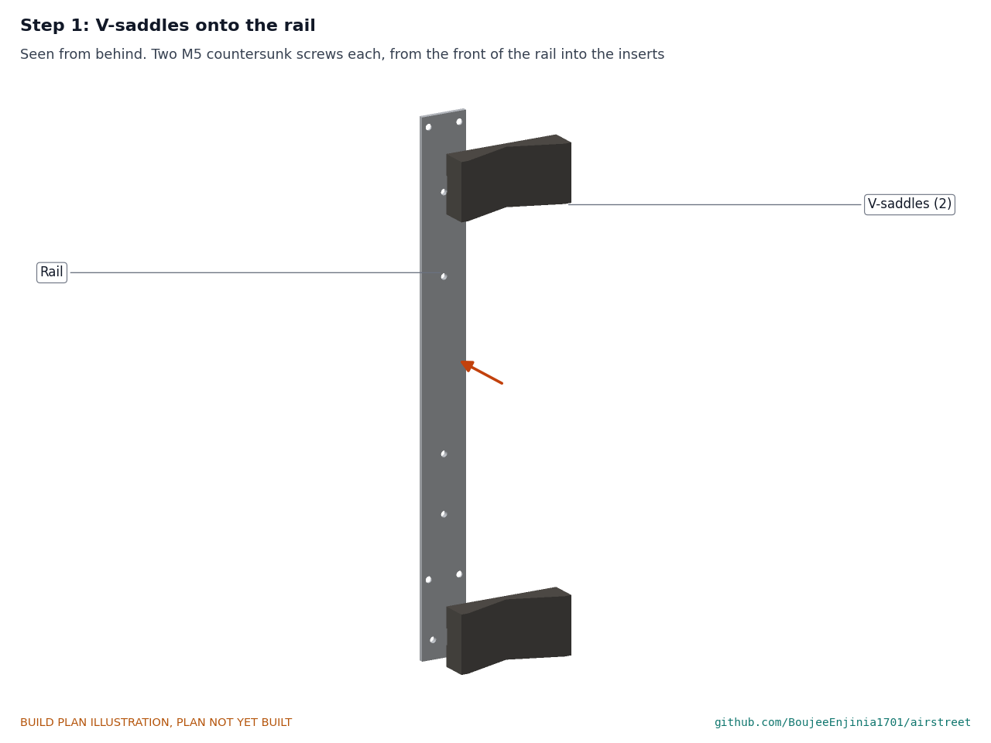
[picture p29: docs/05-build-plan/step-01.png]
Step 1


Seen from behind. Each saddle's flat back on the back of the rail, its band groove across the rail; two M5 x 16 countersunk screws from the front of the rail into its inserts, snug. Do not overtighten: the inserts are in plastic.

### Step 2: adapter plates onto the rail

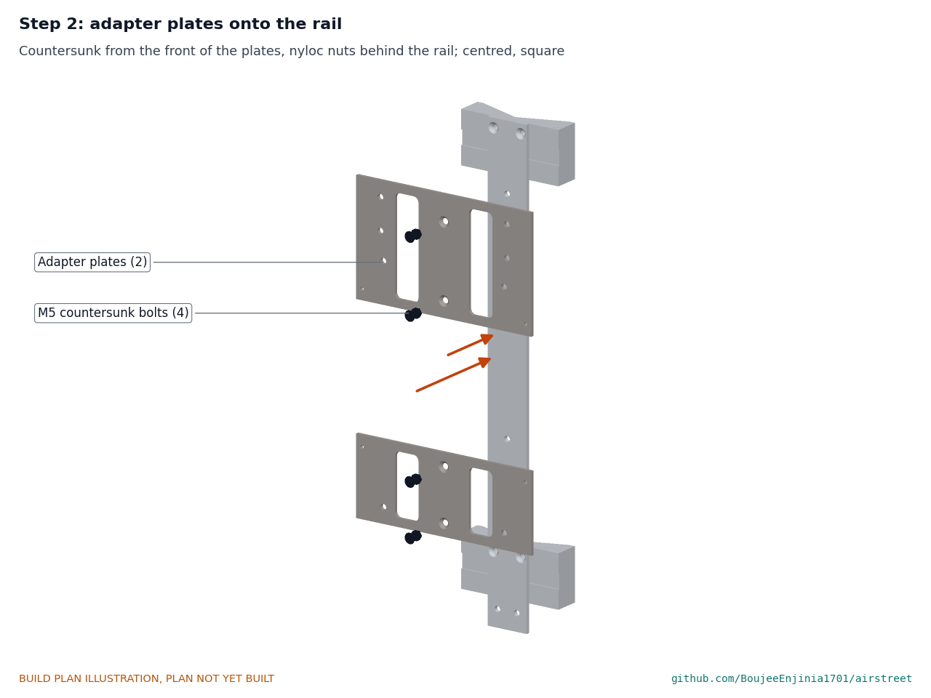
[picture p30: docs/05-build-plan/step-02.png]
Step 2


Each plate centred on the rail's front face; two M5 x 16 countersunk screws from the front of the plate, nyloc nuts behind the rail, tight. The countersunk heads must sit flush or below the plate's face, since the enclosure sits on them.

### Step 3: cross arm onto the rail

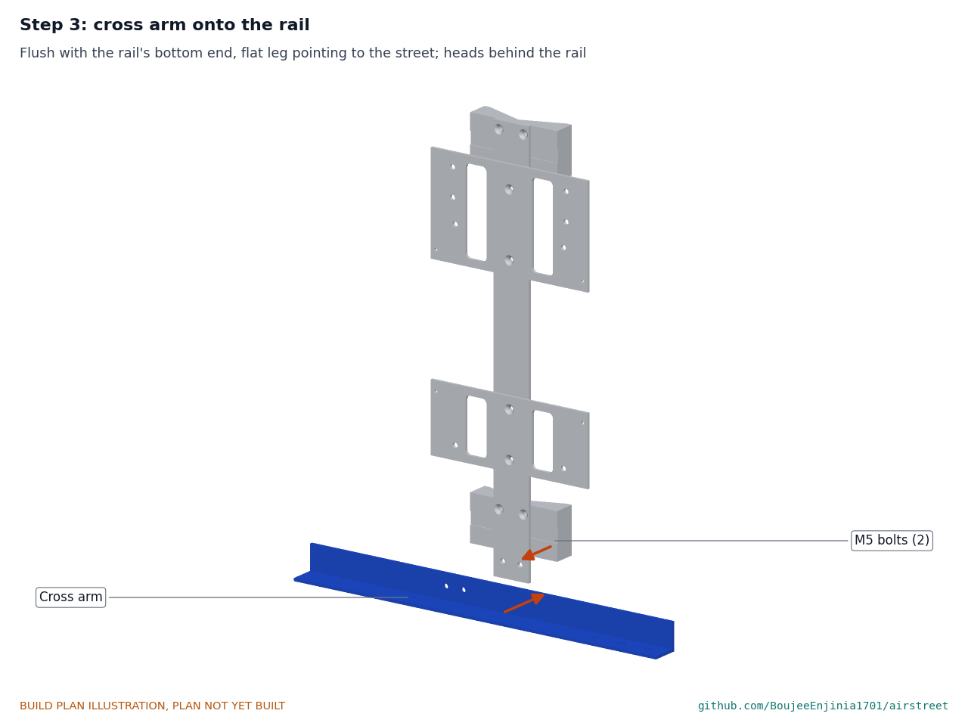
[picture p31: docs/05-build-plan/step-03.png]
Step 3


Upright leg flat on the rail's front face, its underside flush with the rail's bottom end, flat leg pointing to the street. Two M5 x 12 button-head screws from behind the rail, nyloc nuts inside the angle, tight.

### Step 4: FieldNode enclosure onto the adapter plates

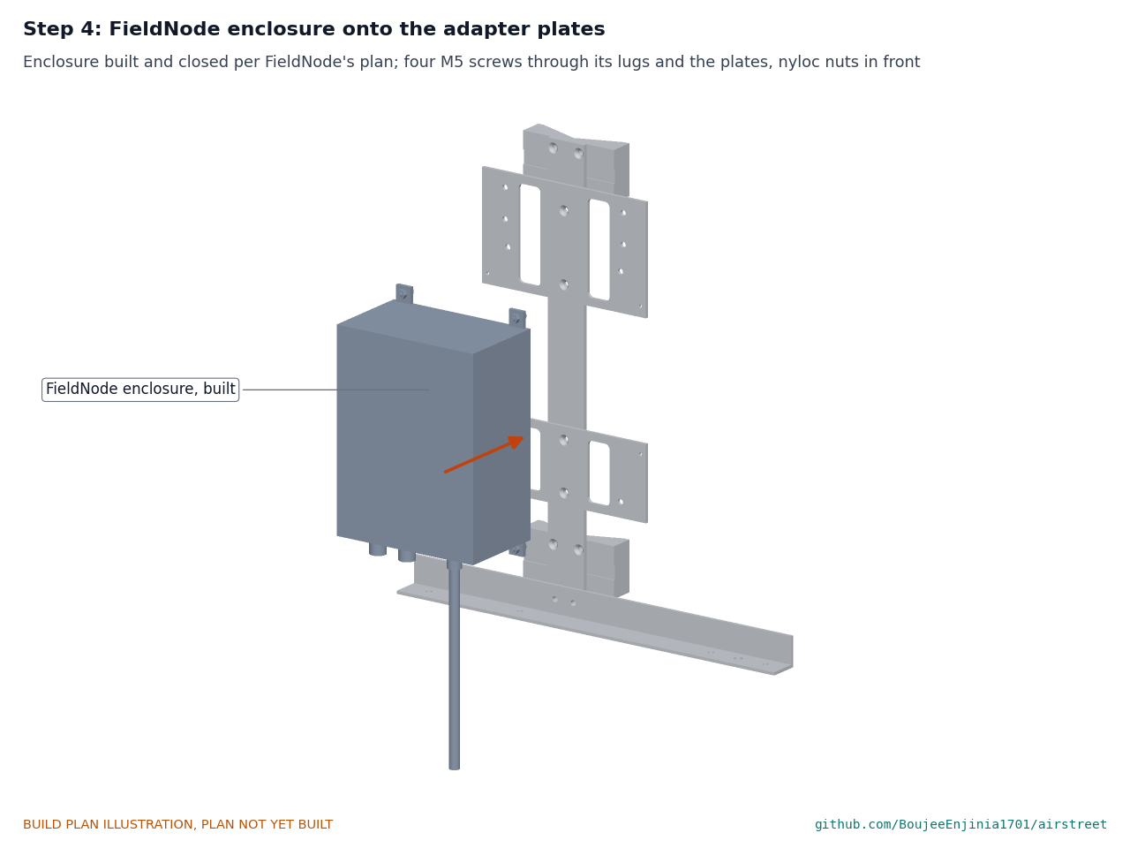
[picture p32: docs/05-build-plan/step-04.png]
Step 4


The enclosure is built, closed and checked to FieldNode's plan, with its lugs on and its fuse out. Hold it flat on both plates, centred, and fit four M5 x 12 button-head screws through the lugs from behind the plates, nyloc nuts in front, snug.

### Step 5: plate clips onto the upper adapter plate

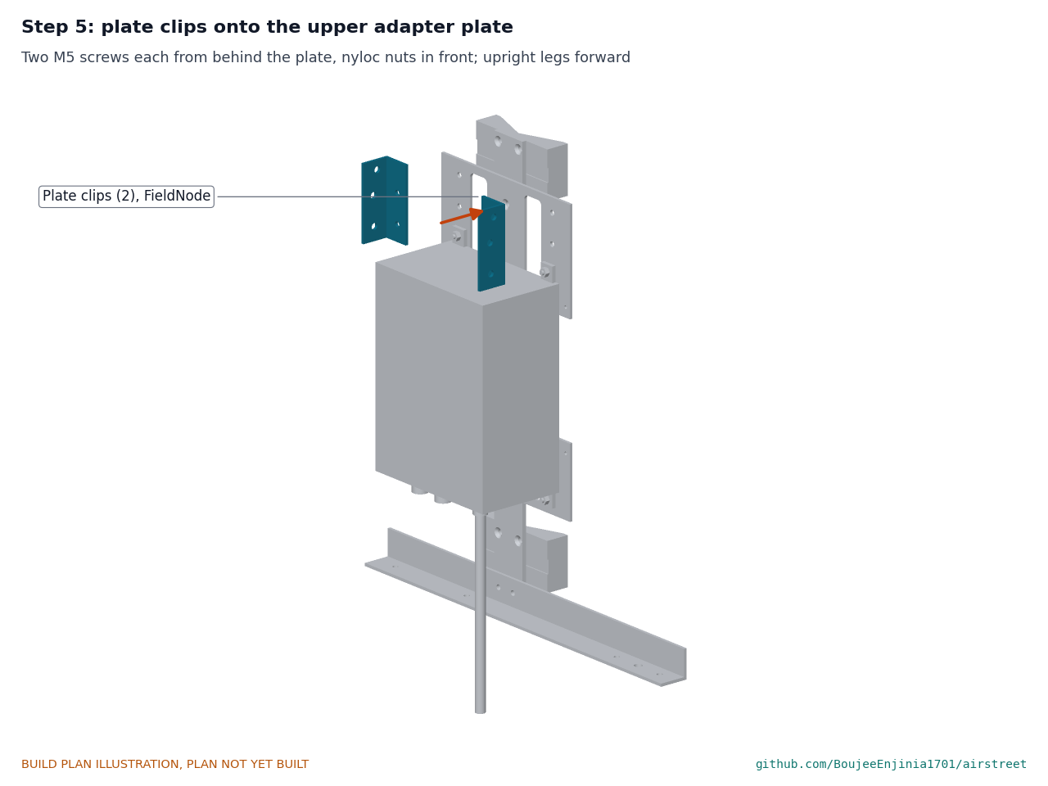
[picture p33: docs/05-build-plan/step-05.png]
Step 5


Two M5 x 12 button-head screws each from behind the plate, nyloc nuts in front, upright legs standing forward and square to the plate.

### Step 6: posts and struts onto the plate clips

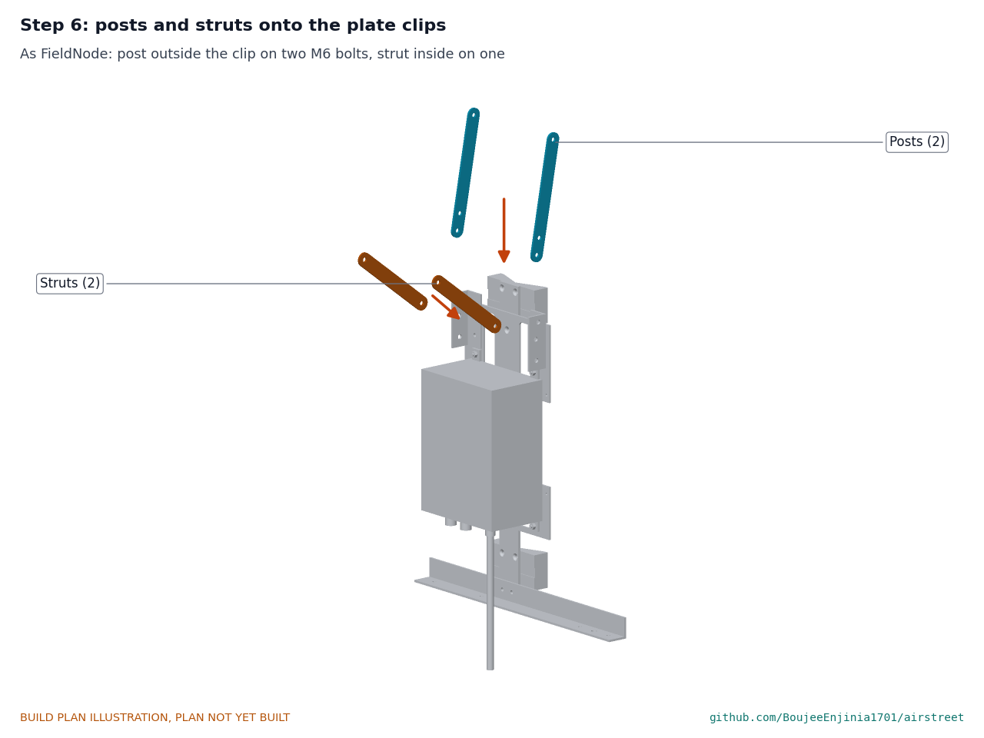
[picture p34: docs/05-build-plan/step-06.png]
Step 6


As FieldNode's plan: each post against the outside of its clip on two M6 bolts, tight; each strut against the inside on one M6 bolt, snug so it can still swing.

### Step 7: panel onto the posts and struts

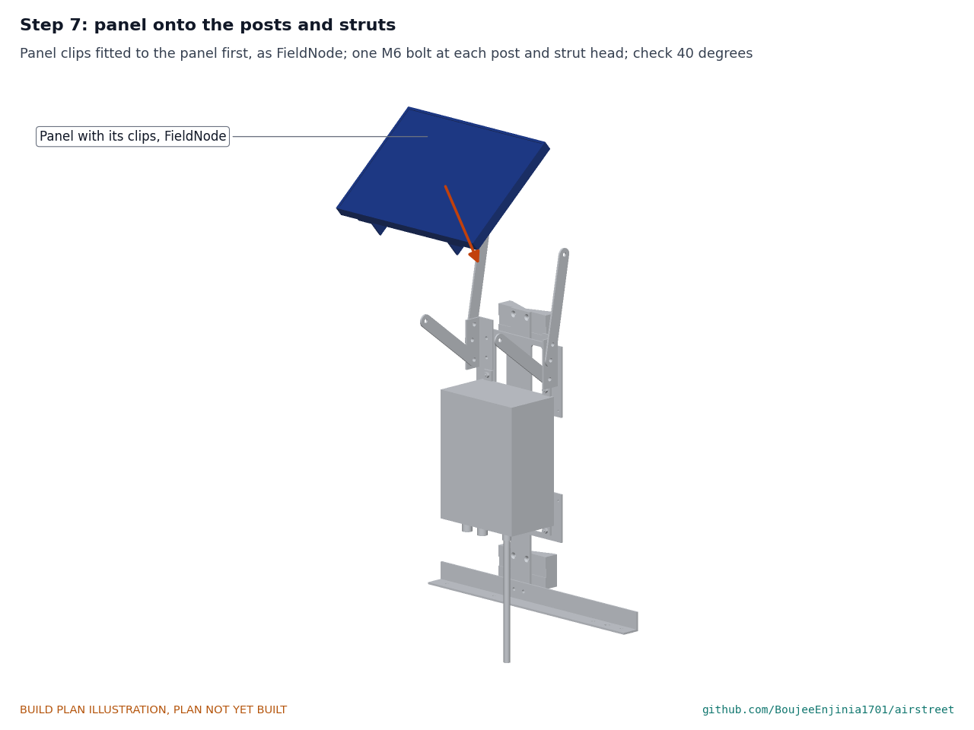
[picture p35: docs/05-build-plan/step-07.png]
Step 7


Fit the four panel clips to the panel first, as FieldNode's plan. With a helper holding the panel, fit one M6 bolt at each post head and one at each strut head; check 40° with an angle finder, then tighten every bracket bolt.

### Step 8: fit out the pod shell

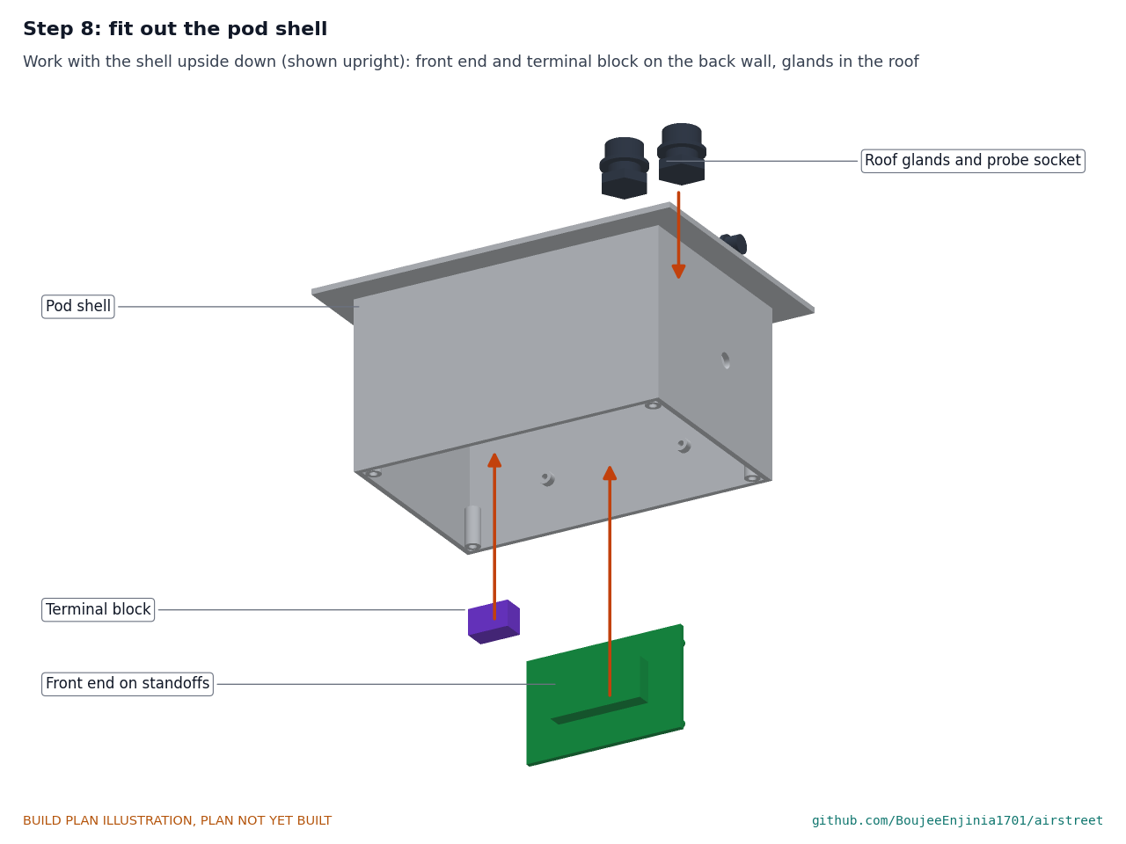
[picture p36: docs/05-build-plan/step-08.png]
Step 8


Work with the shell upside down on a soft cloth (the picture shows it upright). Fit the front end on its standoffs and the terminal block on the back wall, and the two roof glands and the probe socket, as section 3.10, steps 1 and 2.

### Step 9: sensors into the floor

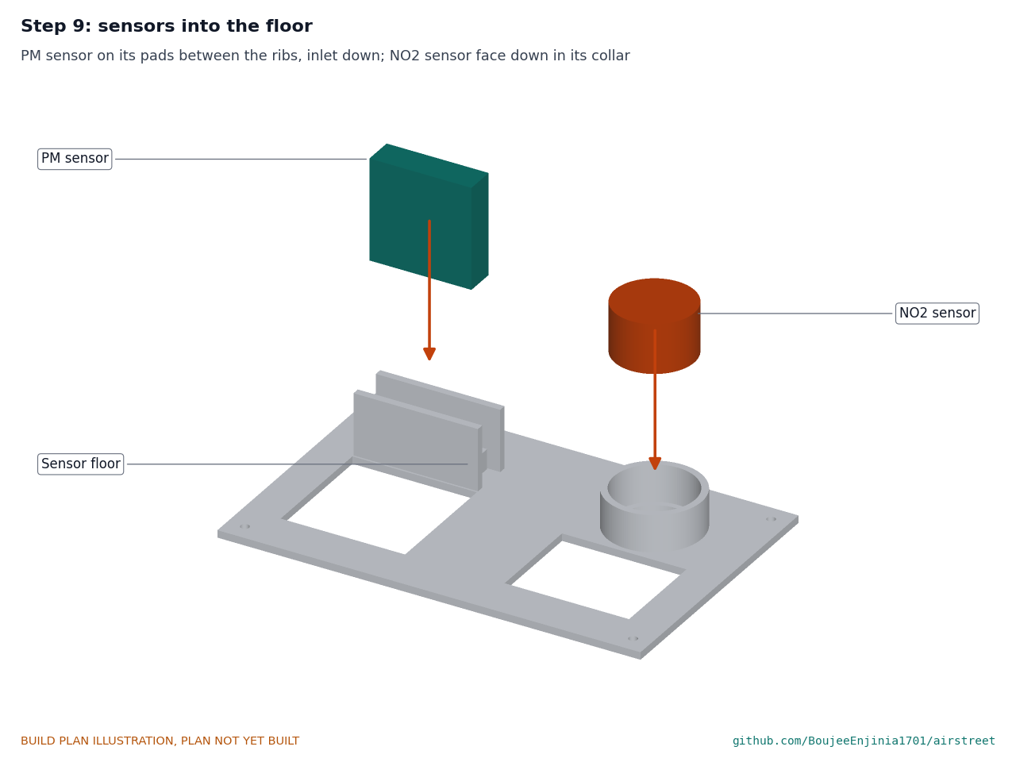
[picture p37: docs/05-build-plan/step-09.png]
Step 9


The particle sensor stands on its pads between the ribs, inlet and outlet face down; a cable tie over the ribs holds it. The NO2 sensor goes face down into its collar, shorting spring still on.

### Step 10: close the pod from below

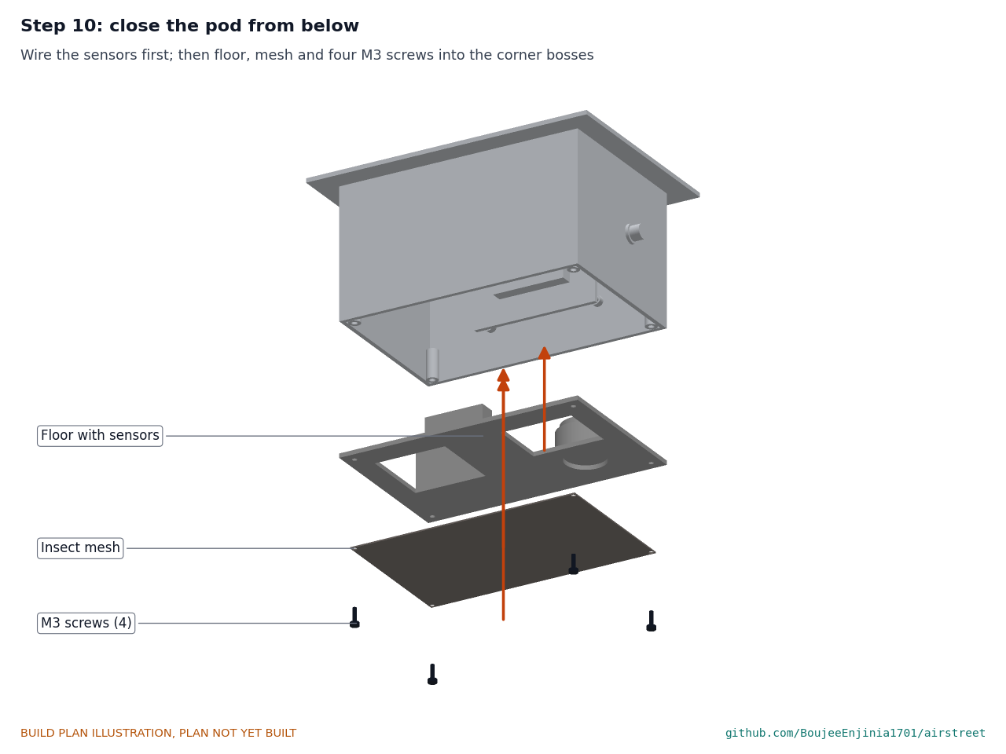
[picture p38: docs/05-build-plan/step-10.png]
Step 10


Wire the sensors to the front end and the terminal block as section 3.10, steps 4 to 8, leaving the M12 cables out for now if they are not yet through the glands. Add a fresh desiccant sachet. Lay the floor on the shell's open edge, the mesh under it, and fit four M3 x 8 screws with washers into the corner inserts. **Hold point:** no wire pinched between floor and shell; the mesh lies flat over both slots and the NO2 window.

### Step 11: pod onto the cross arm

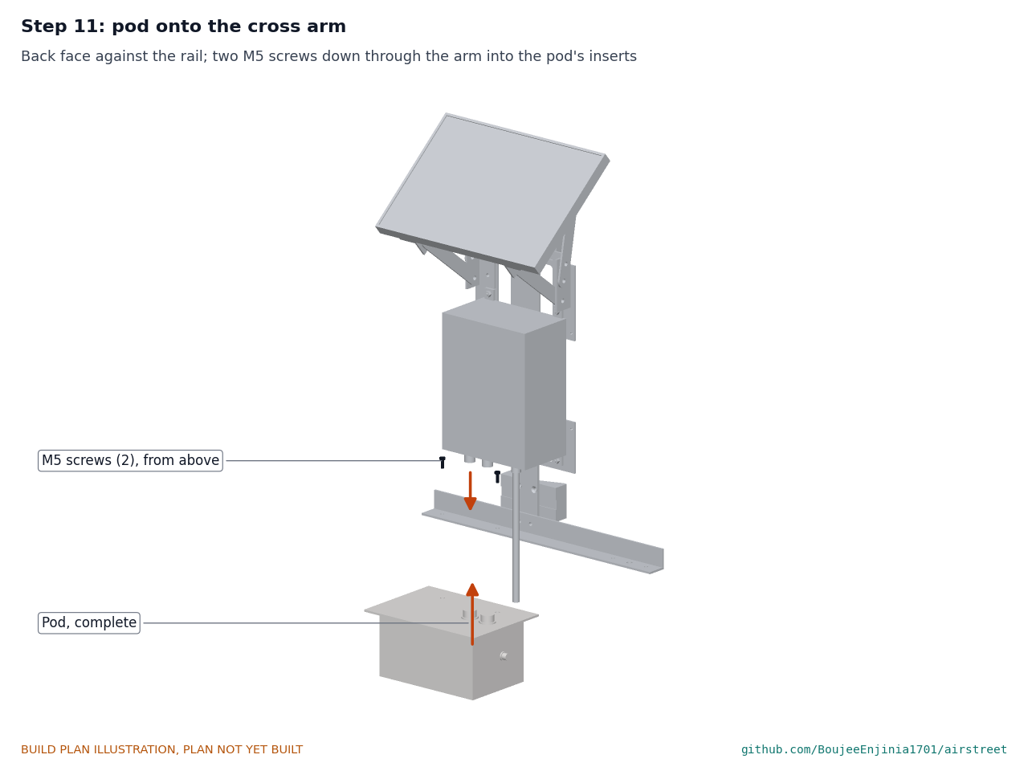
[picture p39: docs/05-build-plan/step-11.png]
Step 11


Lift the pod under the arm's left end, its back face against the rail, and fit two M5 x 10 pan-head screws down through the arm into the inserts in its roof, snug.

### Step 12: build the radiation shield

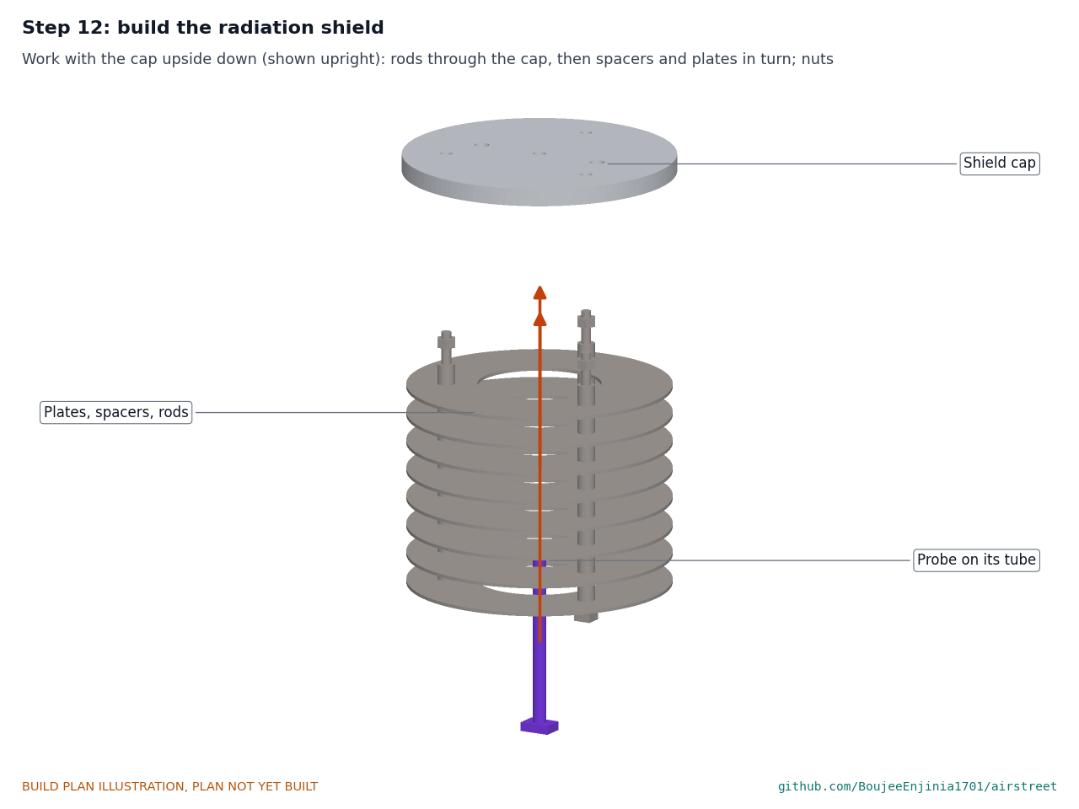
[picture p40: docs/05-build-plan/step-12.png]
Step 12


Work with the cap upside down (the picture shows it upright). Push the three rods through the cap and fit the nyloc nuts on the cap's top face. Then thread on, in turn, a 9.25 mm spacer on each rod, a plate, 11.5 mm spacers, a plate, and so on to the eighth plate, and fit an acorn nut on each rod, snug. Push the probe tube through the cap's centre hole from below, the probe board in the middle of the stack.

### Step 13: shield onto the cross arm

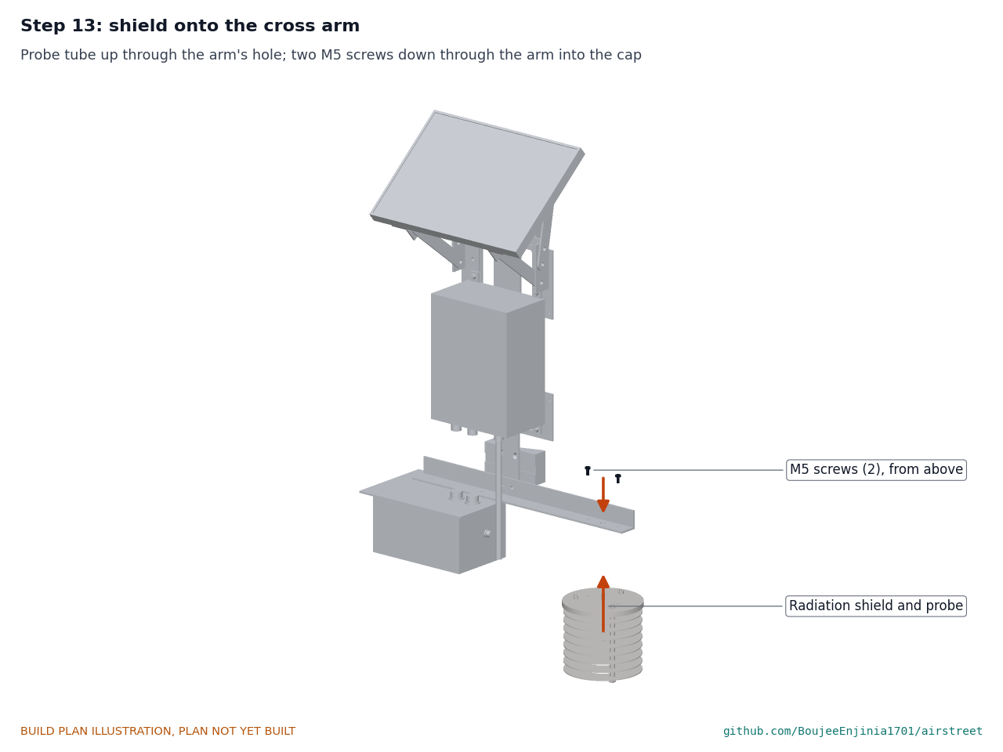
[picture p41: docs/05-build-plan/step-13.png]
Step 13


Feed the probe lead and tube up through the arm's grommet, lift the cap flat under the arm's right end, and fit two M5 x 10 pan-head screws down through the arm into the cap's inserts. Seal the tube in the cap with a bead of silicone.

### Step 14: cables

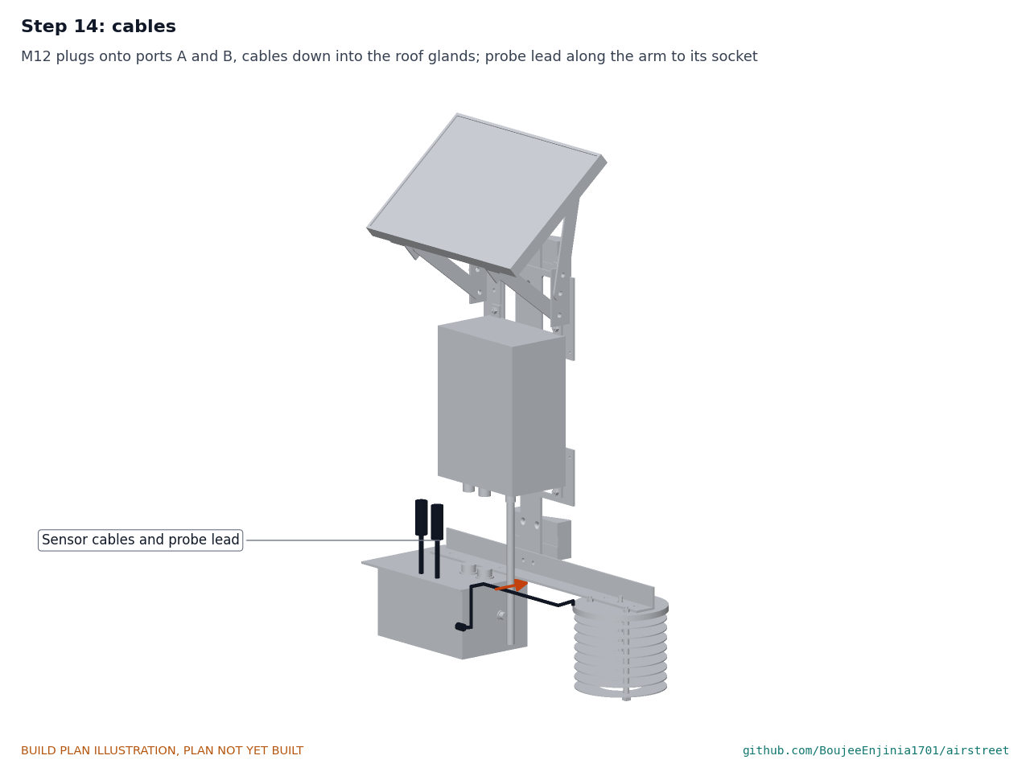
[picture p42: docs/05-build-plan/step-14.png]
Step 14


Plug each M12 cable into its FieldNode port (port A left, port B right) and tighten the coupling nut by hand; each cable drops straight down to its roof gland.

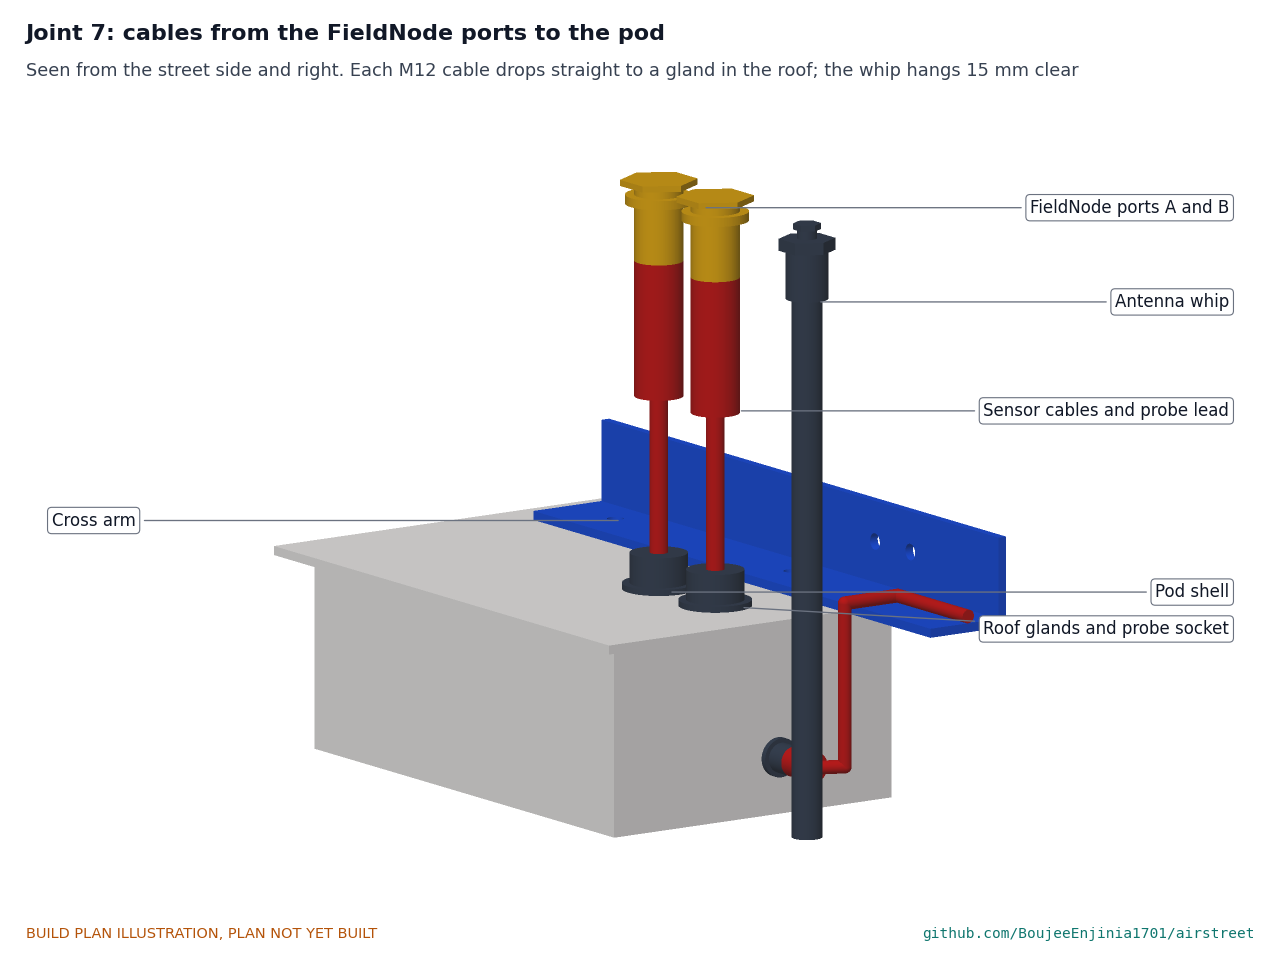
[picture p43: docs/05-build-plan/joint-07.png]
Figure 18. Joint 7: cables from the ports to the pod


*Figure 18. Each M12 cable runs straight down to a gland in the pod roof; the probe lead runs along the top of the arm, then down to its socket on the pod's right wall. The antenna whip hangs 15 mm clear of the drip lid.*

Run the probe lead along the top of the arm's flat leg against the upright leg, tie it to the arm every 50 mm, bring it down at the arm's middle and plug it into the pod's socket. **Hold point:** the probe lead does not touch the antenna whip.

### Step 15: onto the pole with the bands

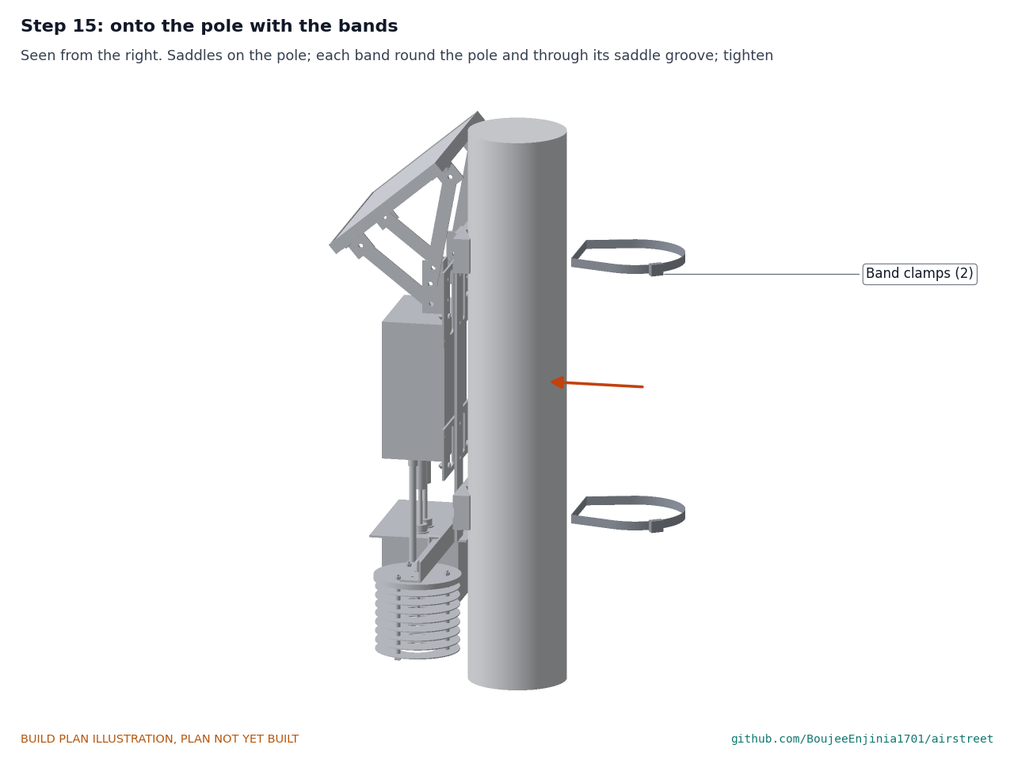
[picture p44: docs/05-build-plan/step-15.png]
Step 15


Seen from the right. Clamp a pole stub upright to a stand that cannot tip under about 4 kg. Hold the node with both saddles on the pole. Pass each band round the far side of the pole and through its saddle's groove between saddle and rail, fit the housing at the side of the pole where a screwdriver reaches it, and tighten both bands evenly to the band maker's torque; record it. Trim the band tails and file the cut ends. **Hold point:** safety stop S5 in section 6.

### Step 16: FieldNode's sun shield (hot sites only)

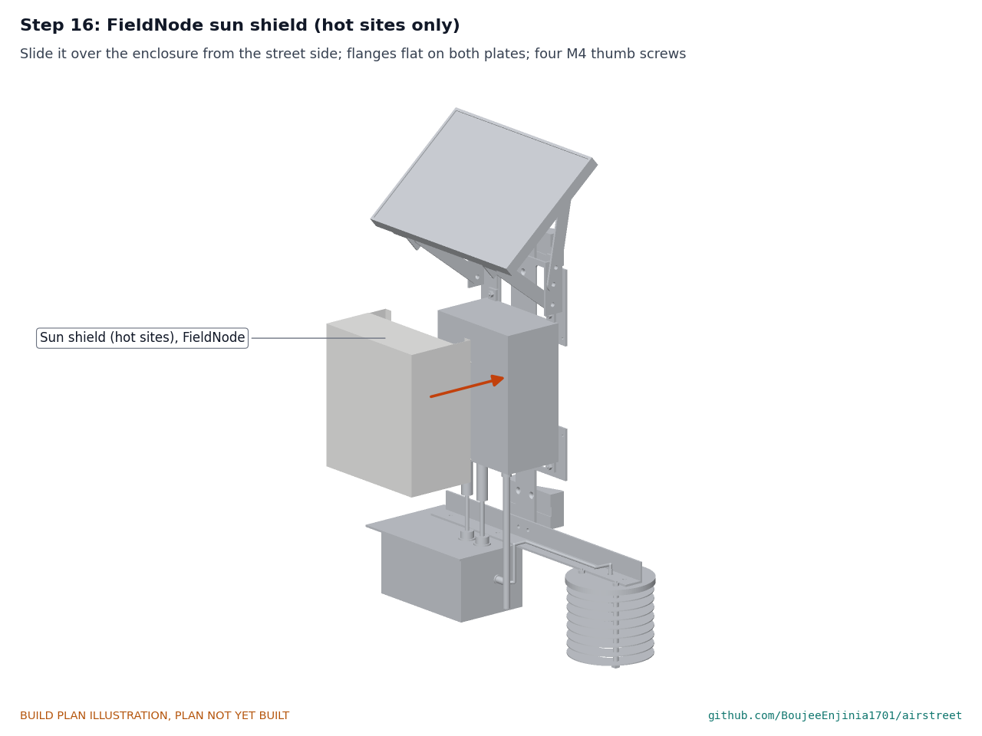
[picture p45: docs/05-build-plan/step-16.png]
Step 16


Slide the shield over the enclosure from the street side until its flanges lie flat on both adapter plates, and fit the four M4 thumb screws into the tapped holes, finger tight.

## 5. First checks

These are the checks a TRL 4 test report would record; this plan only lists them. Requirement numbers are those of AST-REQ-001.

*Table 2. First checks.*

| Check | Requirement | How | Pass when |
| --- | --- | --- | --- |
| Pole range | R11 | Seat the mount on 80, 140 and 200 mm tubes | Both saddles touch the tube on both V faces; each band closes with adjustment to spare |
| Band torque | R11, R13 | Torque screwdriver on each band housing | The maker's torque is reached with no band slip; value recorded |
| Inlet height | R11 | Measure from the mesh to the pole's ground mark on the stub | The mesh is level and the inlet plane can be set 3.0 m above the sidewalk |
| Mass | R13 | Weigh the node off the pole, with and without FieldNode's sun shield | Recorded; the estimate is 3.62 kg without the shield and 3.78 kg with it, against 4.0 kg with it |
| Port supplies | R9 | Bench supply in place of the cell as FieldNode's plan; measure 5 V at each M12 plug with the pod unplugged | Port A switches on and off from the controller; port B stays on |
| Sensor current | R9 | Pod plugged in; measure each port's current over a particle run | Port A about 55 mA while the particle sensor runs; port B a few milliamps, continuously |
| Readings arrive | R7, R8 | Read every sensor over its bus from the controller | Particle, NO2 working and auxiliary, temperature and humidity values all arrive |
| Drip lid and inlets | R12 | Pour water over the pod from above, then look inside through a slot | No water inside; the mesh covers both slots and the NO2 window |
| Pod exchange | R16 | Time a pod exchange with hand tools: unplug two M12 plugs and the probe plug, two screws out, fit a second pod | 15 minutes or less including the access time allowance |
| Shield stack | R5 | Measure plate spacing and the probe's clearance | 13 mm pitch; probe board clear of every plate |
| Antenna clearance | R8 | Measure whip to drip lid | 15 mm or more |

## 6. Safety stops

Stop at each point. Carry on only when everything listed is true.

- **S1. FieldNode's own stops.** Every safety stop in FieldNode's build plan (cell, fuse, charger, first charge, radio) applies to the core, at the same points in its build.
- **S2. Before the pod is plugged in.** With the cell out and the fuse out, continuity checked from each M12 plug pin to its board terminal; no short between 5 V and ground on either cable.
- **S3. Before the NO2 sensor's shorting spring comes off.** The front end is wired and ready to power; the sensor is undamaged with no electrolyte on its pins. Wash hands after handling a damaged sensor and dispose of it as its maker directs.
- **S4. Before the radio transmits.** The antenna is connected and matches the pilot region's band.
- **S5. Before the node goes on the pole stub.** Every bolt tight with nyloc nuts where shown, the panel glass whole, sharp edges and band tails deburred. The stub is clamped to a bench or stand that cannot tip under about 4 kg.
- **S6. Before any installation on a street pole (outside this plan).** The pole owner's written permission; a trained crew with a mobile elevating work platform or a secured ladder and a second person; traffic management as local rules require; the pole owner has confirmed the pole can carry about 125 N of wind load 3.3 m up, and a load on the pole of 4.0 kg. Never open the pole's access door or touch its wiring: street light poles carry mains voltage.

## 7. Tools, skills and workspace

**Tools.** Hacksaw with a 24 teeth per inch blade (or a bandsaw); bench vice with soft jaws; bench drill or a drill in a stand; drills 2.5 to 16.2 mm and a step drill; countersink; M4 tap and tap drill; flat and half-round files; deburring tool; scriber, engineer's square, steel rule and calipers; 3D printer with an enclosure that prints ASA on a bed of at least 200 x 140 mm; soldering iron with a heat-set insert tip; band cutter or tin snips; screwdrivers and hex keys; torque screwdriver covering about 1 to 6 N·m; digital angle finder; ferrule crimper and wire strippers; multimeter; bench power supply with an adjustable current limit; scale to 5 kg; stopwatch. FieldNode's build plan lists the tools for the core.

**Skills.** No certified trade is needed. Basic metalwork (marking out, sawing, drilling, countersinking, tapping), 3D printing in ASA, setting heat-set inserts, through-hole soldering and crimping, and care with lithium cells and gas sensors. All circuits are extra-low voltage: 5 V at the sensors and under about 15 V anywhere in the core.

**Workspace.** A bench about 1.2 x 0.6 m; a metalwork corner kept apart from the electronics so chips stay off the boards; a ventilated place for the printer and the insert iron; a stand or vice that holds a pole stub upright.

**Personal protective equipment.** Safety glasses for cutting, drilling, soldering and band cutting; cut-resistant gloves for bar, sheet and band; hearing protection when sawing; no gloves near a turning drill; nitrile gloves to handle a damaged NO2 sensor.

## 8. Where the numbers come from

- Model and constructability checks: `cad/src/model.py` (`python cad/src/model.py --check`, 77 checks), using FieldNode's model vendored as `cad/src/fieldnode_core.py`; STEP and STL exports in `cad/step/` and `cad/stl/`.
- Pictures: `cad/src/build_plan_media.py`, using `.kit/build_views.py`; written to `docs/05-build-plan/` and `cad/drawings/AST-DWG-101` to `AST-DWG-109`.
- General arrangement: `cad/drawings/AST-DWG-001.pdf`, Rev P5.
- Calculations: `docs/04-calcs/01-sizing.md` (AST-CAL-001 v0.6) and `docs/04-calcs/sizing.py`: mass [F4], [F5], [F8], band lengths [F7], mounting loads [G2] to [G7], service time [H1].
- Bill of materials: `bom/bom.csv`.
- Decisions: `docs/decisions/0003-design-for-construction.md` (AST-DDR-003), with AST-DDR-001 and AST-DDR-002; the design decisions register `docs/06-design-decisions.md` (AST-DEC-001).
- Requirements: `docs/03-requirements.md` (AST-REQ-001 v0.8).
- FieldNode core: FieldNode's build plan FND-BLD-001 and calculation note FND-CAL-001 v0.3, in the fieldnode repository.

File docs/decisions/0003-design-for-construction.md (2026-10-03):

---
doc_id: AST-DDR-003
title: AirStreet design for construction
project: AirStreet
doc_type: Design decision record
version: "0.4"
status: Draft
date: '2026-10-02'
author: Amish Chadha
license: CERN-OHL-S-2.0
revisions:
- version: "0.1"
  date: '2026-09-30'
  author: Amish Chadha
  change: Changes that make the concept physically buildable, with the reason for each; made under Amish's 2026-09-30 instruction to make the design physically buildable; open for his review
- version: "0.2"
  date: '2026-10-01'
  author: Amish Chadha
  change: Budget treated as a value-engineering target
- version: "0.3"
  date: '2026-10-02'
  author: Amish Chadha
  change: "Accepted by Amish (2026-10-02), with the recommendations for A1 and A3; status kept Draft"
- version: "0.4"
  date: '2026-10-02'
  author: Amish Chadha
  change: "A1 carried out: the four lightening steps are in the model, BOM, calculations, drawings and build plan (3.78 kg with the sun shield; R13 met on paper); A1's 3.6 kg figure shown to exclude the sun shield; consequences updated"
---

# 0003: Design for construction

- **Date:** 2026-09-30
- **Status:** accepted. Amish, 2026-10-02: "i approve your recommendations for all 555 open decisions." This covers every change in Tables 1 and 2 and the recommendations for A1 and A3 in Table 3, which are now decided as recommended and recorded in the design decisions register (AST-DEC-001). A2 is a value-engineering note, not a decision; its route back to the target stands.

## Context

On 2026-09-30 Amish asked for a build plan that shows how each component is made and how it fits the next, with pictures, and wrote: "If you are realising that the design cannot be built as per concept - fix the design assumptions to match and be physically feasible as you draw the illustrations." The TRL 3 model of AirStreet (AST-DDR-002) showed what the node does, but at massing level: several parts could not be made or fixed as drawn, and the FieldNode core it hung from has since been made constructable in its own repository (FND-DDR-003), which moved its antenna, gave its enclosure external lugs and rebuilt its panel bracket from angle clips on its back plate.

The changes keep what the node does: the same sensors, front end, shield, inlet height (3.0 m), pole range (80 to 200 mm), clamp positions, FieldNode core, panel and hood, and the same pod exchange for service. Nothing here changes the pitch or the safety case. Every change is in `cad/src/model.py`, which now imports FieldNode's own constructable model (vendored as `cad/src/fieldnode_core.py`) and runs 71 constructability checks (`python cad/src/model.py --check`): parts that must touch do touch, and parts that must stay apart are apart by at least the stated clearance. All 71 pass.

## Decision

*Table 1. Changes made to the model, the BOM and the calculations.*

| # | Problem in the concept | Change made | Why this way |
| --- | --- | --- | --- |
| P1 | The FieldNode core was an envelope with FieldNode's TRL 3 layout (ports and antenna in one row, whip 58 mm right of centre). FieldNode's constructable core has two rows of penetrations and its whip 30 mm right of centre, which would hang through the pod's drip lid. | The model uses FieldNode's own constructable model, moved into place. The pod moves from 70 to 90 mm left of the pole, so the whip hangs 15 mm clear of the drip lid (23 mm in the concept). | AirStreet builds the FieldNode core exactly as FieldNode does; the pod is the part that can move. |
| P2 | The enclosure was to bolt "straight to the rail", but its four lugs are 124 mm apart across and the rail is 40 mm wide. The two 180 x 25 x 3 mm adapter bars had no holes for FieldNode's bracket, which now starts from angle clips on a flat plate. | Two 3 mm aluminium adapter plates, 180 x 75 and 180 x 110 mm, each bolted to the rail by two M5 countersunk bolts. They carry the hole pattern of FieldNode's back plate for the lugs and the plate clips, and the enclosure back sits flat on both. | FieldNode's lugs, clips, screws and bracket fit unchanged. The plates keep most of the mass saved by leaving off FieldNode's back plate (AST-DDR-002 N2). |
| P3 | FieldNode's sun shield, required at sites above 45 °C (AST-DDR-002 N6), screws into its back plate 40 and 180 mm above the enclosure base; with the back plate left off it had nothing to fix to. | The adapter plate heights are set so that both rows of shield screw holes (M4, tapped) land on them. | The shield fits at a hot site with no extra part. |
| P4 | V-saddles 60 x 40 x 16 mm with a round seat cut to the 140 mm design pole; a round seat cannot seat the 80 to 200 mm range of R11. | Printed ASA V-saddles 100 x 50 x 24 mm with a 140° V. A 140 mm pole touches both faces 24 mm each side of centre; 80 and 200 mm poles at 14 and 34 mm; never on the V's edges. | A shallow V seats the whole range in a part small enough to print; the rail stands off the pole by the same amount as before. |
| P5 | Bands drawn as rings round the pole plus a strap across the rail front, with no path past the saddles; and one worm-drive clamp does not span 80 to 200 mm. | Each band runs round the far side of the pole and through a 14 x 1.5 mm groove across the back of its saddle, between saddle and rail. Bands are cut to length from a 12.7 mm stainless worm-drive band roll with separate housings (487 mm round the 140 mm pole, 326 to 664 mm over the range, plus about 100 mm). | The band pulls the saddle onto the pole and cannot slide off it; one band stock covers every pole in the range. |
| P6 | The saddles had no fixing to the rail. | Two M5 countersunk screws through the rail into heat-set inserts in each saddle. | Keeps the saddles on the rail on the bench and while the bands go on. |
| P7 | The shield arm (20 x 8 mm bar with a gusset) only touched the rail's edge, and the pod had no fixing at all. | One 30 x 30 x 3 mm aluminium angle, 415 mm long, bolted flat to the rail by two M5 bolts. The pod hangs under it on two M5 screws from above into inserts in the pod roof, and the shield cap on two more. The rail now ends at the arm (451 mm, was 565 mm). | One part carries both and every screw is reached from above; a pod exchange is two screws and three plugs (R16). |
| P8 | The pod was a closed solid with its sensors floating inside: there was no way to fit them, and the floor slots left no solid floor to mount the sensors on. | A printed shell (walls, roof and drip lid in one, open at the bottom) and a separate printed sensor floor on four M3 screws into corner bosses, with the mesh clamped under it. The floor carries a cradle that holds the PM sensor on edge 8 mm above the floor, inlet down, and a collar that holds the NO2 sensor face down over a 28 mm window. The inlet slots become 50 x 50 and 50 x 40 mm. The front end stands on four standoffs on the back wall, with a small terminal block beside it. | The sensors drop into the floor from above and the floor closes the pod from below; the concept's sensor positions and inlet faces are kept. |
| P9 | The sensor cables ended on top of the drip lid with no way through it, and the probe lead had no connector, so the pod could not be unplugged for an exchange. | Two M16 glands in the pod roof directly under FieldNode's ports A and B; the probe lead ends in an M8 4-pin plug on a socket in the pod's right wall. | Straight cable drops; the pod unplugs from the probe as the service step (AST-CAL-001 H1) assumes. |
| P10 | Shield plates floated on the rods with no spacers, the cap had no fixing, and the probe hung from nothing. | 24 printed spacers (8 mm outside) on three M5 rods through the cap, nuts top and bottom; the cap screws up under the cross arm; the SHT45 board is glued to the end of a 6 mm aluminium tube that passes up through the cap and an 8 mm hole in the arm, and the lead runs along the arm to the pod. | Plate pitch, count and size are unchanged, so the radiation error result (AST-CAL-001 D) stands. |

*Table 2. Knock-on changes.*

| Item | Change | Reason |
| --- | --- | --- |
| Mass | 3.84 kg on the pole (was 3.26 kg); 4.00 kg with FieldNode's sun shield [F4], [F5]. R13 (3.5 kg) is now **not met**. | FieldNode's constructable core is 0.15 kg heavier as used; the adapter plates, cross arm, larger saddles, pod floor and fixings add the rest. See Table 3, A1. |
| Frontal area | 0.143 m² (was 0.126 m²) against 0.15 m² [F3]; met on paper. | Taken from the model; FieldNode's bracket and the plates show more. |
| Cost | BOM lines 1, 3, 4, 8, 9, 10 and 11 revised: sensor head $303.00 (was $285.00) against the $285 value-engineering target (`budget_usd`); R15 is now **over the target by $18.00** [I1], [I2]. FieldNode core as used $131.00 (FieldNode's $139.00 less its unused pole mounting kit). Whole node $434.00. | Plates, arm, band stock, spacers, inserts, glands, probe socket and fixings. See Table 3, A2. |
| Mounting loads | Cross arm 4.5 MPa, its bolts about 67 N each in a 35 m/s gust, rail 16.4 MPa at the lower clamp, pod screws about 11 N each [G3], [G4], [G6], [G7]. Clamp slip factor 24 [G2]. | New load paths, all with large margins. |
| Drawings | AST-DWG-001 Rev P4; making sketches AST-DWG-101 to 109 added. (Rev P5 and sketches 101, 103, 104 and 108 at P2 after the A1 lightening, 2026-10-02.) | Follows the model. |
| Documents | AST-CAL-001 v0.3, AST-REQ-001 v0.5, AST-PRC-001 v0.5: mass, area, cost, mount and pod figures updated. | Follows the model. |

*Table 3. Items proposed to Amish; A1 and A3 accepted as recommended on 2026-10-02 (A1 with the limit set at 4.0 kg including FieldNode's sun shield).*

| # | Question | Options | Recommendation |
| --- | --- | --- | --- |
| A1 | Mass on the pole is 3.84 kg (4.00 kg with the sun shield) against R13's 3.5 kg. | (a) raise the R13 limit to 4.0 kg, with the pole owner confirming the load; (b) lighten: print the saddles at 40 % infill, use 40 x 4 mm rail, 1.5 mm shield plates and cut windows in the adapter plates, which gives about 3.6 kg and still misses 3.5 kg; (c) both. | (c): adopt the lightening at TRL 4 and set the limit to 4.0 kg. Accepted 2026-10-02: R13 is 4.0 kg including FieldNode's sun shield, the pole owner is asked to confirm the load, and the four lightening steps are carried into the TRL 4 build. Carried into the design on 2026-10-02 (AST-CAL-001 v0.6 [F8]): 3.62 kg without the sun shield and 3.78 kg with it, so the "about 3.6 kg" above excludes the shield. |
| A2 | Value engineering (a note, not a decision). Sensor head parts cost $303.00 against the $285 value-engineering target (`budget_usd`), $18.00 over ($302.50 and $17.50 after the A1 lightening and repricing, 2026-10-02). | (a) recover the $18 with the open two-channel NO2 front end (about $35 cheaper, PCB work on hold with TRL 4); (b) look for cheaper band hardware and fixings at purchase. | (a) as the route back to the target, with (b) at purchase. |
| A3 | The whip now hangs 15 mm from the pod's drip lid, not 23 mm. | (a) accept, and check the radio link with the pod fitted at TRL 4; (b) move the pod a further 8 mm left, widening the node. | (a). Accepted 2026-10-02: check signal strength with the pod fitted at TRL 4 and move the pod only if that check shows a loss. |

## Consequences

- `design_state: constructable` in `project.yaml`. The build plan AST-BLD-001 shows every component and step in pictures generated from the model (`cad/src/build_plan_media.py`); open decisions are in the register AST-DEC-001.
- Requirement status (AST-CAL-001 v0.3): 1 not met (R13), 1 over the value-engineering target (R15), 5 at risk (R1, R2, R4, R5, R12), 4 met on paper (R8, R9, R10, R16), 4 met by design (R6, R7, R11, R14), R3 withdrawn. With A1 accepted on 2026-10-02, R13's mass limit is 4.0 kg including FieldNode's sun shield: the node meets it with no margin (4.00 kg), so R13 is now at risk rather than not met, and the lightening at TRL 4 gives the margin (AST-REQ-001 v0.7). The lightening was then carried into the model, BOM and calculations on 2026-10-02 (AST-CAL-001 v0.6): 3.78 kg with the sun shield, 0.22 kg under the limit, so R13 is met on paper (AST-REQ-001 v0.8). Status counts are now 1 over the value-engineering target (R15, $17.50), 5 at risk, 5 met on paper, 4 met by design and R3 withdrawn.
- Cross-repo: with register decision 5 approved on 2026-10-02, FieldNode is to be asked to accept its enclosure, plate clips and sun shield on AirStreet's two adapter plates in place of its back plate (this replaces the adapter-bar request of AST-DDR-002 N2), and to keep `cad/src/model.py` stable, since AirStreet carries a copy.
- `media/card.png` and `media/social-preview.png` and the photoreal renders (made on Amish's Mac) show the concept mount and pod and are stale. On 2026-10-02 the appearance model `cad/src/product_model.py` was brought into line with the constructable, lightened design and its render scenes exported; the photoreal renders and the cards are to be made from them on Amish's Mac.

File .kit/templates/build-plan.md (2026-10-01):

---
doc_id: PRJ-BLD-001
title: Project prototype build plan
project: Project name
doc_type: Build plan
version: "0.1"
status: Draft
date: YYYY-MM-DD
author: Amish Chadha
license: CERN-OHL-S-2.0
revisions:
  - version: "0.1"
    date: YYYY-MM-DD
    author: Amish Chadha
    change: First build plan; design made constructable
---

# Project prototype build plan

**Plan, not yet built.** How to build the first proof-of-concept prototype, component by component. Building and testing to it is TRL 4 work. Decisions still to be made are kept in the design decisions register (`docs/06-design-decisions.md`), not here.

## 1. What you are building

Every component, pulled apart and numbered in build order

One short paragraph: what the prototype is, how many components, which are made and which are bought, and the main ways they are made.

## 2. What changed to make it buildable

| Component | The concept had | The buildable design has | Why |
| --- | --- | --- | --- |

## 3. Making the components

### 3.1 Component name

Making sketch

**What it is and what it is made from.**

**How to make it.**

1. Mark out ...
2. Cut ...

**How it fits the parts next to it.**

Close-up of the joint

**Check before moving on.**

## 4. Putting it together

### Step 1: ...

Step 1

## 5. First checks

| Check | Requirement | How | Pass when |
| --- | --- | --- | --- |

## 6. Safety stops

## 7. Tools, skills and workspace

## 8. Where the numbers come from

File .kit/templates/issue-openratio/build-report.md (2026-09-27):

---
name: Build report
about: Tell us what happened when you built, printed or tested part of this design
title: "Build report: "
labels: build-report
---

This is a research and educational prototype, not a medical device. It is a TRL 3 concept and is not released for fabrication. If you build any part of it, you do so at your own risk. Reports help everyone.

**What you built** (part, sub-assembly or test)

**Materials, tools and settings**

**What worked**

**What did not work, with photos or measurements if you have them**

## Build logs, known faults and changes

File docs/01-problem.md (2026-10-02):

---
doc_id: AST-PRB-001
title: AirStreet problem statement
project: AirStreet
doc_type: Problem statement
version: "0.5"
status: Draft
date: '2026-10-02'
author: Amish Chadha
license: CERN-OHL-S-2.0
revisions:
- version: "0.1"
  date: '2026-09-25'
  author: Amish Chadha
  change: Initial scaffold
- version: "0.2"
  date: '2026-09-25'
  author: Amish Chadha
  change: Populate to TRL 2 (problem, users, context, constraints, prior work)
- version: "0.3"
  date: '2026-09-25'
  author: Amish Chadha
  change: TRL 3 update; constraints and open questions reflect AST-DDR-001 and AST-CAL-001
- version: "0.4"
  date: '2026-09-25'
  author: Amish Chadha
  change: Recommendations accepted by Amish (DDR-002)
- version: "0.5"
  date: '2026-10-02'
  author: Amish Chadha
  change: "First partner rule and first candidate to approach (AST-DEC-001, 2026-10-02)"
---

# AirStreet problem statement

Regulatory air monitors are few and far apart, missing the streets where people breathe traffic pollution.

## The problem

Traffic pollution varies sharply over short distances, but official monitoring is designed to describe whole cities. When Google Street View cars carrying reference-grade instruments drove every street in a 30 km² area of Oakland, California, nitrogen dioxide (NO2), nitric oxide and black carbon varied by up to 5 to 8 times within single city blocks ([Apte et al., 2017](https://pubs.acs.org/doi/10.1021/acs.est.7b00891)). A single fixed station cannot show that pattern, and many cities have no station at all. Only 12 % of India's 4,041 census cities and towns have any air quality monitoring ([CSE, 2023](https://www.cseindia.org/only-12-per-cent-of-india-s-census-cities-and-towns-have-air-quality-monitoring-stations-11779)), and in 2020 OpenAQ found no public national government monitoring program in 13 populous countries, including Pakistan, Nigeria, Ethiopia, Kenya and Uganda ([OpenAQ, 2020](https://documents.openaq.org/reports/Open+Air+Quality+Data+Global+State+of+Play+2020.pdf)).

The health stakes are large. Ambient air pollution caused an estimated 4.2 million premature deaths worldwide in 2019 ([WHO](https://www.who.int/news-room/fact-sheets/detail/ambient-(outdoor)-air-quality-and-health)). NO2 comes mainly from burning fuel in cars, trucks, buses, power plants and off-road equipment ([US EPA](https://www.epa.gov/no2-pollution/basic-information-about-no2)), so it is highest on busy streets, and more than 45 million people in the United States live within about 90 m (300 ft) of a major transportation facility ([US EPA](https://www.epa.gov/air-research/research-near-roadway-and-other-near-source-air-pollution)).

Low-cost sensors could fill the gap between stations, but raw readings are not trusted. Uncorrected PurpleAir particle sensors overestimated PM2.5 by about 40 % across the United States until a humidity-aware correction cut the error from 8 to 3 µg/m³ ([Barkjohn et al., 2021](https://amt.copernicus.org/articles/14/4617/2021/)). Electrochemical NO2 sensors respond to temperature, humidity and other gases, and laboratory calibration alone does not correct this; in a Pittsburgh study only field-calibrated models reached a mean absolute error of about 3.5 ppb for NO2 ([Zimmerman et al., 2018](https://amt.copernicus.org/articles/11/291/2018/)).

AirStreet addresses one specific gap: an open, pole-mounted node that measures PM2.5 and NO2 at street level, with a calibration method stated up front, so a city, school or community group can build a neighborhood map that others can check.

## Users and context

| User | Need | Context |
| --- | --- | --- |
| Residents and community groups | See pollution on their own streets, near schools and clinics, and track whether it changes | Street poles on residential and arterial roads |
| Municipal environment and transport teams | Evaluate interventions such as low-traffic streets, school streets, bus corridors and freight routes | 10 to 100 nodes per district, alongside at least one reference station |
| Schools and universities | Teaching and research on exposure, with raw data and a documented method | Campus and nearby streets |
| Street furniture owners (utilities, city lighting) | A small, light device that does not interfere with the pole or its wiring | Street light and signal poles |
| Researchers and data platforms | Raw signals and calibration versions, so data can be reprocessed | Open data portals |

## Operating environment

- Mounted on a street light or signal pole, inlets 3.0 m above the sidewalk (AST-DDR-001 D7, decided by Amish on 2026-09-25), on the street side and within a few meters of the kerb.
- Outdoor, in sun, rain, dust and traffic spray; temperate to hot humid climates (about -10 to 50 °C, 10 to 100 % RH, estimate to be confirmed with partners). FieldNode is rated to 45 °C ambient, so sites hotter than that need FieldNode's sun shield (AST-DDR-002); the SPS30 particle sensor is recommended for 20 to 80 % RH, so the most humid sites remain at risk (AST-CAL-001).
- No mains power: runs on the FieldNode solar and battery core.
- Data over LoRaWAN: every 5 min through a private gateway (the lab's TwinKit gateway by default), or every 15 min on The Things Network, whose fair-use policy a 5 min interval would exceed (AST-DDR-002).

## Constraints

- Garage-buildable prototype. The $285 `budget_usd` covers the AirStreet sensor head; the FieldNode core is costed in FieldNode (AST-DDR-001 D1 and AST-DDR-002). The sensor head costs $285.00 at TRL 3 prices, within the budget with no margin (see [03-requirements.md](03-requirements.md)).
- Built on FieldNode, the lab's shared outdoor core, with its power budget and sensor port pinout.
- Temperature, humidity and particle checks on CalRig. CalRig does not cover NO2, so NO2 must be calibrated by field collocation with a reference station.
- Levels only: no images, audio or personal data collected or sent.
- Mounting only with the pole owner's permission, without drilling the pole or opening its electrical access.

## Out of scope

- Regulatory compliance monitoring. AirStreet data are indicative and do not replace reference stations.
- Other pollutants (ozone, carbon monoxide, black carbon, ultrafine particles) in this version.
- Personal exposure devices and indoor use.
- Health advice or medical claims.

## Prior work

- Street-scale mapping with reference instruments on vehicles showed block-level variation ([Apte et al., 2017](https://pubs.acs.org/doi/10.1021/acs.est.7b00891)).
- Community and city networks of low-cost sensors already operate, for example AirQo, which reports more than 400 PM2.5 sensors across 14 African countries ([AirQo](https://www.airqo.net/)), and Breathe London, a sensing network developed with the Mayor of London ([Breathe London](https://www.breathelondon.org/)).
- The US EPA published performance testing protocols for NO2, CO and SO2 sensors in February 2024, including field evaluation alongside regulatory monitors ([US EPA](https://www.epa.gov/air-sensor-toolbox/air-sensor-performance-targets-and-testing-protocols)).
- Humidity correction for optical particle sensors ([Barkjohn et al., 2021](https://amt.copernicus.org/articles/14/4617/2021/)) and field calibration of electrochemical gas sensors ([Zimmerman et al., 2018](https://amt.copernicus.org/articles/11/291/2018/)) are established methods that AirStreet adopts rather than reinvents.

What is missing is an open, documented node design that pairs these sensors with a stated, repeatable calibration route and publishes raw signals.

## Open questions

- Which city and partner first, and which reference station can host a collocation? Decided on 2026-10-02 as a rule (AST-DEC-001): a city or air agency with a regulatory NO2 reference station at a street-level site and willing to share its data; first candidate to approach, the Texas Commission on Environmental Quality's Dallas-Fort Worth monitoring network with a local university or city partner. Nothing is agreed yet.
- Inlet height: 3.0 m is decided (AST-DDR-001 D7); partners may still ask for a lower inlet, closer to the breathing zone, which would reopen that decision.
- Is NO2 accuracy of about 4 to 5 ppb hourly, which cannot resolve the WHO annual guideline but can rank streets, useful enough for the first partner's questions? To be tested with users. Resolving the WHO guideline is no longer a requirement; it is kept as a research question (AST-DDR-002).

## User research and co-design

This design is for communities the author is not part of, so requirements come from the people who will use it.

- [ ] Identify a local partner organization (Helpful Engineering network, NGO or university)
- [ ] Run co-design sessions with intended users; record who, where and what was learned
- [ ] Validate load, distance, terrain and cost assumptions in the field
- [ ] Revise requirements (REQ) from findings before freezing the design

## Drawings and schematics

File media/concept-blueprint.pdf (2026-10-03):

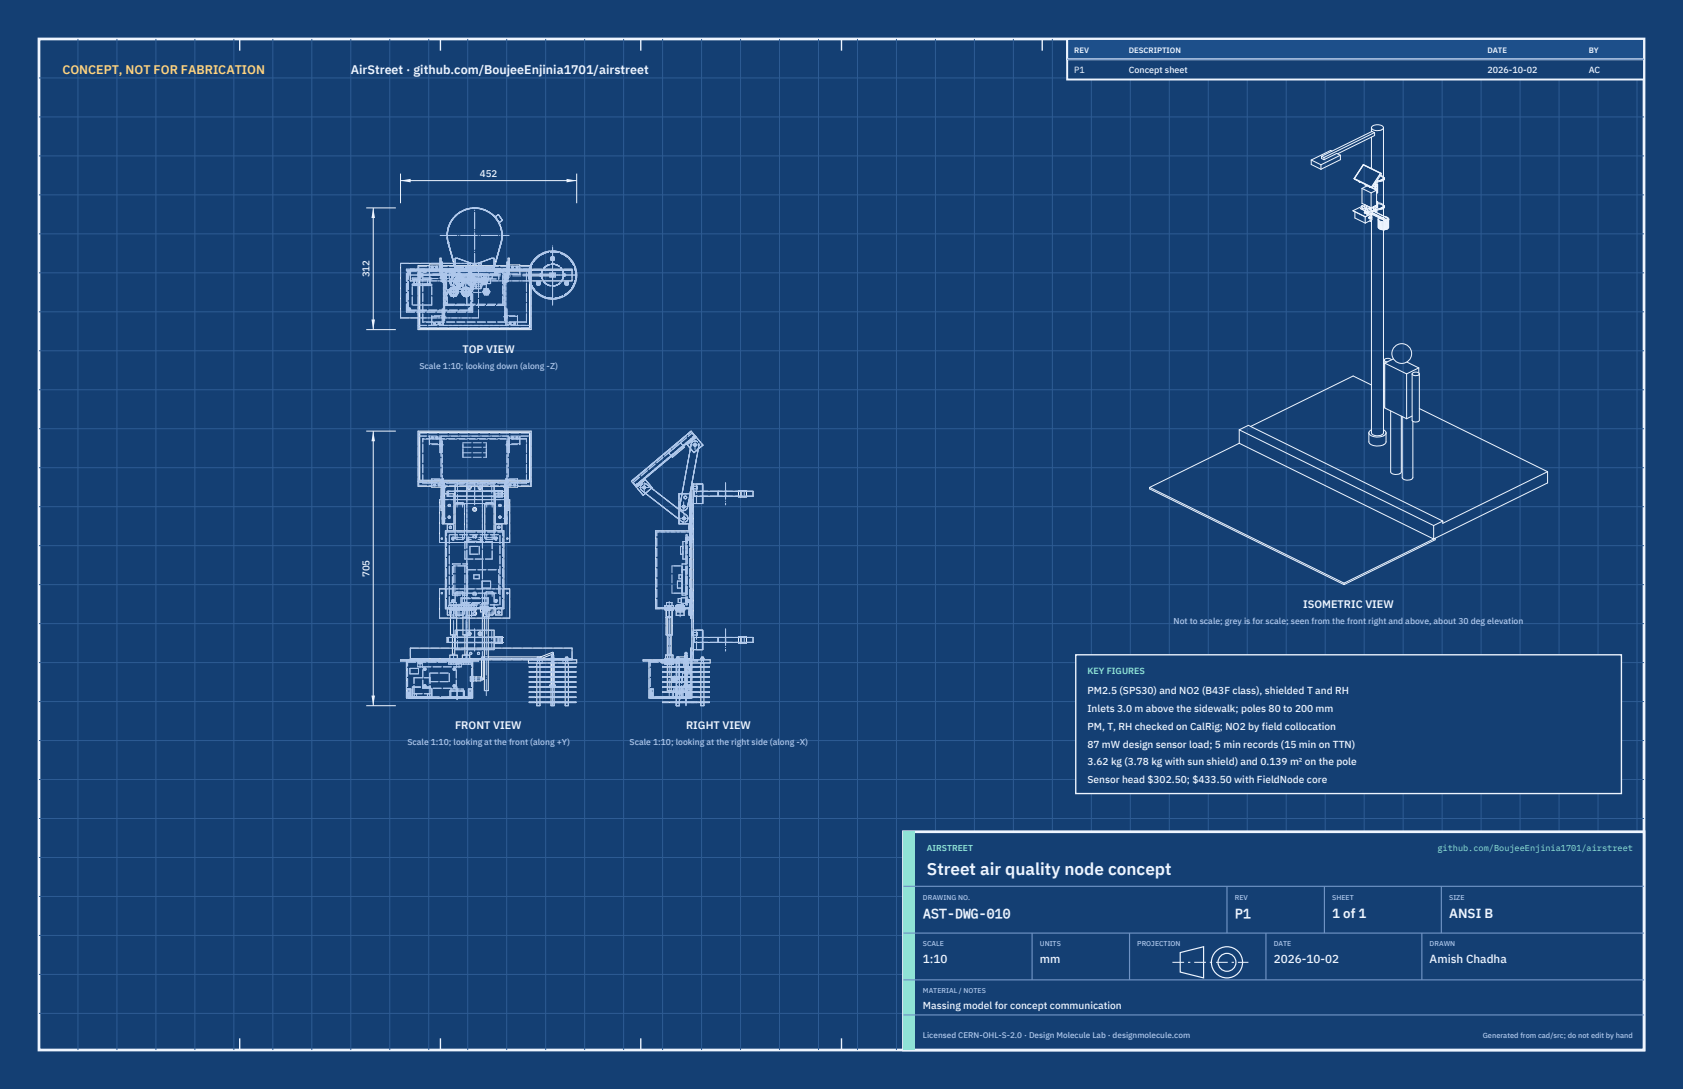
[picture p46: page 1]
CONCEPT, NOT FOR FABRICATION; AirStreet · github.com/BoujeeEnjinia1701/airstreet; FRONT VIEW; TOP VIEW; RIGHT VIEW; ISOMETRIC VIEW; REV; DESCRIPTION; DATE; Concept sheet; AIRSTREET; github.com/BoujeeEnjinia1701/airstreet; DRAWING NO. AST-DWG-010; REV P1; SHEET 1 of 1; SIZE ANSI B; SCALE 1:10; UNITS mm; PROJECTION; DRAWN Amish Chadha; Licensed CERN-OHL-S-2.0 · Design Molecule Lab · designmolecule.com; Generated from cad/src; do not edit by hand

Scale 1:10; looking down (along -Z)

Not to scale; grey is for scale; seen from the front right and above, about 30 deg elevation

KEY FIGURES
PM2.5 (SPS30) and NO2 (B43F class), shielded T and RH
Inlets 3.0 m above the sidewalk; poles 80 to 200 mm
PM, T, RH checked on CalRig; NO2 by field collocation
87 mW design sensor load; 5 min records (15 min on TTN)
3.62 kg (3.78 kg with sun shield) and 0.139 m² on the pole
Sensor head $302.50; $433.50 with FieldNode core

Scale 1:10; looking at the front (along +Y)

Scale 1:10; looking at the right side (along -X)

Street air quality node concept

MATERIAL / NOTES
Massing model for concept communication

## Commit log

2026-09-25 Initial scaffold: standard open hardware layout, CERN-OHL-S v2 + MIT licenses
    Claude-Session: https://claude.ai/code/session_01XuhhSU4W6fYhgCfURbrkut
    [bom.csv]
2026-09-26 Populate to TRL 2: problem, requirements, precis, concept media, BOM and README use cases
    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
    [bom.csv]
2026-09-26 Advance to TRL 3: DDR-001, CAL-001 sizing, parametric model with STEP/STL, GA drawing, priced BOM; TRL 4 on hold
    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
    [airstreet-assembly.step, airstreet-assembly.stl, airstreet-mount.step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]
2026-09-26 Accept all recommendations (DDR-002), switch footer to designmolecule.com, add README write-up with new inspiration point
    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
    [airstreet-assembly.step, airstreet-assembly.stl, airstreet-mount.step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]
2026-09-27 Product appearance model and photoreal renders
    Adds cad/src/product_model.py (appearance model for renders only, all main
    dimensions from model.py) and Blender renders in media/render-*.png,
    captioned with the project, repository and viewing direction. README leads
    with the product render; trl stays 3.
    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
2026-10-01 Image quality pass: legible exploded views, flow diagrams and drawing sheets
    Kit 1.6.1 image layout: the parts list sits in its own column, number bubbles sit on visible parts and never overlap, small parts get a leader, pictures are cropped to the subject, flow labels keep numbers with their units, and sheet captions and the revision table no longer overprint. Concept images, blueprint and general arrangement sheet regenerated; repo-specific labels moved clear of other text and lines.
2026-10-01 Kit 1.7.0: constructable design, illustrated build plan and design decisions register
    The design is now constructable: every part can be made and fits its neighbours, with each change recorded in a Design for construction decision record (made under Amish's 2026-09-30 instruction; ope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
    [airstreet-assembly.step, airstreet-assembly.stl, airstreet-mount.step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]
2026-10-01 Budget treated as a value-engineering target
    Amish, 2026-10-01: the budget is a hypothetical control target that keeps the design on a value-engineering lens, not a spending limit. Documents now state the value-engineering target and the estima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
2026-10-02 Record Amish's approval of the open-decision recommendations
    Amish approved the recommendation on every open decision in the design decisions register ("i approve your recommendations for all 555 open decisions.", 2026-10-02). Each decision is moved to Decisio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
2026-10-03 Carry approved follow-ups into the design and redo photoreal renders
    Amish approved the follow-up actions from the open-decision sign-off ("APPROVED CHANGES, COMPLETE THESE", 2026-10-02), the design-for-construction change tables in ten repos, the last wave's open dec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
    [airstreet-assembly.step, airstreet-assembly.stl, airstreet-mount.step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]
2026-10-29 Kit 1.9.1 upgrade: pipeline documents and detailed CAD for every option
    STEM check with fixes under the standing instruction and an independent
    review, concept options scored against the user requirements, URS, PRS,
    RTM, REG, FEA, RSK, MKT, PLN and DDR, every option modelled at D3 with
    cad/fidelity.json passing, and the concept options picture rendered with
    Blender Cycles on Amish's Mac. Concept choices stay proposed, awaiting
    Amish.
    Claude-Session: https://claude.ai/code/session_01LppsZSzPTJWTBAV5wh1Goq

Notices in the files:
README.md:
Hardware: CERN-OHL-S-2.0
